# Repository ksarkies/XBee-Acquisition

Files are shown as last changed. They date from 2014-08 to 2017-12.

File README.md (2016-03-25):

XBee Data Acquisition
---------------------

This project develops a remote data collection board, primarily aimed at a
specific water flow meter. The board communicates collected counts of optical
transitions from a rotating slotted wheel, over an XBee network to a master
processing point. The remote unit includes a bootloader for remote upload of
new firmware.

The challenge with this project is to reduce power consumption to a minimum
to extend the life of the batteries, which may be difficult to access for
recharge in practice.

In addition to the board design and firmware, a number of tools are provided
to manage the network and collect data using Linux based hardware. These include
an acquisition coordination process that is intended to run on a small headless
Linux box such as a Raspberry Pi or BeagleBone. This manages the network and
connects to a user interface program running either on the same machine or
at another location. It uses a TCP/IP sockets interface that will allow remote
connections over the Internet.

A number of test and debug firmwares are available as well as schematics for
prototyping boards used as test nodes.

Subdirectories:

* **Documentation**:           A set of documents relevant to design and implementation.

* **gEDA-XBee-Test**:          Schematics for prototype boards for testing purposes.

* **Kicad-Main**:              Schematic and PCB for watermeter unit main board.

* **Kicad-Mounts**:            Schematic and PCB for XBee and LED mount boards.

* **watermeter-test**:         Firmware for the remote unit ATTiny481, in C, for use
 with flow bench testing over a serial interface. XBee is not used.

* **XBee-acqcontrol**:         Control software for the coordinator; in C++.

* **XBee-bootloader-M168**:    Bootloader for a remote unit with ATMega168.

* **XBee-experimental-T4313**: Bootloader for a remote unit with ATTiny4313.

* **XBee-firmware**:           Firmware for the remote unit ATTiny481, in C.

* **XBee-firmware-NARTOS**:    Firmware for remote unit ATTiny481 using the NARTOS
scheduler.

* **XBee-GUI**:                Linux PC based GUI for network control; C++ and QT.

* **XBee-node-example-M168**:  Example to send dummy message via XBee for testing.

* **XBee-utility**:            Some tools for direct interaction with XBee over a
serial interface.

K. Sarkies
29 January 2016

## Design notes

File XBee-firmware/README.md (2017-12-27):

XBee Data Acquisition Remote Firmware
-------------------------------------

This is the firmware for the remote unit. Written in C under avr-gcc.

The unit must use the lowest possible power drain, so the XBee is turned off
when not communicating, and the AVR is placed in power down sleep, to be woken
when a counter event occurs or at regular intervals for communication with the
base station.

Tasks are:

1. Manage sleep timing using the WDT.
2. Debounce and count pulses.
3. Transmit count and battery voltage.
4. Request any pending configuration instructions from the master.

The code uses an error checking protocol to ensure that data is transmitted
reliably. When woken by the WDT, it transmits the watermeter count and waits
for an acknowledgement with a checksum of its transmitted data. If no response
comes, or a response in error, or the base station reports an error, it will
repeat the transmission up to three times before giving up. Only when no errors
have been detected will it reset the watermeter count. The base station is
responsible for its own involvement in this protocol.

Provision is made for the base station to send commands to change
parameters in the remote unit. This must be sent BEFORE the acknowledgement
otherwise the remote unit will return to sleep once it has received a good
response.

The code is written to allow several AVR microcontroller types and currently
supports ATMega168, ATTiny4313 and ATTiny841, the latter being the one selected
for the watermeter.

Open source versions of avr-libc earlier than release 2.0.0 did not support the
ATTiny841 series. To get around this, either compile and install the latest
version of avr-libc, or place the latest Atmel toolchain into a directory
somewhere where it can be referenced in the Makefile. Change the DIRAVR
environment variable in Makefile to suit the location chosen.

The XBee does not use hardware flow control, although RTS may be
possible. This is due to a lack of ports on the AVR package intended for use
(ATTiny841).

**NOTE (1):** CTS should be set in the XBee and USE_HARDWARE_FLOW also enabled when
using the ATMega48 series based test boards.

**NOTE (2):** The following ports on the XBee must be set as follows:
* For the watermeter board, set pullups as 457 and pins as:
pin 4 (DIO12) output high,
pin 7 (DIO11) output low,
pins 6 (DIO10), 11 (DIO4), 16 (DIO6), 17 (DIO3), 18 (DIO2) disabled with pullup,
pin 9 Sleep_RQ input without pullup,
pin 15 Associate output,
pin 19 (AD1) analogue input without pullup,
pin 20 Commissioning output.
* For the Node Test Board, set pullups as 453 and pins as:
pin 4 (DIO12) output high,
pin 7 (DIO11) output low,
pins 6 (DIO10), 11 (DIO4), 17 (DIO3) disabled with pullup,
pin 9 Sleep_RQ input without pullup,
pin 12 CTS output,
pin 15 Associate output,
pin 16 RTS input with pullup, 
pins 18, 19 analogue input without pullup,
pin 20 Commissioning output.

The AVR is set to 1MHz for low power, and a baud rate of 9600, aimed at
giving sufficient time for processing messages.

The MCU variable defaults to the attiny841 but other versions can be passed to
the makefile:

make MCU=xxx

where xxx is either attiny841, attiny4313 or atmega168.

The makefile may need to be changed for other AVR types to adjust for
differences, and a new defines file placed in the lib directory. The makefile
creates an integer variable MCU_TYPE, derived from the MCU variable, (see the
makefile) and passes it to the source files. This variable must then be used in
the defines.h header to incorporate the appropriate MCU specific defines file.

K. Sarkies
28 November 2014

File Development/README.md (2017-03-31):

Development Modules
-------------------

All code and PCB modules used for testing at various points in the development
process is provided here. Some of these will become parts of a testbed if
production proceeds.

1. **gEDA-XBee-Test**. Circuit board schematics for prototype test versions of
   XBee remote nodes.

2. **Kicad-XBee-Test**. Circuit board schematics for the PCB version of the XBee
   remote node.

3. **socket-test**. Something to do with TCP/IP sockets for the external
   interface to the base station.

4. **watermeter-count-test**. Transmits the count at 1 sec intervals via the
   serial port in csv format. XBee not used.

5. **watermeter-echo-test**. Basic test echoes characters back on the serial
   port.

6. **XBee-bootloader-M168**. Attempt at bootloader for ATMega168 series.

7. **XBee-experimental-T4313**. Attempt at bootloader for ATTiny4313 plus early
   version of XBee code as for the XBee-node-test.

8. **XBee-firmware-nartos**. Early attempt to use a tiny scheduler for managing
   the communication protocol. Not working at this stage and probably will be
   obsoleted.

9. **XBee-node-test**. A test firmware for the ATTiny841/ATMega168 to send
   counts and battery voltage via the XBee at timed intervals.

10. **XBee-node-test-pc**. This is POSIX software to allow testing of the full
   firmware core behaviour (without any microcontroller specific hardware
   operations) aimed at verification of communications protocol in the final
   watermeter firmware.

11. **XBee-node-test-sleep**. A test firmware for the ATTiny841/ATMega168 to
   XBee send counts via the at timed intervals using sleep modes in the AVR.

K. Sarkies
19 April 2015

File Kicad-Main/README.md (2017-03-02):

XBee Data Acquisition PCB
-------------------------

Refer to [Kicad-setup](https://github.com/ksarkies/XBee-Acquisition/blob/master/Documentation/Kicad-Setup.md) in the Documentation directory for usage information.

PCB for a remote unit, including XBee with battery monitor and photodiode
counter. A major requirement for this circuit is ultra-low power to allow the
selected batteries to last for over a year.

The PCB is intended to fit inside a cylindrical watermeter with the batteries.
Due to space constraints the XBee is mounted on a separate board that sits at
right angles to the PCB. The XBee connects to an external aerial through an RF
cable. For measurement of battery voltage, a switched divider circuit is
provided for the case that the batteries provide a higher voltage than the
circuit power supply (which is sourced via a 3.3V voltage regulator). The LED is
mounted on a separate board that will straddle an interrupter wheel for counting
revolutions of the meter.

The board has a 12-pin debug connector for testing purposes:

1. Battery power or board power (if a battery is present take extreme care not
to short or connect any other power source).
2. Count signal from board comparator.
3. Reset for microcontroller.
4. MOSI microcontroller programming pin.
5. SCK microcontroller programming pin.
6. MISO microcontroller programming pin.
7. Tx from microcontroller to XBee Rx (monitor this only unless XBee is removed).
8. Rx to microcontroller from XBee Tx (monitor this only unless XBee is removed).
9. Association Signal from XBee. Blinks at 2Hz when connected to the network.
10. On/Sleep (high if XBee is awake, low if asleep).
11. Commissioning input to XBee, requiring a pushbutton to ground.
12. Ground.

The microcontroller has the following I/O pin allocations:

* PA0 (in) XBee Asleep (inv)
* PA1 (out) Tx to XBee
* PA2 (in) Rx to XBee
* PA3 (out) Sleep Request
* PA4 (in) SCK
* PA5 (in) MISO
* PA6 (out) MOSI
* PA7 (out) Battery Monitor Control
* PB0 (in) Bootloader Enable
* PB1 (in) Board Digital Input
* PB2 (out) XBee Reset (inv)

The battery monitor voltage is passed directly to the XBee as the ATTiny841 has
insufficient pins.

The TPS77033 symbol from KB1LQC.lib at Rochester Institute of technology
(http://edge.rit.edu/edge/P13271/public/KiCad/Libraries).

A photodiode symbol was taken from
(http://vkoeppel.free.fr/files/diy/kicad_diy_libraries.zip)

Other symbols and footprints are custom or are provided by KiCad developers.

The provided Photodiode.pretty footprint library should contain all necessary
footprints. Copy any legacy footprints into the modules directory, and any
external footprints into Photodiode.pretty to avoid problems of obsolescence. In
CvPcb go to "Library Tables", then select the tab "Project Specific Libraries".
Append a new entry, add the library path (including the name of the .mod file),
choosing "Legacy" for the plugin type. The nickname will then appear in the main
listing of CvPcb and the library footprints should appear. If a mistake is made,
no footprints will show, but no error message will be given until CvPcb is
restarted.

A custom footprint S1133 is provided for the S1133 photodiode. This has a
truncated circular form 8mm diameter with 6mm across the truncation, and through
hole pins. In CvPcb append a new KiCad entry and add the library path to the
.pretty directory (not the file, which is a single footprint). Also included
are some 2mm pin spacing header footprints.

The production version of the board has a custom footprint for the debug
connector to allow the option of using an SMD form. Also the photodiode is now
a BPW34 which can be either SMD or through hole mounted below the board, or a
reverse form mounted on top of the board over the square hole. The latter choice
avoids possible interference with mechanical parts in the space under the board.

The [node test firmware](https://github.com/ksarkies/XBee-Acquisition/tree/master/Development/XBee-node-test) is provided for test transmissions.

The [firmware](https://github.com/ksarkies/XBee-Acquisition/tree/master/XBee-firmware) is provided for full protocol transmissions.

Firmware must be compiled for MCU=attiny841 or whichever processor is used.

The firmware README provides instructions for setting up the XBee configuration.

* 27 November 2014: Add missing ground points. Correct error in battery voltage
  circuit.
* 24 February 2016: Changed position of connectors to avoid housing structures.
* 11 April 2016: Production version with additional XBee signals brought out to
  the debug connector which is now 12 pin.
* 12 February 2017: Corrections to the battery monitor circuit.

K. Sarkies
11 April 2016

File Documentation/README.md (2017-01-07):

**Assembly and Testing**
----------------------

1. The following procedures and tests should be carried out during or following assembly of the boards.
2. Add a blob of solder to one pin of the device to be soldered. Holding the device with tweezers, carefully melt the solder and push the device against the pad. Adjust the position of the device until all pins line up with the respective pads, leaving space on the pad for the solder to flow. Solder another pad on the opposite end of the device. Then solder in all the remaining pins.
3. On the main board solder all the passive components in the power circuit, the regulator and the debug connector. Connect to the testboard via the 12 pin cable. Connect 6V-12V power and check for 3.3V at the electrolytic capacitor, the IC power pins and at the analogue optical circuit.
4. Solder in the op-amp. This needs to be done before the AVR as the presence of the debug connector and AVR will hinder it's insertion.
5. Solder in the AVR. Connect an AVR programmer to the testboard via the 6-pin cable. Connect 6V to 12V power to the testboard (**not the programmer** otherwise the CPU on the meter board can be damaged). See the image below. This will provide 12V power to the watermeter assembly and 5V power to the programmer. Note that the programmer has 220Ω protection resistors to allow the target to have a lower supply voltage.
6. Connect the RS232 serial port on the programmer to a PC. If a serial PC port is used, invoke the program “avrserialprog -P /dev/ttyS0 -b 38400” to activate the GUI. If a USB to serial adapter is used, the port will need to be changed to /dev/ttyUSB0 (or whatever port on which the adapter appears). Check that the programmer identifies the device as an ATTiny841.
7. In the GUI click on “Lock/Fuse”, and in the window untick “Divide Clock by 8”. Ensure that the “Clock Source Selection” bits read 0010 (where 0 means unticked and 1 means ticked). Click on “Write FBs”. Do not change the clock bits to any other setting as it will risk making the AVR and hence the board unusable. This provides an internal calibrated 8MHz clock used in all tests and operational states. The 1MHz divided clock rate will not support the serial baud rate needed. Close the application and relaunch. Check that the fuse setting has indeed been changed.
8. In the optical circuit solder the passive components, the BJT and the photodiode onto the top of the board looking through. The cathode is the wide pin on the BPW-34S and this is mounted on the side facing the outer rim of the board.
9. Solder the LED mount board with the LED, and the 3-pin socket under the main board. The SFH4056 has a marking on the back with the wide end being the cathode. Mount with the narrow end, the anode, facing the pins. Place three individual pins in the 3-pin socket and solder the ends to the LED board. Check that the optical circuit produces a signal at the testboard count pin with the slotted wheel spinning and the watermeter assembly mounted in a darkened housing.
10. **The following must not be carried out if the XBee is present in the watermeter assembly as it can damage the XBee serial ports.**
    * Locate the watermeter-echo-test firmware and upload to the AVR using “avrserialprog -n -P /dev/ttyS0 -b -w 38400 watermeter-echo-test.hex -v” or through the GUI. Link the W3 jumper on the testboard. Using a serial port monitor (e.g.putty) set to the 9600 baud rate, enter characters and verify that they are echoed back to the terminal.
    * Locate the watermeter-count-test firmware and upload to the AVR using “avrserialprog -n -P /dev/ttyS0 -b -w 38400 watermeter-count-test.hex -v” or through the GUI. Link the W3 jumper on the testboard. Attach the LED board and a slotted wheel and place in a darkened housing. Using a serial port monitor (e.g. putty) set to the 9600 baud rate, spin the slotted wheel and verify that consistent counts are being transmitted by the AVR.

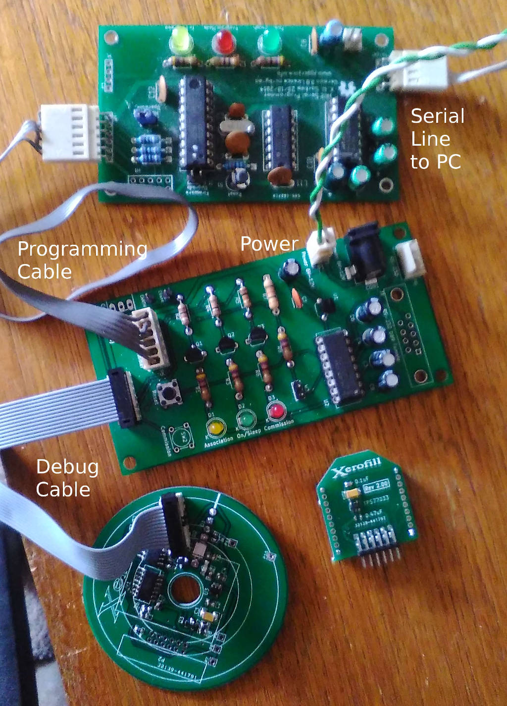
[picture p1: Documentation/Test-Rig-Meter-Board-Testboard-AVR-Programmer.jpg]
"Setup of test rig"


K. Sarkies, 07 January 2017

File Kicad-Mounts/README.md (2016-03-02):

XBee Data Acquisition XBee/LED Mountings
----------------------------------------

Refer to [Kicad-setup](https://github.com/ksarkies/XBee-Acquisition/blob/master/Documentation/Kicad-Setup.md) in the Documentation directory for usage information.

TDB: At this time the PCB has missing footprints.

This board provides a mounting PCB for the LED and a mounting PCB for the XBee
with matching connector for right-angle mount to the main PCB.

An XBee footprint was taken from RF_OEM_PARTS.lib and footprints.mod in Ian
McInerney's library (https://github.com/imciner2/KiCad-Libraries)
The legacy footprint has been modified to the newer kicad_mod format and solder
mask has been added to the pads.

The LED mount provides for two LEDs VSMY2850 and SFH4056 reverse mounted (under
the board and facing through a cutout) and a top mounted LED SFH4258.

Other symbols and footprints are provided by KiCad developers.

27 November 2014: Flip XBee over, adjust XBee footprint, reduce size the of the
                  two boards, interchange Rx and Tx.

A separate regulated supply was added to provide 3.3V power for the XBee as the
XBee can pull a relatively heavy current pulse on transmission.

K. Sarkies
19 February 2016

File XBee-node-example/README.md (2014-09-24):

XBee Data Acquisition Remote Firmware Example
---------------------------------------------

This is an example firmware for the remote unit. Written in C under avr-gcc.
The node hardware is based on the ATMega168. The hardware is defined in
gEDA-XBee/xbee-node-atmega48.sch

A dummy message is sent to the coordinator at timed intervals and PORTB0 is
toggled in the timer ISR.

The code is written to permit use of other microcontroller types and currently
also supports ATTiny4313.

The MCU variable is passed to the source in various places to allow:

make MCU=xxx

where xxx is either attiny4313 or atmega168.

The makefile needs to be changed for other AVR types to adjust for differences.
A separate defines-xxx.h file needs to be incorporated.

Currently optimization level 1 only works with this code. Other optimization
levels create faulty code.

K. Sarkies
24 September 2014

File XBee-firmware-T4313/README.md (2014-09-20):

XBee Data Acquisition Remote Firmware
-------------------------------------

This is the firmware for the remote unit. Written in C under avr-gcc.
The node hardware is based on the ATTiny4313 and is defined in
gEDA-XBee/xbee-node-attiny4313.sch

Tasks are:

1. Manage sleep timing using the WDT.
2. Count pulses: ISR and debounce procedure.
3. Transmit count, time, duration and battery voltage.
4. Request any pending configuration instructions from the master.
5. Sleep.

defines.h and makefile need to be changed to reflect differences in the
different microcontroller types.

K. Sarkies
20 September 2014

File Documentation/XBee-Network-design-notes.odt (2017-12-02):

24 May 2017

# Introduction

This describes a project to build a support base for a data acquisition network in which the communication between nodes of the network uses XBee devices in Zigbee mode.

The document describes the various design parameters and decisions, and documents the protocols and interfaces between components.

The concept involves a Linux based coordinator processor, referred to as the base station, intended to be a small headless platform such as the Raspberry Pi, BeagleBone or similar. By means of a background base station process this provides a control, configuration and collection point for incoming data via an attached an XBee in coordinator mode. It also provides a network interface to a Linux, OS/X or Windows based user interface program on the same or different machine.

The remote nodes provide the data acquisition facilities. The remote nodes can be of two types: XBee end devices and XBee routers. The latter must be always on and powered with an uninterruptible supply, while the former may be battery operated and use sleep states extensively to conserve power. As the XBee is capable of performing a small number of analogue measurements and provides basic digital I/O, it can operate as a standalone device. Alternatively, and preferably for flexibility, it can operate in conjunction with a small microcontroller. The latter configuration has a number of advantages in that each can monitor the other and provide some additional fault recovery functionality, such as remote reset, firmware uploads for the microcontroller, watchdog timer reset and remote configuration of the XBee.

Most remote nodes will use battery operation and thus they will make use of various XBee sleep states. Most modern microcontrollers can also use sleep states. As the microcontroller is likely to wake from sleep on various local events, it can also wake the XBee when transmission is required.

A number of items of software are developed for this work:

1. Base station program for monitoring, data collection and buffering, and interface to an external control program.
2. Data acquisition and control firmware for the remote node microcontroller.
3. Bootloader for the remote node microcontroller to allow firmware uploads.
4. External GUI program for connection to the base station over the Internet or local LAN, for monitoring, control and data access.

The remote node for the watermeter is described in another document.

# Xbee Setup

The XBee can be setup initially with the Digi X-CTU tool. This is available for Windows, OS/X and Linux http://www.digi.com/products/xbee-rf-solutions/xctu-software/xctu.

In Linux, the downloaded file has a .run suffix. Make executable and execute as root, eg

$ chmod +x 40002881_B.run

$ sudo ./40002881_B.run

If it is installed to the default directory /opt/Digi/, it can be run as:

$ /opt/Digi/XCTU-NG/app

Also change the ownership of the /opt/Digi/XCTU-NG/ directory and its contents to the current user.

Connect an XBee to a USB port. It will normally then appear as /dev/ttyUSB0 (although the number will be higher if other devices or disk drives have already been attached). Perform a search for the attached XBee. If not found, widen the search to different serial settings. The XBee cannot communicate its serial settings so a search must be done.

When the XBee is found, click on its entry to read all parameters. These can be changed and written back to the XBee. To change the XBee type, new firmware must be loaded.

Some debug information is available at the bottom of the parameters screen. This can indicate reasons for the XBee not joining the network for example.

## Network Setup

1. If the XBees have been set with the correct network parameters as described below, install the coordinator on a PC with X-CTU installed. Check that it is recognised and the parameters are correct. The coordinator should have
2. Connect the router Xbees to a suitable power source. Each of these should start up (connect to the network) after a few seconds. If LEDs are present, the “associate” LED (pin 15) should blink at a rate twice per second once the XBee has joined the network.
3. In X-CTU clink on the “Discover Radio Nodes” button for the coordinator entry. All nodes should be found.

## XBee Settings

These are the settings available from the X-CTU tool.

The network PAN ID is selected as 55 for this system. This is set in all XBees to be used in the network.

### Sleep Time

The coordinator and routers are set to never sleep. These must always be powered on by an uninterruptible power source. The end devices are required to sleep to conserve battery power, and cannot be set to never sleep. They may be woken from sleep via the SLEEP_RQ pin being pulsed high then low.

The sleep time setting in the coordinator and routers refers to the maximum time that end devices are expected to sleep. If an end device does not respond during this time it is purged from the list of child devices. The setting therefore must be a larger value than the end device sleep setting to ensure that the end device remains in the child table and is not expired. Any end point should wake at least once per day.

The sleep setting in end devices will be pin hibernate or cyclic sleep plus pin wake. For power reduction the sleep time must be as long as possible. For safety the cyclic sleep setting plus pin wake should be used to ensure the XBee wakes up regularly to refresh the network connectivity. The sleep options are set to allow a sleep holdoff time to be defined and to enable extended sleeping.

The maximum wake period can be set to 65 seconds. The maximum cyclic sleep setting can be set to 28 seconds multiplied by an integer that can be as high as 65535 (32 days).

When the end device XBee wakes, an setting can be used to allow it to remain awake for a fixed period to allow remote devices and processes to send any pending messages. The end device XBee must receive and respond to these messages before sleeping. The setting only applies to cyclic sleep mode and not for pin sleep mode, although it appears to be active for pin wake when pin plus cyclic sleep mode is used.

### Router

- NJ – Node join time. If less than FF the device assumes the network doesn't allow joining and attempts to rejoin. This allows it to join a network with the same PAN ID. If this fails, or NJ is FF, it joins by association.
- PAN ID – set to the selected PAN ID of the coordinator. If set to zero, the XBee will pick up the PAN ID from the coordinator (as long as only one coordinator is around).
- NW = 1. Network Watchdog Timeout in minutes to cause the XBee to check for a coordinator and leave if not found (0 is disabled). This is normally set to a higher value.
- JV = 1. Channel verification causes the XBee router to check for a coordinator on power up and search for one if not found.
- JN = 1. Join notification causes the XBee to send a node identifier packet on power up. This is needed to ensure it is entered into the software table.
- BD = 5. Set the baud rate to 38400.
- D7 = 1 Enable CTS flow control.
- D6 = 1 Enable RTS flow control.
- AP = 1 Use API mode without break characters.
- SM = 0. Set the sleep mode to disable.
- SP = 0xAF0. Set the sleep period to the maximum 28 seconds.
- SN = 0xB60. Cyclic sleep periods, up to FFFF. Set to just over 1 day.
- PR = 0x1FBF. Set the pullup resistors to exclude CTS (which is an output) and SLEEP_RQ which needs an external pull down of large value.

### End Point

- PAN ID – set to the selected PAN ID of the coordinator. If set to zero, the XBee will pick up the PAN ID from the coordinator (as long as only one coordinator is around).
- NJ – Node join time. If less than FF the device assumes the network doesn't allow joining and attempts to rejoin. This allows it to join a network with the same PAN ID. If this fails, or NJ is FF, it joins by association.
- NW = 1. Network Watchdog Timeout in minutes to cause the XBee to check for a coordinator and leave if not found (0 is disabled). This is normally set to a higher value.
- JN = 1. Join notification causes the XBee to send a node identifier packet on power up. This is needed to ensure it is entered into the software table.
- MP – Parent address (0 for coordinator, or address of router).
- NT – Node discovery backoff time (3C about 6 seconds).
- NO – Node discovery options (3).
- BD = 5. Set the baud rate to 38400.
- D7 = 1 Enable CTS flow control.
- D6 = 1 Enable RTS flow control.
- AP = 1 Use API mode without break characters.
- SM = 5. Set the sleep mode to cyclic sleep plus pin wake.
- SP = 0xAF0. Set the sleep period to the maximum 28 seconds.
- SN = 0xB40. Cyclic sleep periods, up to FFFF. Set to about 1 day.
- ST = 0x1F4. Set the sleep holdoff time to 0.5 seconds. Only for cyclic sleep.
- SO = 6. Enable extended sleep (4) and sleep for full ST time (2).
- PR = 0x1FBF. Set the pullup resistors to exclude CTS (which is an output) and SLEEP_RQ which needs an external pull down of large value.

### Coordinator

- ID – set to the selected 16 bit PAN ID. If set to zero, the XBee will pick a random number.
- SC – Scan channels bitmask for up to 16 channels. Coordinator will select a channel when forming the network. Defaults to FFFF.
- SD – Scan duration. How long the coordinator spends scanning for PAN ID or energy scan. The setting is an exponent (3) in units of 15.3ms per channel.
- ZS – Zigbee stack profile. Same on all devices on the network. This is related to specialised applications. Normally set to 0.
- NJ – Node join time. Time allowed for remote nodes to join. If set to FF it will have no time limit. After the limit has expired, remote nodes are unable to rejoin until the coordinator is reset or NJ is changed.
- OP – Operating PAN ID (should match the nonzero value in ID).
- OI – Operating 16 bit PAN ID.
- CH – Operating channel.
- NC – Number of children remaining (routers and end-points directly accessing the coordinator).
- SH, SL – Serial Number high and low.
- MY – 16 bit network address (0 for coordinator).
- DH, DL – Destination address (0000 FFFF for coordinator).
- NI – Node identifier ASCII name.
- NH – Maximum number of hops. Default 1E is about 1.6 seconds, 8 hops
- BH – Broadcast radius. For maximum number of hops set to 0.
- AR – Aggregate routing notification. Time between consecutive aggregate broadcasts.
- DD – Device type identifier (30000).
- NT – Node discovery backoff time (FF).
- NO – Node discovery options (3).
- NP – Maximum number of RF payload bytes (FF).
- CR – PAN conflict threshold (3). Not mentioned in documentation.
- BD = 5. Set the baud rate to 38400.
- D7 = 1 Enable CTS flow control.
- D6 = 1 Enable RTS flow control.
- AP = 1 Use API mode without break characters.
- SM = 0. Set the sleep mode to disable.
- SP = 0xAF0. Set the sleep period to the maximum 28 seconds.
- SN = 0xB60. Cyclic sleep periods, up to FFFF. Set to just over 1 day.
- PR = 0x1FBF. Set the pullup resistors to exclude CTS (which is an output) and SLEEP_RQ which needs an external pull down of large value.

## Unbrick XBee

The Xbees are XB24-ZB product family. To force a firmware update, use an interface board with a reset button.

1. Go to "Tools – XBee Recovery",
2. Select interface and modem type from list,
3. Select function set and firmware version,
4. Click on the "Recover" button. After a few seconds of trying to read the modem, you will get an Info box that says Action Needed. Reset the modem using the reset button on the interface board.

# Base Station

The base station processor being used for this project may be almost any Linux based PC or processor board. This interfaces to the local WiFi or Ethernet LAN to allow external control and data transmission. It may use a HDD or SD card for data buffering.

The base station is attached to the coordinator XBee.

## Configuration

The configuration of the base station processor depends rather on its hardware features. A full PC needs little configuration as it will be able to respond to almost any load demand from the network. A small processor board however may need some work to improve performance.

## Software

It is intended that the processor be set to start a background monitoring process to control the network, gather incoming data, pass it to storage buffers and interact with an Internet GUI control and display program. The program is written in C and uses libxbee3 by Attie Grande for XBee support.

The program starts by querying all nodes on the network and building a table of information for each one, including libxbee connections to allow reception of data streams from the device.

The program also sets up an Internet TCP port 58532 for connection externally by a user interface program.

The requirements for the program are:

1. On startup, initialise an Internet socket for attachment by an external user interface program. This socket shall listen on TCP port 58532.
2. For each remote node in the table, make a data connection on which incoming data for each remote node will be received.
3. Create an “Identify” connection to receive identification packets from remote nodes when they power on or join the network. Note: all stand-alone XBee nodes should have the Join Notification setting enabled to allow new nodes to identify themselves to the network. The software in the remote node microcontroller shall force the sending of the Identify packet when powering up.
4. Send out an XBee Node Discovery command via the attached coordinator XBee to query all remote nodes in the network. From the responses build a table of node information.
5. On receiving Identify packets the program shall check against the existing table and add the remote node if it is not already present.
6. Interact with the remote node via data connections, to retrieve and store transmitted data using a reliable application level protocol (see section on communication below).

## Structure

The libraries libxbee3 provide for callback functions to be invoked to deal with various message types from the XBee.

- nodeIDCallback. Callback for the ND and Identify command, to load up the node list. It is invoked when an identify packet is received. This checks for existence of the node information and adds a new node if not present. Data, I/O and AT command connections are added. If a device powers off and back on again it will be dealt with adequately by this callback. Connections are only added if the entry is not valid or is a new entry.
- dataCallback. This interprets incoming packets on the remote node data connection, and for process data passes it on to an external file. Other packets are responses to commands to the node AVR sent over the same connection. The response is stored in a global array. This should be read before any other node AVR command is sent to any node.

## Command Line Interface

When invoking the program on the base station machine, the following options are available:

-D directory to store results file (default /data/XBee).

-P port (default is /dev/ttyUSB0).

-b baudrate (default 38400 baud).

-d debug mode, printing out actions as they occur to standard output. Same as -e 1

-e enhanced debug mode: level 0=none, 1=basic, 2=enhanced.

-L starts logging and sets the logging level as used in libxbee (see relevant documents).

The program when run with the debug option will announce the results filename. The default filename will be time-stamped, but this can be overriden by the above command line option. It will then loop waiting for communication from the network. Debug information is written to /var/log/syslog.

## Internet Interface

Commands received over the Internet connection from an external user interface program have the following format:

1-byte length of message, 1-character command, 1-byte row number, arbitrary parameters (0-255 bytes)

For transmission to remote nodes, the row number points to a table entry with the node information and connections.

The commands (n represents the remote node's row number and x any parameters) are:

- Lx - send a local AT command x plus its parameters to the attached coordinator XBee.
- l - ask for any response returned by the remote node to an L command on the data connection. A value of zero returned as the first character indicates that a response had not been received. The first character of a valid response will be an ASCII 'L' to indicate that a response was received.
- Rnx - send a remote AT command plus its parameters x to the remote node n.
- r - ask for any response returned by the remote node to an R command on the data connection. A value of zero returned as the first character indicates that a response had not been received. The first character of a valid response will be an ASCII 'R' to indicate that a response was received.
- Snx - send a string x to the remote node n over its data connection.
- s - ask for any response returned by the remote node to an S command on the data connection. A value of zero returned as the first character indicates that a response had not been received within a given time. The first character of a valid response will be an ASCII 'S' to indicate that a response was received.
- N - return the number of rows in the table
- In - return the textual and numerical information in the node entry n.
- X – close down the XBee network and, after a 20 second delay, restart it. This has presented a number of issues with remote nodes not being recognised, and is not recommended to be used.
- Qn – close down the selected remote node n data, I/O and command connections, and rebuild them.
- Dn – Delete a selected remote node n from the node table.
- Ex – Create a new entry in the node table with the given 64 bit address x.
- Dn – Delete a selected remote node n from the node table.

The convention used for the commands is upper case letters to represent a direct command and a lower case letter used to request any response.

# Remote Nodes

These devices shall use sleep modes to reduce power drain to a minimum. The XBee can be placed in “pin sleep” and await the microcontroller action on a specific pin to wake it up. Alternately it can be made to wake periodically so that in the event of a non-responding microcontroller, it can force the latter to be reset. The microcontroller can also force a hardware reset on the XBee if the latter fails to respond. The microcontroller shall be placed in a sleep mode also.

## Sleep Modes

The XBee shall be set to Sleep Mode 1 (pin sleep). This allows the XBee to sleep until awoken by the action of the SLEEP_RQ pin, controlled by the microcontroller.

Note the controller and all routers must have their sleep options set to the same value or greater to ensure they retain end device messages until the latter awakes. These sleep options refer to the time allowed for end devices to remain asleep (the coordinator and routers never sleep).

The microcontroller shall be placed in sleep mode until data becomes available or until the XBee wakes it. The XBee ON/SLEEP output can be used to a wakeup the microcontroller. An AVR microcontroller shall use the power save sleep mode if the timer/counter is to be used, otherwise power down mode shall be used. Both can be woken with a pin change interrupt.

### Configuration

When configuration of the XBee is to be done, a message shall be sent to the XBee to perform the appropriate action. This must occur when the XBee is woken by the remote node microcontroller.

To account for the case where the AVR hasn't been given the ability to change the XBee sleep state, an XBee command will need to be sent by the controller to change the sleep mode to pin sleep. The XBee will then need to have its SLEEP_RQ pin grounded to ensure that it remains awake indefinitely in this mode. The XBee end devices cannot be set to remain permanently on, and must use one of the sleep modes.

### Bootloader

The need to reset the AVR when activating the bootloader results in the SLEEP_RQ pin of the XBee being forced high during the reset, as all I/O ports on the AVR are changed to inputs. This puts the XBee to sleep and cuts off communication. To overcome this, a 1M or larger resistor is used as a pull-down and the pull-up on the XBee SLEEP_RQ pin is disabled.

# Communication Protocols

On top of the Xbee networking protocol is needed a specific application protocol to communicate between the remote node microcontroller and the base station process. This shall be done by means of a command/response mechanism consisting of a command or response code word possibly followed by data. A code word that doesn't belong to the following list shall result in an error response.

The protocol shall consist of an ASCII command character followed by a string of ASCII hexadecimal characters representing numerical data, or other ASCII characters representing non-numerical data.

## Bootloader

The following commands apply to interaction with the bootloader only.

- : (semicolon). The following data shall be a single record of iHex formatted hexadecimal characters, pairs of which represent a data byte, and having maximum length 16 data bytes. The record types 00 and 01 (end of file) are recognised. Error responses include invalid hex character, checksum, record length and record type.
- Q. Quit the bootloader and enter application program at address zero.
- X. Erase all application memory.

Responses

- Y no error.
- E unspecified error response.
- B out of bounds (bootloader has been asked to write over itself).
- L invalid iHex record length
- H invalid hexadecimal character
- X invalid checksum
- I invalid command (including invalid data where appropriate)
- J a jump to the application has been made from the bootloader.

## Base Station to Remote Node Interactions

As specified above, in the remote node, both the microcontroller and the XBee will sleep. The microcontroller will wake at intervals and will then wake the XBee to check for waiting messages and to send data. Regardless of any data to be sent the base station must receive a message from the remote node and respond. Then the remote node may return to sleep.

For safety the remote node must wait for a limited period of time for a response, and resend the message if no response has been received. The following protocol shall be followed to improve the reliability of communication in the presence of possible errors.

If no response has been received, then the remote node may check the XBee for valid status, to determine if it is still joined to the network. If not, then the XBee shall be restarted. Otherwise the remote node shall return to sleep on the assumption that the network is not responding. Accumulated data shall be retained for subsequent attempts.

## Data Transfer Protocol

A reliable protocol is required to ensure that the collected data is transferred accurately to the system.

If data is transferred correctly, then the old data must be cleared to make room for a new set.

### Protocol

Successful error recovery requires careful design. However it is not possible to anticipate all possible errors. These can arise from corruptions in the communications at the Xbee-AVR interface, or in the XBee network itself.

The protocol in summary is as follows. More detail is given in the flowcharts.

- When the XBee is ready to send, wake up and send a contact message with the collected data and a checksum.
- Receive an acknowledgement, or negative acknowledgement if data was received in error by the base station.
- If timeout, repeat the contact message until the acknowledgement is received or until three attempts have failed.
- If any other error occurs, resend the data message up to three times.
- On failure send a signal to indicate that the results should be discarded.
- On success, reset the data and send a signal to store the result.

The length of the data field can be inferred from the message length. All fields shall consist of printable ASCII characters for readability and error checking. Because of limited memory in the AVR, the messages shall have limited length.

If the remote gives up, then it shall send a final message stating that it is giving up and will not reset the count. The base station shall discard the result if it has not received a definite acknowledgement. This protocol will never guarantee that data will not be lost, but will cover most situations.

### Message types

The messages from the XBee contain the data to be sent. xx represents checksum, aa represents data:

1. 'C' xx xx aa aa … (11 bytes) Original message with application data.
2. 'E' xx xx aa aa … (11 bytes) Repeat message in response to reception errors.
3. 'N' xx xx aa aa … (11 bytes) Repeat message in response to a NAK.
4. 'T' xx xx aa aa … (11 bytes) Repeat message in response to a timeout.
5. 'S' xx xx aa aa … (11 bytes) Repeat message in response to a status frame.
6. 'X' (1 byte) Remote will abandon the communication attempt.
7. 'A' (1 byte) Remote agrees that the communication is successful.
8. 'D' aa aa … (unlimited bytes) Debug message.

The messages from the system to the XBee are:

1. Acknowledgement: 'A' (1 byte).
2. Negative acknowledgement: 'N' (1 byte).
3. Parameter change command: 'P' aa aa ... (n+1 bytes).
4. Keep awake until further notice: 'W'.
5. Sleep: 'S'.

Any additional commands to the XBee must not use 'X' or 'N' as these will be confused with the ACK and NAK messages.

## Parameter Change Command

If a parameter change operation is required, the parameter change command must be transmitted by the base station immediately after the reception of the data command. This will ensure that the operation takes place before the remote node returns to sleep.

The remote node must respond with an acknowledgement of the parameter change command.

## External Interface

The best place for the external interface is in the base station. Data can be collected during the message exchange and stored ready to pass to an external PC. All that is needed for configuration is the way that data is stored for each sensor.

Data storage shall be made firstly in a global data structure that contains only one result for each of the remotes in the network. Following a signal from a remote that the data transmission is successful, the result will be written to a permanent data file. The temporarily stored datum will be overwritten by subsequent transmissions, therefore if the acknowledgement was not received from the remote, the datum would be lost. To avoid this loss, the old datum shall be written to the file with a marker indicating that its status is dubious.

# Software Development

## Base Station

The base station program is intended to be run on a Linux machine which can range from a single card computer such as the Raspberry Pi to a full PC. Most likely a low to medium range PC can be used as the performance demands would not be very great.

The base station program is not intended to interface to a user. Rather it communicates via an Internet socket with an external user program such as the XBee-GUI program described below.

The program is developed in C and uses only standard POSIX libraries plus the libxbee libraries created by Attie Grande. The latter must be installed in a suitable location and compiled to produce a libxbee.a archive file. If the system install procedure has not been used as described in the libxbee documentation, then libxbee.a must be copied along with the xbee.h file to the base station program source directory. The base station program can then be compiled using “make” to produce a xbee-acqcontrol executable.

When the xbee-acqcontrol program is run from the command line, it produces a one-line output and then waits for responses from the Xbee network and the user interface program. Error messages are printed to the /var/log/syslog file, labelled clearly as originating from the base station program. Typical errors that cause the program to end prematurely might be unable to open a file for printing of remote node results messages. If the debug setting is used when compiling, the program will also print to stdout. If the network is operating correctly messages should be seen from the remote nodes.

Command line options for xbee-acqcontrol are

-d directory to store results file

-P port (default is /dev/ttyUSB0)

-b baudrate (default 38400 baud)

## XBee-GUI

The GUI program is developed in C++ using the QT4 graphical libraries.

### Linux Installation

For Linux use, the following QT4 development libraries should be installed: qt4-designer, qt4-dev-tools, qt4-doc, qt4-qmake.

The program otherwise only uses the standard POSIX libraries.

Build the program with

- qmake
- make clean
- make

### Windows Installation

For development or compilation, download the QT opensource version 4.8.4 for Mingw 4.4 (http://qt-project.org/downloads). Install to its default folder .

Download the Mingw install GUI (http://www.mingw.org/wiki/Getting_Started). Also install to its default folder, as that will be used by default by QT. Copy the source files for XBee-GUI to a folder C:\XBee-GUI. From the start menu, open the QT 4.8.4 command prompt in the QT by Digia v4.8.4 entry. In the window, change directory to C:\XBee-GUI and issue the commands:

- qmake
- make clean
- make

The executable will appear in the “release” folder. To make it distributable, add copies of the following files found in the MinGW\bin and QT\4.8.4\bin folders:

- libgcc_s_dw2-1.dll
- libstdc++-6.dll
- mingwm10.dll
- QtCore4.dll
- QtGui4.dll
- QtNetwork4.dll

The resulting set of files can then be bundled into a zip file for distribution and should run on any Windows 7 installation without additional actions needed.

## Remote Node Firmware Arduino Development

For development of code on the remote node microcontroller it may be sufficient to make use of the Arduino IDE without the upload feature. This needs to be modified to ensure that the Intel iHex formatted binary file appears in an accessible place and is not deleted. To the Arduino IDE preferences configuration file (this file can be found as described in http://arduino.cc/en/Hacking/Preferences) add the following lines:

export.delete_target_folder=false

build.path=build

The former prevents deletion of the generated build files, and the latter places all build files into a local directory called “build”.

Once the hex file is available it can be uploaded using the XBee-GUI program.

## Bootloader for ATMega88/ATMega168/ATMega328

The bootloader is useful for updating the firmware in FLASH memory over the radio link. It shall sit in the allocated bootloader area of memory. On reset the microcontroller will start in this region automatically. The bootloader shall test the XBee bootloader output. If active, it shall wait for commands on the data channel to clear the Flash memory program area and to program pages of instructions. Otherwise it shall jump to the start of application code.

The bootloader must perform necessary hardware initialisation. For AVR devices this means disabling the watchdog timer (which remains enabled after a hardware reset).

The firmware data format shall be Intel iHex, which is compatible with many linker outputs. Reception of an iHex line will result in a block of data being programmed to Flash. Since an iHex line starts with a colon, that character will be taken as a command to program the line. A small number of other commands may be used to allow some additional functionality if space permits. The maximum length of a line shall be 16 byte of data.

As mentioned earlier, the bootloader will test the chosen bootloader output pin of the XBee at intervals and will jump to the application area if it is active.

Once a command to load memory has been received, the relevant memory block will be erased. A lock variable shall be set to indicate that this has happened as it must not be done again for the same block.

Because of the limited memory in the bootloader region, code shall be optimised for size.

The serial interface with the XBee should support flow control to take advantage of buffering in the XBee itself. This allow the bootloader to perform the lengthy erase and write operations with reduced probability of loss of frames. The protocol used in the base program should repeat frames if a negative acknowledgement is received.

The Bootloader requires close to 2K of FLASH, so the selected microcontroller will need to support this.

## Bootloader for ATTiny and ATMega48

These AVRs do not have a separate bootloader region and therefore the process of programming the FLASH over the radio link becomes more complicated.

The XBee can produce a digital output that can be used to reset the AVR and also specify that a bootloader block be entered. At the start of the program, test for the bootloader demand signal and jump to the bootloader if it is set.

## Remote Node Firmware

The microcontroller application shall make use of a data communication channel to transmit acquired data to the base station. The software must perform the following functions:

1. The microcontroller application shall implement regular timed sleeps, to be woken either by an external event or after a given time. When it wakes it may wake the XBee also, and transmit a status message to the base station as part of the data connection. The XBee need not be woken if only count events are occurring.
2. The microcontroller application shall implement a command interface to allow the base station to make configuration changes.
3. For timed A/D measurements, use a timer to wake the AVR and perform A/D conversions and other polled input measurements. Configuration settings will be used to select which of these is activated, if any. It may be preferable to use the XBee to perform the analogue conversions as it has its own internal reference voltage. If no ports are identified to provide measurements, the interrupt is disabled.
4. The AVR is set to wake the XBee regularly, as required to ensure continuity of connection to network XBee routers. It will then transmit any measurements made in the interim, if any.
5. Set the watchdog timer to a given (configurable) value. When it fires, check the XBee and wake it up. Check the communication with the base station. If failures occur, reset the XBee. This may result in a NI (node identify) message being sent by the latter.
6. Bootloader for firmware upgrades to be sent over the air. The XBee shall provide two outputs, one to reset the microcontroller and the other to indicate to the bootloader to wait for programming instructions (rather than jump directly to the application). The bootloader shall regularly test the XBee bootloader output and effect a jump to the application when it is deactivated.

Configuration settings:

- Configure ports to convert analogue signals.
- Configure ports to read digital signals.
- Configure frequency of polled measurements.
- Enable the counter measurements by pin change interrupt.

### Definitions

- txStatusReceived: boolean indicating that a status frame with delivery status information has been received from the base station.
- txDelivered: boolean indicating that the base station acknowledged successful receipt of a transmission (in terms of frame integrity and checksum).
- cycleComplete: boolean indicating that the protocol cycle has ended successfully or has been abandoned.
- transmit: boolean permitting a data transmission to be made to the base station.
- retry: Number of retries already made to try to get a successful base station response A maximum of three tries is preset into the firmware.
- messageState: the current state of reception of a frame. This increments as each stage of the message is parsed:
  - 0: no meaningful reception has occurred.
  - 1: a 7E frame sync character received
  - 2,3: message length high and low bytes
  - 4: frame type: 0x90 data frame or 0x8B status frame.
  - >4: remainder of message; length less 3 bytes.
- messageStatus: a byte representing the status of the message
  - NO_DATA: nothing received,
  - CHECKSUM: error detected,
  - COMPLETE: a message has been completely received and has the correct format.
- timeResponse: a timeout counter used to track non-reception of a base station response.
- packetError: boolean indicating that the packet received is errored or unexpected.
- packetReady: boolean indicating that the packet received is ready to be processed.

### Data Transmission Protocol Implementation

The data transmission protocol is designed to minimize the probability that any data will be lost. When the remote sends data it will clear the count once it has been convinced that the base station has received it correctly. The base station will store the count when it is certain that the remote knows it has been received.

In any part of this protocol the base station will reject the communication if it has not successfully completed.

In the event of messages not being received by the base station, a timeout will be implemented to prepare the base station for the next transmission from the remote. This timeout period must be longer than the longest time that the remote needs to complete the protocol, even in the presence of errors or missing messages. This is essential as the next transmission session can be confused with the current session in certain instances.

Initial remote data transmission

The network protocol starts with transmission of a data packet from the remote with command C plus counts from the watermeter sensor. There are three outcomes:

1. If after three attempts the message is not delivered (as given by delivery failure status messages via the coordinator XBee) then the session is abandoned. The counts are retained and accumulated over the following period.
2. A timeout while waiting for a response from the base station. The message is repeated up to three times by the remote using a T command. If no response is received then an X status command is returned indicating that the attempt is being abandoned. If the base station is not receiving messages from the remote it will abandon the session anyway and not record any data. If it is receiving messages but the remote is not receiving its responses then the X status command will definitely terminate the session. If the base station doesn't receive the X status command then it will abandon the session and not record the result .
3. The message is delivered. The base station is expected to reply with a data message containing N (NAK) calling for a repeat, or A (ACK) indicating success.

Base station response to faulty received data command

The base station sends an N (NAK) command if it detects a data message with a checksum or message length error. The remote then repeats the original message but using an N command to indicate to the base station that is has been repeated as requested.

1. If the N command is not correctly received by the remote it will ignore it. The timeout procedure will then take effect.
2. After three failed requests for repetition, the remote will abandon the session and send an X status command.
3. The base expects either a repeated message or an X status command. If neither arrive the base must abandon session and not record the result.

Base station response to unknown message

If the base station receives a message from the remote that it doesn't recognise, it simply ignores it. This should then trigger a timeout and retransmission in the remote.

Base station response to successfully received data command

In this case the base station sends an ACK command.

1. The remote is expected to respond with an A command indicating agreement has been reached between both sides. As this is the only response expected at this stage, the base will accept any corrupted data message as an A command.
2. If the A command isn't received then the timeout process will be invoked.
3. The protocol will fail if the final A command sent by the remote reaches the base station but is misinterpreted as not being a data command. In that case the remote will delete the collected counts but the base station will not record them.

To reduce the probability of failure the A command from the remote can be transmitted a number of times. There will be no feedback from the base station.

Remote response to faulty received status command

If the status command from the base is faulty, the remote repeats the original data message as an E command to indicate that it didn't understand the base station's response as either an A or N command. The base station will then repeat the previous status command or, if the newly received message is received correctly, an A command. If this fails after three attempts, an X command is sent to abandon the session.

The base station is not required in this design to perform any form of error recovery by retransmission. This would complicate the protocol without adding much value. It is important to note that the decision at the final acknowledgement stage to accept any data response from the remote as a valid acknowledgement, will be the key to reducing the probability of failure. Otherwise if only an A command is acceptable, then the probability of failure will be no different to a simple transmission of the data count. This requires the base station to be aware of the protocol state.

In extreme error situations it is possible for the protocol to not complete a cycle. The protocol state is automatically reset when a data command of any type is received to avoid confusion. The previous cycle is then aborted by the base station.

In addition to the protocol process there is a need to send commands to the remote from an application layer. These must be sent only when the data transmission protocol has completed its cycle, otherwise the command and responses may interfere. The remote firmware will nevertheless attempt to recognise such commands if they occur.

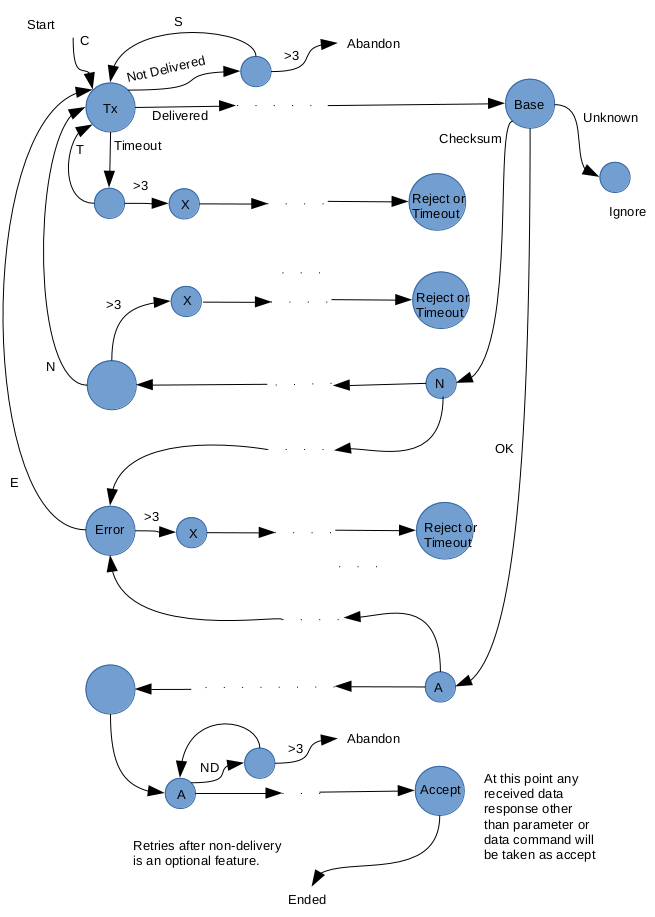
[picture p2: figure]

Illustration 1: Network flow diagram for data transmission protocol.

### Pseudocode

Pseudocode for the firmware :

1. Loop 1. Outer.
  - sleep until interrupt. Wake on count or WDT interrupt.
2. Loop 2.
  - set lastCounter = counter and wait 1ms. If count hasn't changed, drop out.
  - if WDT counter has reached the preset time, initiate transmission sequence.
3. Loop 3.
  - send C transmission of data (counts).
  - continue looping while waiting for the cycle of communication to complete.
4. Loop 4
  - Wait for a message to be received.
  - Count up timeResponse if nothing comes.
  - messageStatus indicates where we are in reception and if errors occurred.

Once this set of code has completed, the processing phase will begin using the booleans txStatusReceived, txDelivered, cycleComplete, packetError, packetReady to determine actions to be taken.

messageStatus

COMPLETE

- XBee receive frame has data. Copy and set packetReady = true.
- XBee status frame. This will indicate if the transmitted frame was received.

NONZERO (error)

- XBee receive frame has data. Discard.
- XBee status frame. Assume delivery occurred.

TIMEOUT awaiting status.

- Assume received but not delivered correctly.

TIMEOUT awaiting base station response.

- Signal a timeout has occurred.

Transmission delivered

- response received from base station. Look into contents of response.
  - NAK. Continue up to three times, then return an N message.
  - ACK. Adjust counter by subtracting the number already sent, and finish.
- response errored. Continue up to three times, then return an E message.

Status indicates not delivered

- Continue up to three times, then abandon whole process.

Status indicates timeout occurred

- Continue up to three times, then return a T message.

A message arrives outside the transmission protocol, that is, independently of the txStatusReceived and txDelivered messages that refer to a previous transmission. Interpret as a higher level application message.

Finally if the retry limit has been exceeded, return an X command indicating abortion of the transmission attempt. A new transmission will be attempted next period with previous period counts included.

Otherwise send acceptance.

### Flowcharts for remote protocol process

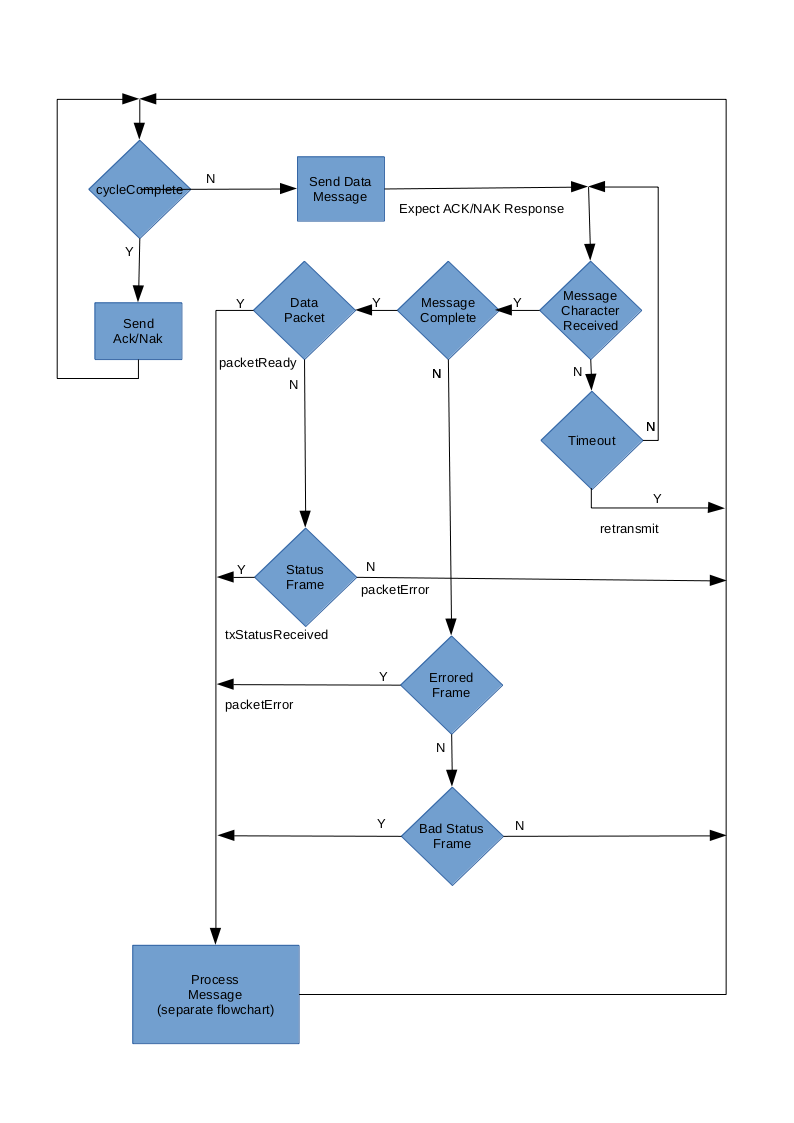
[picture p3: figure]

Illustration 2: Flowchart for detection of messages.

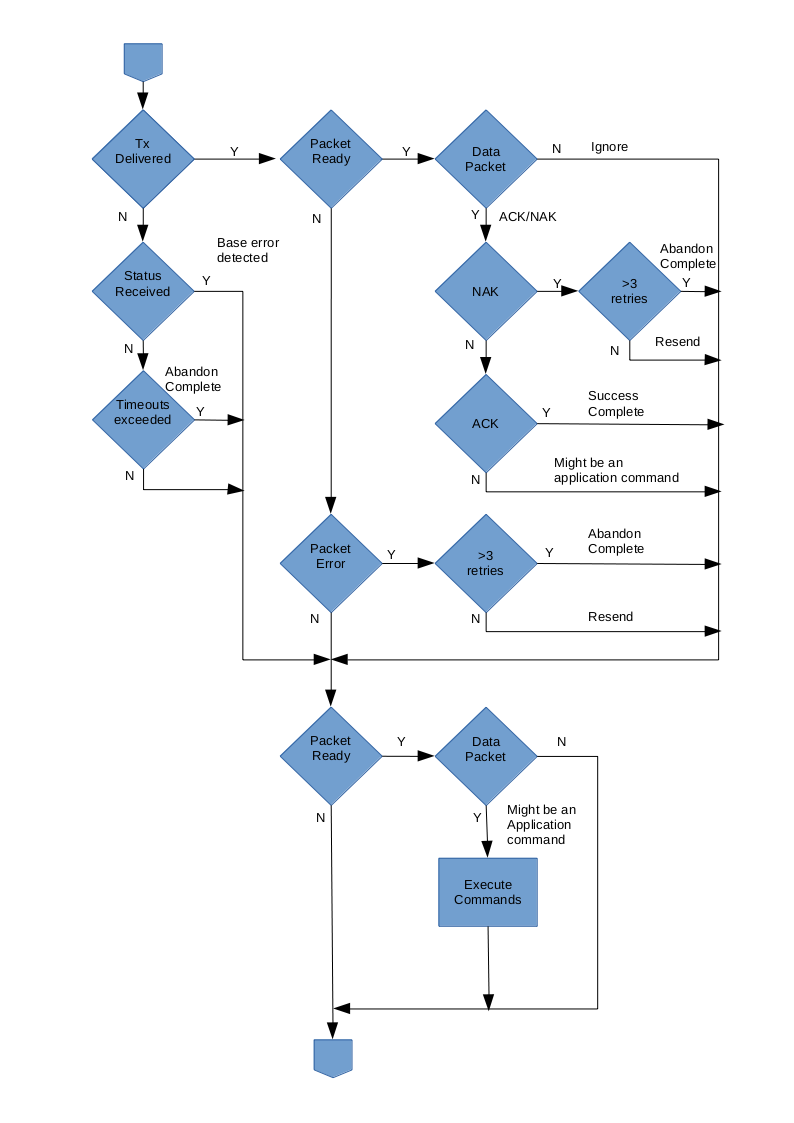
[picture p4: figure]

Illustration 3: Flowchart for processing of messages.

### Firmware for Watermeter

This has a very low power requirement. Since the only measurements are counts, the firmware uses a slightly different approach for managing sleep and interrupts. See the watermeter document.

## Testing of Firmware

The tests must verify that the protocol is able to handle all error conditions and ensure delivery of the counts accurately. Any network error conditions may result in the remote node and the base station having different ideas about what data was communicated.

There is only a limited debugging capability in the AVR microcontrollers so code may be verified by running it on a Linux machine and setting the AVR specific instructions to stubs. This then communicates with an XBee mounted on a board with a serial interface. The code being run may provide extensive debug printout. The procedures for doing this are described in the next chapter.

Testing on the AVR itself is somewhat more challenging. All behaviour must be determined from the messages received by the base station.

### Error free test

Set debug printout in the base station software and the PC simulator software if used.

- Remote node wakes and sends a count data message.
- Receives an XBee status frame with successful delivery.
- Receives a data message with 'A' acknowledge.
- Returns an 'A' message to complete transfer.
- XBee status frames after that are ignored.

### Message received in error by base station

This can be simulated in the base station by changing the 'A' message sent back to 'N', or by signalling a checksum error.

- Remote node wakes and sends a count data message.
- Receives an XBee status frame with successful delivery.
- Receives a data message with 'N' acknowledge.
- Resends the original transmission.
- Repeats three times.
- Returns an 'X' message to complete transfer and signal abandonment.
- XBee status frames after that are ignored.

### Base station acknowledge lost

This can be simulated by changing the firmware code to ignore the acknowledge. It can happen in the watermeter due to delay in reading the XBee serial port when an interrupt occurs.

- Remote node wakes and sends a count data message.
- Receives an XBee status frame with successful delivery.
- Timeout waiting for the acknowledge.
- Resends the original transmission.
- Repeats three times.
- Returns an 'X' message to complete transfer and signal abandonment.

XBee status frames after that are ignored.

### Base station acknowledge excessively delayed

This can be simulated in the base station by adding a 200ms or 500ms sleep before sending the acknowledge. If the remote is able to receive the 'A' message after any status frame from repeated transmissions, and before the third timeout retry, then the original transmission will be accepted by the base station. In the test performed, the 200ms sleep resulted in the 'A' message arriving at the remote before the status frame and the following sequence occurred.

- Remote node wakes and sends a count data message.
- Receives an XBee status frame with successful delivery.
- Timeout waiting for the acknowledge.
- Resends the original transmission.
- Acknowledge arrives before the transmission status frame. This is treated as an out-of-protocol application message.
- Repeats three times.
- Returns an 'X' message to complete transfer and signal abandonment.
- XBee status frames after that are ignored.

### Extreme range tests

At extreme range the XBee communications will typically drop out over a short distance and all communication will be suspended. The protocol response to this and to errors that occur just on the limit of range must verify that data is not lost. Note that the base station may have a much higher transmission power than the nodes, and therefore the nodes may receive clear responses from the base station, while the base station may receive errored or missing remote messages.

# Module Testing

A number of test hardware and software modules are provided.

## Remote Node with ATMega48

The board is a standalone board comprising:

- an ATMega48 microcontroller,
- an XBee,
- Red LED for power,
- Yellow LED for XBee associate signal,
- Green LED for microcontroller test signal,
- screw connector for digital counter signal input,
- screw connector and trimpot for analogue signal input.

It accepts 5V power and drops this to 3.3V for the XBee.

The board schematic is given in Development/gEDA-Xbee-Test as xbee-node-atmega48.sch.

The following connections are made:

- XBee CTS pin 12 connected to ATMega48 pin 4 PD2,
- XBee RTS pin 16 connected to ATMega48 pin 5 PD3,
- XBee Reset pin 5 connected to ATMega48 pin 19,
- XBee Sleep_RQ pin 9 connected to ATMega48 pin 17 PB3,
- XBee On/Sleep pin 13 connected to ATMega48 pin 18 PB4,
- XBee Microcontroller reset pin 4 DIO12,
- XBee Bootloader D11 pin 7 connected to ATMega48 pin 16 PB2,
- XBee AD1 pin 19 connected to ATMega48 pin 24 ADC1 and Battery Monitor signal,
- XBee AD2 pin 18 connected to ATMega48 pin 23 ADC0 and Analogue in,
- Counter input connected to ATMega48 pin 11 PD5.

## Remote Node with ATTiny4313

This has only been built on a prototyping layout and has not been used to any extent. Other than the processor change and the lack of an A/D port (since the ATTiny4313 doesn't have an A/D converter), it is the same as the ATMega48 board.

The board schematic is given in Development/gEDA-Xbee-Test as xbee-node-attiny4313.sch.

## Remote PC Attached Node

This is a board designed to use a serial RS232 connection directly to the XBee so that a PC can be used to emulate the microcontroller in a node. The board comprises:

- an XBee,
- Red LED for power,
- Yellow LED for XBee associate signal,
- Green LED for on/sleep signal,
- Orange LED for Sleep_RQ signal,
- RS232 converter,
- Reset momentary on button,
- Force sleep_RQ toggle switch,
- Commissioning momentary on button.

It accepts 12V power and drops this to 5V for the RS232 converter and 3.3V for the XBee.

The board schematic is given in Development/gEDA-Xbee-Test as xbee-node-serial.sch.

## Watermeter Board

This is the production module. The following connections are made:

- XBee_reset pin 5 connected to ATTiny841 pin 5 PB2,
- XBee Sleep_RQ pin 9 connected to ATTiny841 pin 10 PA3,
- XBee On/Sleep pin 13 connected to ATTiny841 pin 13 PA0,
- XBee Microcontroller reset DIO12 pin 4,
- XBee Bootloader DIO11 pin 7 connected to ATTiny841 pin 2 PB0,
- XBee AD1 pin 19 connected to Battery Monitor signal,
- Control pin for enabling Battery Monitor ATTiny841 pin 6 PA7,
- Counter input connected to ATTiny841 pin 3 PB1,
- XBee associated and commissioning signals are not connected to the ATTiny841.

## Node Test Firmware

Firmware for testing a node can be found in Development/Xbee-node-test (xbee-node-test (https://github.com/ksarkies/XBee-Acquisition/tree/master/XBee-node-test)). This transmits a single message at regular intervals consisting of a D followed by an integer count value taken from the digital counter input on the board. If compiled for ATMega48 it will use a baud rate of 38400, while for the ATTiny841 on the watermeter board it will have a baud rate of 9600.

The libs directory contains board definitions which define the capabilities of each board and processor and the various pin allocations.

The serial port definitions in defines-M168.h, that are relevant to this ATMega48, require that CTS be enabled on the XBee for DIO7. This is to allow for the eventual development of a bootloader. The board rate is set at 38400.

The serial port definitions in defines-T841.h, that are relevant to the watermeter board, require that CTS be disabled on the XBee for DIO7. There are no hardware flow control signals passed back to the microcontroller from the XBee. Also the baud rate is set to 9600 to ensure accurate communication with the mirocontroller.

## PC Based Emulated Node Test Firmware

This is a POSIX system based test code for an XBee remote unit. Written in C but embedded in a QT/C++ wrapper which emulates the environment for the test code. It can be run with any adapter interface board that contains a USB-serial converter, or with a board having a serial interface plus an external USB-serial converter. The emulator is not an AVR emulator. Rather it provides a means to run the Xbee firmware core on a PC for debugging. It is not possible to drive or sense any of the hardware pins on the XBee, so sleep modes are not possible.

The code can be found in Development/Xbee-node-test-pc (xbee-node-test-pc (https://github.com/ksarkies/XBee-Acquisition/tree/master/XBee-node-test-pc)).

There is also a non-GUI C version of the emulator that will run on micro computer boards such as the Raspberry-Pi and the BeagleBoards where QT is not simple to install.

The purpose is to provide a PC Linux based testbed for emulating remote system firmware that is capable of communicating directly with an XBee over a serial port, and working as a remote unit.

NOTE: gcc is required to allow function override for timerISR.

The program can be run without a GUI from the command line with the -n option. A debug mode is available for extended printout.

$ xbee-node-test -d -P /dev/ttyUSB0 -b 38400 -n

In command line mode, the program can only be stopped by ctl-C or process kill.

The following main program modules allow different tests to be run. Change the XBee-node-test.pro file to compile the different tests.

### mainprog-test.cpp

This is adapted from the xbee-node-test (https://github.com/ksarkies/XBee-Acquisition/tree/master/XBee-node-test) code and performs the same functions as the node test firmware.

### mainprog-firmware.cpp

This is adapted from the xbee-firmware (https://github.com/ksarkies/XBee-Acquisition/tree/master/XBee-firmware) code and emulates the full production firmware. This must be modified to reflect changes in that firmware.

### Adaptation to Other Test Code

The following files may be used as the environment emulator for other code tests with appropriate adaption of the .pro and mainprog.cpp files:

- xbee-node-test-main.cpp
- xbee-node-test.cpp
- xbee-node-test.h
- xbee-node-test.pro
- xbee-node-test.ui
- serial.cpp

serial.cpp is a substitute set of communication functions calling on POSIX/QT serial I/O. This should contain functions that match the calls in the test code.

mainprog.cpp must be provided with the code to be tested in the following way:

Split the code to be tested into an initialization part and an operational part that normally falls within an infinite loop. Place the initialization part into the function called mainprogInit(), and the operational part into mainprog(). Both these are called from the xbee-node-test.cpp wrapper, with the operational part having its loop emulated in the wrapper code.

There should be no compilable processor specific statements. These can be replaced by a call to a local function that should contain code to emulate the statement. If this is not possible then the code is not suitable for testing in this way.

Add all global variables as static. Add also any include files needed. These should not contain references to any processor specific libraries or functions.

ISRs need to be changed to a function call and means to activate them devised. A timer is emulated in the emulator code. Timer initialization is done by calling an initialization function in the emulator code. This function sets the number of one millisecond tick counts at which the timer fires and calls the ISR. If a timer ISR is not defined, a null ISR is substituted. The timer ISR can be defined in the test code by replacing the actual ISR call with the function: timerISR().

xbee.cpp is a file associated with the code under test, which has been copied from the library directory with its extension changed from c to cpp to satisfy the g++ compiler (otherwise it is not correctly linked).

### Watermeter Count Test

This is a test firmware for the AVR in the watermeter. Written in C under avr-gcc.

The code can be found in Development/watermeter-count-test (watermeter-count-test (https://github.com/ksarkies/XBee-Acquisition/tree/master/watermeter-count-test)).

This test transmits the count of the photointerrupter at regular intervals (1 sec) via the serial port at 9600 baud in csv format for capture and analysis off-line. This link is normally connected to an XBee in the watermeter assembly. The test can only be used where the XBee is not present and the serial link is brought out to a PC serial port.

### Watermeter Echo Test

This is a simple test firmware for the AVR in the watermeter. Written in C under avr-gcc.

The code can be found in Development/watermeter-echo-test (watermeter-echo-test (https://github.com/ksarkies/XBee-Acquisition/tree/master/watermeter-echo-test)).

This test simply echoes characters back on the serial port at 9600 baud. Use to verify that the serial link to the AVR is working. This link is normally connected to an XBee in the watermeter assembly. The test can only be used where the XBee is not present and the serial link is brought out to a PC serial port.

# Testing

## Firmware Debug Tests

The protocol requires extensive testing to ensure that the system recovers correctly from errors. Make use of the Development/Xbee-node-test-pc/emulator-* emulators. The following shows the emulator output from:

$ xbee-node-test -d

END device present. Normally there should be an 8B (Tx status frame) and 90 (data frame containing the ACK). Often there is an 88 frame apparently left over from a previous association query but this is rightly ignored.

New Cycle

Transmit Command C , Last Count 0

Message Type 88, Length 15

Packet error detected: Type 88, Length 15

Unknown Frame: data contents 3 49 53 0 1 18 0 3 10 0 2 14 2 12

New Cycle

Message Type 8b, Length 7

Zigbee Transmit Status Frame: data contents 2 0 0 0 0 0

Delivery Status? 0 delivered

Delivered, start processing

Normal Zigbee Transmit Status Frame from local XBee

New Cycle

Message Type 90, Length 13

Got a data frame: reply A, data contents 0 b0 30 a5 8c fc 7f 0 0 b3 57 cc

Delivered, start processing

Process Packet ready to check for ACK/NAK

ACK

Finished Cycle

Accepted

From the Coordinator output:

$ xbee-acqcontrol -d

Node END-13 Data Packet: Time 2017-02-07T10:20:39 length 11, data CFE03FF0000

Command Received C Count 0 Voltage 4.909802 V

Sent ACK

## Operational Tests

The coordinator software may be run in debug mode using the -d or -e x options, where x is a debug level 0-2. This will provide verbacious teminal output concerning the received and transmitted signals. For example:

Node END-14 Data Packet: 2017-03-14T00:43:00 A16: C7AE A64: 0013A2004089DEBC length 11, data CFC03FF0002

Command Received C Count 2 Voltage 4.909802 V Retry 0

Sent ACK

Transmit Status: 2017-03-14T00:43:00 Length: 6 FrameID 20, 16 Bit Address C7AE, END-14 Retry count 0, Delivery status 0, Discovery status 40

Node END-14 Data Packet: 2017-03-14T00:43:00 A16: C7AE A64: 0013A2004089DEBC length 11, data TBC43FF0002

Command Received T Count 2 Voltage 4.909802 V Retry 1

Sent ACK

Transmit Status: 2017-03-14T00:43:01 Length: 6 FrameID 21, 16 Bit Address C7AE, END-14 Retry count 0, Delivery status 0, Discovery status 40

Node END-14 Data Packet: 2017-03-14T00:43:01 A16: C7AE A64: 0013A2004089DEBC length 1, data A

This shows a reception of a data packet from END-14, that is interpreted as a normal C command carrying battery voltage and meter count. An ACK signal is sent back. The Transmit Status message indicates a delivery status of 0, which represents success. However the remote has not apparently received the message and returns a second data packet with a T command indicating that a timeout occurred waiting for the ACK. The data content is identical to the earlier message. Another ACK is sent and this time there is no further response from the remote. At this point the protocol assumes that the transmission is successful otherwise it would have received a second timeout message.

The timeouts should not normally occur. At this time, the cause of this behaviour is unknown.

The coordinator should be able to handle as many as 25 remotes with a 125 second interval between transmissions. The transmissions should be handled correctly even if they arrive simultaneously.

XBee-Network-design-notes.odt 02/12/17

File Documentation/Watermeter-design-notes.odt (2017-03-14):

# Introduction

These are notes on the design of a watermeter data acquisition board using an AVR microcontroller and XBee communications for the Xerofill project.

The choice of this configuration was made to allow wide flexibility of data collection, management and communication. The choice of AVR was based on familiarity with the architecture, ready availability of software support tools and small device size.

The primary consideration of the project is low power consumption to maximize battery life. Extensive use of sleep modes in the microcontroller and the XBee, and careful use of power during wake periods can help to achieve this goal.

# Requirements

The process to be monitored is a pulsed signal whose characteristics determine rate of flow and quantity of water passing through the meter. The primary measure is the number of pulses counted in a given time period. The expected pattern of signal arrival is in bursts of variable length. Signal pulse rate is 400Hz maximum (2.5ms minimum pulse period).

- The AVR shall count the pulses and transmit the total to the base station.
- Signal pulses shall interrupt the microcontroller, or wake it from sleep. The wake process must be completed within 1ms.
- The microcontroller shall instruct the XBee to transmit a measure of battery voltage following the pulse count transmission.
- The XBee shall remain awake until reception of a response from the base station containing any queued messages. It shall return to sleep mode after the last of these messages have been received and answered, and no further transmission is needed.
- The microcontroller shall remain awake for 20 seconds following the last pulse. It may then sleep.

# Design Choices: Power Supply

The power source will influence the electronic circuit and PCB layout to a large extent.

The circuit requires a nominal operating voltage of 3.3V

- Xbee S2 ZB 2.1V to 3.6V
- AVR speed grade 4MHz 1.8V to 5.5V
- MAX953ESA operational amplifier/comparator 2.4V to 7V

Thus the acceptable operating range is 2.4V to 3.6V.

## AA Battery Pack 4 x 1.5V

- This will require a regulator to 3.3v.
- Supply voltage will be steady.
- Measurement of battery state will require extra components.
- Ready interchangeability of batteries among different chemistries.

AA size Alkaline batteries can provide 2800mAH, AAA size Alkaline batteries can provide 1200mAH at low current drain.

## Li Battery 3.6V

These are Lithium Thionyl Chloride.

- Supply voltage will be steady until the very end, requiring precise monitoring.
- Xbee can monitor voltage internally.
- Hazardous and may require trained person to change.
- Half AA small in size allowing simplicity of placement of components on PCB.

The possible sizes are half AA (1200mAH), full AA (2400mAH). Two AA cells can be joined via Schottky diodes. A low droput regulator may be used. The TPS77033 is specified to drop 35mV at 50mA. This will allow the battery to droop to almost 3.3V before regulation ceases.

ER14250 datasheet shows internal resistance of 50Ω at 25C and 1mA drain. Lifetime is 1000 hours at 1mA.

# Design Choices: Electronics

With the aim of minimising battery power drain, the following outlines possible choices for the mode of operation of the microcontroller. The microcontroller and XBee will be placed in sleep mode during periods when no signals are arriving, to be woken up at the start of a signal burst sequence.

A major consideration is how the signal pulses may be counted (by hardware or software) and what type of sleep modes are appropriate for these devices.

A second consideration is to minimise the number of components and to ensure that they are of minimal size due to the space constraints on the PCB.

## Microcontroller

The microcontroller shall be either the ATTiny2313A or the ATTiny441 series. These are selected for their low power, small device size and availability of UART peripherals. Other ATTiny devices have a generalized form of serial communications (USI) that require additional software support to use as a USART. The ATTiny2313A lacks an A/D converter and is slightly larger in its DIL package form. For sleep modes these devices offer only idle, standby and power down, the last of which is the lowest power mode. Power down mode turns of most clocks and so allows only a limited number of external events to wake the microcontroller. The AVRs can power down unused peripherals in active mode.

## Counting Pulses

### Interrupt on Count

Interrupting the microcontroller and waking from a sleep state appears to be the best solution in terms of PCB space and power consumption. Only the microcontroller, XBee and signal conditioning electronics are needed. The microcontroller will be woken from power down mode by an arriving signal pulse. It will then count pulses by means of an interrupt service routine (ISR) and at an appropriate time it will wake the XBee and transmit the result along with a battery voltage measure. The watchdog timer may be used to perform the periodic awakening. This requires the watchdog timer clock to remain active, but this is very low frequency and hence low power drain.

### Hardware Counter

This is an alternative to the above solution. A single external counter chip with serial output would provide a lowest power solution, leaving the microcontroller and XBee to remain asleep until a burst of counts has been completed. Only one counter device has been found that has the desired features, but it has been discontinued. A major operational difficulty with this solution is how to wake the microcontroller at the optimal time.

### Timer/Counter

This is another alternative to the above solution. One of the microcontroller timer/counters may be used to count pulses directly. This requires one of the timers to remain powered on and the microcontroller to be placed in standby mode (this is the same as power down but with system clock enabled).

Standby mode consumes over 100 μA in the ATTiny441 compared to less than 1μA in power down mode. The microcontroller could be placed in standby mode after wakeup from power down. Wakeup can only occur with an external interrupt. As such the signal pulses must be applied to an interrupt pin as well as the counter input pin.

Standby mode requires a crystal clock source (not the internal RC oscillator), which means additional components on the PC board.

The datasheets do not indicate if the counters will be operational in standby mode.

It appears that using a counter is an unnecessary complication which will only result in increased power consumption during sleep phase.

## Other Considerations

### Clock Timing

Clock frequency affects power drain in active mode. The internal clock options are:

- ATTiny2313A has an internal calibrated clock with a preset divide by 8 option allowing 1MHz or 8MHz. There also appears to be a 4MHz option but this is not explained in the datasheet and it is uncertain if the clock divider applies. It also has a 128kHz low power oscillator. An additional clock prescaler is available providing division ratios up to 256 on any clock source.
- ATTiny441 has an internal calibrated clock with a divide by 8 option allowing 1MHz or 8MHz. It also has a low power oscillator with a number of frequency ranges between 32kHz and 512kHz. An additional clock prescaler is available providing division ratios up to 256 on any clock source.

In both microcontrollers the clock startup time after wake from sleep for the internal clocks is 6 clock cycles.

### USART

The USART is used to communicate serially with the XBee. A baud rate of 38400 baud causes severe constraints on the AVR clock frequency. The normal asynchronous mode will require 16 samples and the double speed mode 8 samples. This will constrain the clock frequency to be well over 1MHz. If the baud rate is reduced to 9600 a clock frequency of 1MHz can be used for the double rate asynchronous mode, or 2MHz for the normal asynchronous mode. This will give an acceptable clock error of 0.15%.

### ISR Response Time

The specified response time for an asynchronous interrupt is:

- four clock cycles to clear the Global Interrupt flag (GIF), and push the program counter (PC) to the stack.
- Two (rjmp) or three (jmp) clock cycles are needed to execute a jump to the ISR.
- Another four clock cycles is needed to return from the ISR to pop the PC, increment the stack pointer (SP) and set the GIF.
- On wake from sleep mode an additional four clock cycles is needed in addition to the clock startup time. However this occurs only once in a burst of signal pulses and may be neglected for the moment.

### ISR Code

The remaining ISR time is taken up with user code. An event counter needs to be incremented and a decision made regarding transmission of results. The actual code for initiating transmission will be external to the ISR.

All operations use 8 bit register or memory locations.

The ISR must save and restore any used registers and the status register. If one register is used this needs 6 clock cycles.

The processing instructions needed are a load from memory followed by increment and store back to memory.

ldd Rx,count_low

inc Rx

sdd count_low,Rx

This requires five clock cycles.

In addition to this a program branch instruction must be made on counter overflow. This would need to test for zero following the increment instruction.

cpi Rx,0

breq k

ldd Ry,count_high

inc Ry

sdd count_high,Ry

where k is the number of instructions to skip. This requires two clock cycles if a branch occurred, and six if the code were executed.

The average execution time for this code is therefore interrupt latency (10), sleep startup if in sleep mode (10, neglected), register save and restore (6), core code execution (7), branch execution every 256 ISR calls (6-2):

23+(6-2)/256 clock cycles

The additional execution time following a counter overflow may be extended if the counter is made longer. An absolute minimum clock frequency will be 18/2.5ms = 9.6 kHz. It can be concluded that the ISR time is negligible. This indicates that additional latency due to overflow for any one interrupt, plus the additional overhead in the C language compilation, should not result in any loss of data.

## Timing the Transmission of Results

A choice must be made when to transmit results to the base station. If the extreme choice is made that the transmission is made only when the count reaches a certain level, then the lowest power consumption will be achieved. However as the XBee is unreachable while asleep, this may cause results to be unavailable for extended periods.

If the XBee is to be woken up at regular intervals to transmit results, then either the XBee must be placed in cyclic sleep mode and wake the microcontroller, or the microcontroller must run a clock timer while asleep and wake the XBee at regular intervals. The watchdog timer can be used during power-down mode.

### XBee Sleep

The XBee specifications state a current drain of less than 1 μA in sleep mode, however it is not clear if this is modified by the activity of the timer. Some forum posts have indicated a problem with the drain being as much as 100 μA. There is a hint on the Digi Wiki that using cyclic sleep will increase power drain during sleep mode, which is expected as clocks and a timer must be active. Others hint of a mystery specification of 50 μA in cyclic sleep mode.

A note on one of the forums indicated that the sleep_rq pin be held low for “deep” sleep (deep sleep is not mentioned in the documentation to hand for the Xbee type being used). This seems counter intuitive since doing this will wake the XBee, unless the pin sleep mode is disabled.

Note: the coordinator must set the “Child Poll Timeout” to a longer time than the end devices' maximum sleep time to ensure that the latter are not removed from association while asleep.

The end device XBee has only pin wake (mode 1), cyclic sleep (mode 4) and cyclic sleep/pin wake (mode 5). In cyclic sleep modes the XBee wakes regularly. This must be set quite low (default is 200ms) in order for the configuration utility to be able to reconfigure the device.

A pin wake mode is needed for the AVR to be able to communicate its results. When the last transmission has been sent, the XBee must be allowed to remain awake for at least 100ms to allow the transmission to complete.

### AVR Wakeup

If the AVR is used to wakeup at regular intervals, the watchdog timer must be used. This increases the power down current consumption to 4 μA typical from the 0.17 μA without the timer enabled. It can be configured to interrupt rather than reset in order to wake up the AVR without loss of data.

The “Child Poll Timeout” mentioned above also applies in this case, so there is a limit on the amount of time the XBee can sleep.

Given the uncertainty about power draw by the XBee in cyclic sleep mode, it would be sensible to use pin sleep only and accept the higher drain on the AVR.

To conserve power in active mode the following unused peripherals must be turned off. For the ATTiny441 (the ATTiny2313A is similar but has fewer peripherals):

- A/D converter (not ATTiny2313A).
- Analogue comparator.
- Brown out detector (either fuse bits or by BOD-sleep).
- Internal voltage reference (automatically disabled when the above are disabled).
- Timer/counters.
- SPI.
- TWI.
- USART1 (not ATTiny2313A).
- All digital input buffers for unused I/O ports.

The USART0 will remain powered on, as well as the input buffers for INT0 and the XBee on/sleep signal.

According to the ATTiny441 and ATTiny2313A specifications the AVR will consume 400 μA for a 1MHz clock and 3.3V Vcc. The USART0 will consume 22 μA at 3.3V Vcc.

The wake time will depend on the nature of the process being measured. The AVR will remain awake as long as signals are being generated.

## XBee Wake Time

When the XBee is woken, the microcontroller will need to announce itself to the base application. This will allow the application to pass on any specific instructions to the node. The XBee network does support the buffering of application messages but only for a maximum of 28 seconds.

The microcontroller will send a packet of data for transmission to the application and wait for an acknowledgement to be received. Once the transaction is complete the XBee will be placed back in power-down mode. In most cases this simple transaction will be the only action that occurs.

There will be times where more interaction occurs if the base station requests additional status information from the node or transmits a large amount of information, such as a firmware upgrade. These can be ignored for the point of view of power drain as they will be uncommon.

As an example a data message of 10 bytes that includes four bytes of data plus six bytes of protocol framing will take about 8 ms to transmit serially to the XBee at 9600 bps. The XBee takes about 10 ms to send this and receive a response from the network. The time of response to the application message however will depend on the application and the supporting hardware, software and protocols, and will need to be measured.

In the meantime the XBee must be in a position to receive that response. In reality the response will have been buffered and it is only necessary to re-enable the receiver at some near future time. Thus the XBee will only need to be active when it is sending and receiving, and not while the application is processing the message. The Xbee could be put back to sleep and woken again after a second or so to receive any waiting messages.

Assume that a typical communication will require the XBee to be awake for only 36 ms total (as a first estimate). Current drain in active mode is 40mA for the basic XBee ZB (S2) in both transmit and receive, and 15mA while idle. If the XBee is woken once per hour for a simple transaction then the average current drain will be

40 mA * 36 ms/1 hr = 0.4 μA.

This result suggests that the assumed operational parameters above might be relaxed, for example with the Xbee being woken up every 10 minutes for an average current drain of 2.4 μA.

A stress test run will wake the XBee every 16 seconds for an average drain of 0.18 mA.

## Total Power Demand

The total power demand may now be estimated from the above design choices.

- AVR in power down mode watchdog timer enabled, continuous 4 μA.
- AVR in active mode with 1MHz clock, 400 μA for the CPU and USART0 22 μA for an unspecified duty cycle.
- XBee in pin sleep mode, continuous 1 μA.
- XBee in active mode, average 2.4 μA.
- IR LED 10 μA.
- Comparator 5 μA.
- Bias chain 20 μA.
- Pull down resistor 1M for Sleep_Rq, held high during XBee sleep, 3 μA.

The final current drain will depend on the amount of time the AVR is kept in active mode. If this is say 1% of the time (about 30 seconds every hour) then the total drain is 46 μA.

Measured current drain for whole circuit with AVR and XBee sleeping is 35uA.

A battery pack 2800 mAH will last for 62,000 hours (7 years).

## Effect of Current on Lithium Thionyl Chloride Battery Voltage

The datasheet for ER14250 shows an internal resistance of 50Ω at 25oC and 1mA drain. Lifetime is 1100 hours at 0.5mA. Battery holds its voltage to almost the end.

Thus at 40mA drain it will nominally drop 2V. Datasheet suggests 50mA over 0.1 seconds every 2 minutes will yield voltages above 3V, possibly held up as a result of dynamic effects in the battery.

The battery has a high specific energy and low weight, but has a high internal resistance, and therefore a low-rate-only discharge with limited short-circuit current.

## Hardware

The microcontroller is assumed to be any one of the Atmel AVR devices that has enough FLASH memory to hold a bootloader (which needs 2K memory). The following considers the ATMega48/88/168/328 series (excluding the ATMega48 due to its low FLASH size). These have 23 signal pins plus ground, Vcc and Aref. The following allocation of XBee and microcontroller ports should leave sufficient digital I/O and analogue Inputs for expected application needs. The AVR ports are shared with alternate functions. The ports freed for data acquisition have been selected to maximise the foreseeable needs. All these ports except for the Aref input can be used for digital I/O.

The below table shows the selected interconnections between the XBee and the AVR as well as various I/O ports available in the AVR for data acquisition.

When setting up the microcontroller, select the internal 8MHz clock; set the bootloader size to 1024 words; and set the watchdog timer to be always on. The latter will ensure that the watchdog timer is operational in a sleep state.

The selected AVR will need to use the Power Save sleep mode to ensure current drain is minimal (around 4 microamps with the WDT enabled). This means that the counters 0 and 1 will not be running. Therefore external counting will be done using interrupts that will wake the AVR and register on each count. Attempting to use a timer in this case is unreasonable.

In the circuit diagram below the 3.3V power is derived from a regulator with microamp quiescent current and a current boost transistor. Two inputs, an analogue and digital input are provided, the former could be read by the XBee directly or an A/D input in the microcontroller. The digital input is intended for counting events and is passed to a microcontroller general purpose digital port which can interrupt when the signal changes. A voltage divider for the battery monitor voltage is controlled by a MOSFET which turns off all current drain when the XBee is asleep. This can be passed either to the XBee or the microcontroller. A voltage reference for the microcontroller is derived from this, although this may be omitted if the microcontroller does not perform analogue measurements. Note that this diagram omits power supply filters needed for stability and A/D accuracy.

XBee Pin | XBee Port | Function | ATMega168 Pin
2 | DOUT | UART Data Out | 2 (Out PD0)
3 | DIN | UART Data In | 3 (In PD1)
9 | CTS | Clear to send (from XBee) | 4 (In PD2)
16 | RTS | Request to send (to XBee) | 5 (Out PD3)
9 | Sleep_RQ | Wake XBee | 19 (Out PB5)
13 | ON/Sleep | XBee Sleep Indication | 18 (In PB4)
5 | RESET | Reset XBee | 17 (Out PB3)
7 | DIO11 | MC Wake/Bootloader | 16 (In PB2)
4 | DIO12 | Reset MC | 1
6 | DIO10
15 | DIO5
11 | DIO4
20 | AD0
19 | AD1
18 | AD2
17 | AD3
| | PD4/Timer Count 0 | 6 (In T0)
| | PD5/Timer Count 1 | 11 (In T1/OC0B)
| | PD6/Analogue Comparator | 12 (In AIN0/OC0A)
| | PD7/Analogue Comparator | 13 (In AIN1)
| | PB0/Input Capture 1 | 14 (In ICP1)
| | PB6 | 9
| | PB7 | 10
| | PB1 | 15 (OC1A)
| | Analogue Reference | 21 (In ARef)
| | PC0/ADC0 Analogue In | 23
| | PC1/ADC1 Battery Monitor | 24
| | PC2/ADC2 | 25
| | PC3/ADC3 | 26
| | PC4/ADC4 | 27
| | Power Off Control | 28

## Firmware

### Wake from Sleep

With the AVR placed in power down sleep, the watchdog timer and counter interrupt are the only two events that can wake it. This gives rise to a number of difficulties.

Firstly, the counter interrupt INT0 triggers asynchronously only on low level mode when in power down mode. This raises a significant difficulty if the slotted wheel stops at a point that holds the count signal low.

The counter interrupt INT0 can be replaced by a pin change interrupt PCINT9 which is also asynchronous. This only requires then to determine the polarity of the counter signal.

The ISRs need to process an amount of information: the counter interrupt needs to determine when to increment the count, and the watchdog timer interrupt needs to initiate a transmission.

At the time the watchdog timer interrupts and wakes the AVR, a period of time is needed for the AVR to remain awake to receive incoming transmissions from the base station and take action on them.
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

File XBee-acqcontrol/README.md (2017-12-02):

XBee Data Acquisition Control
-----------------------------

A background control process written in C. Its purpose is to manage the XBee
acquisition network and interface to an externally or locally running user
interface. This allows a small low-power on-site Linux machine to monitor the
system and communicate over LAN or WAN to a GUI running on a separate PC.

[Download libxbee](https://github.com/attie/libxbee3) from GitHub. This can be done with 'git clone' or downloading
the provided zip file.

The latest stable version at this time is 3.0.11. Compile libxbee according to
the included instructions and install. Then compile xbee-acqcontrol.
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

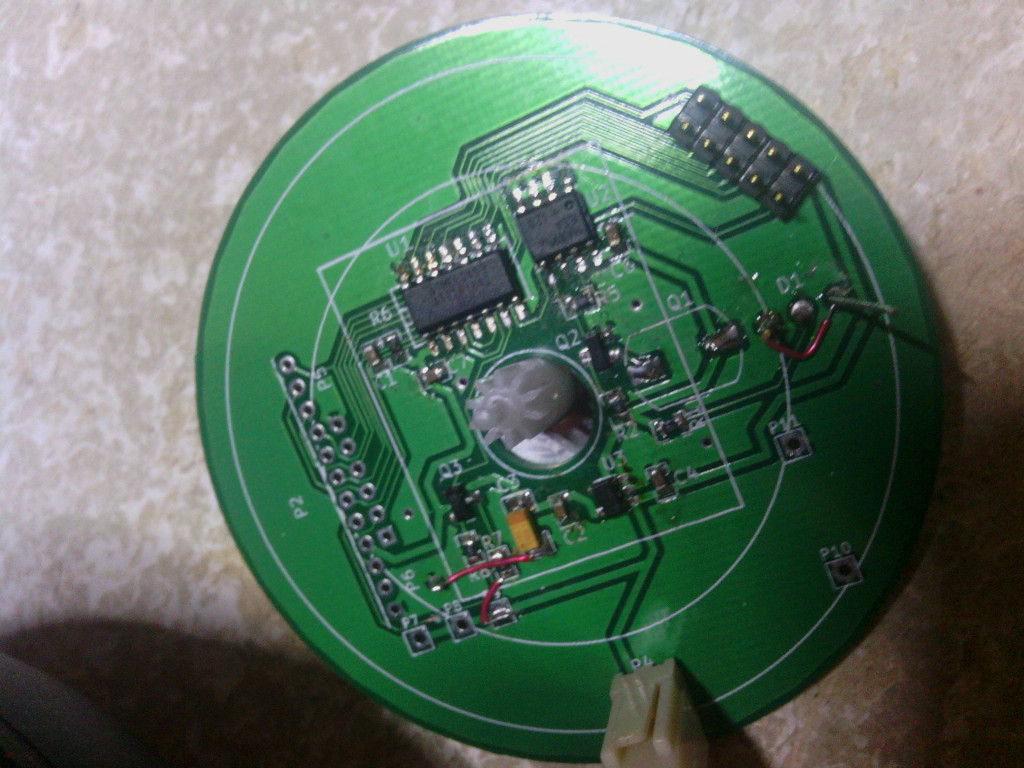
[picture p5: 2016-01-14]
Documentation/Topside-of-Meter-Board-v1.jpg

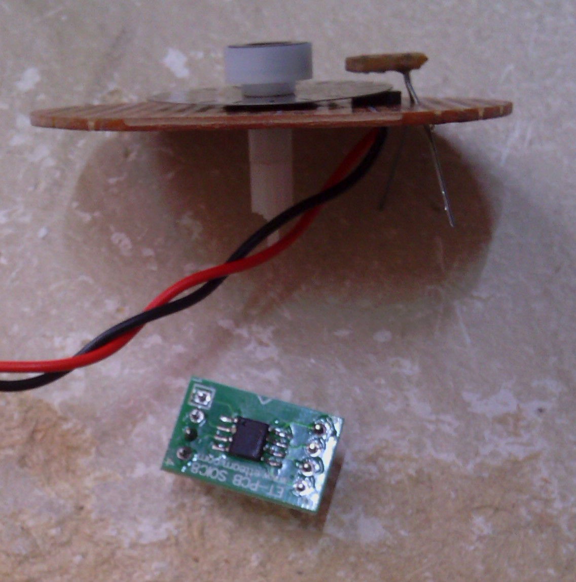
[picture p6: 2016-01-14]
Documentation/Side-View-of-Prototype-Meter-Board.jpg

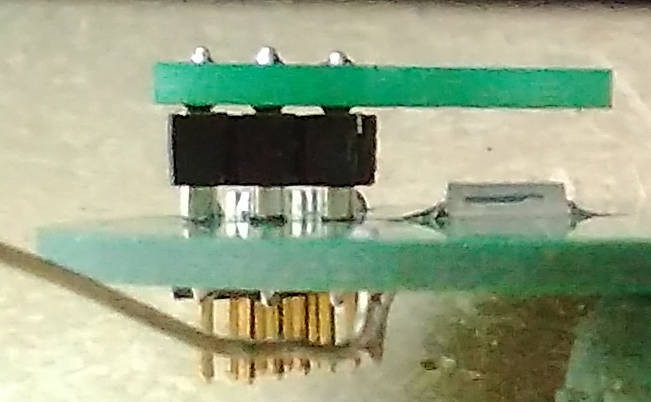
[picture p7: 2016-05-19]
Documentation/LED-mounting-side.jpg

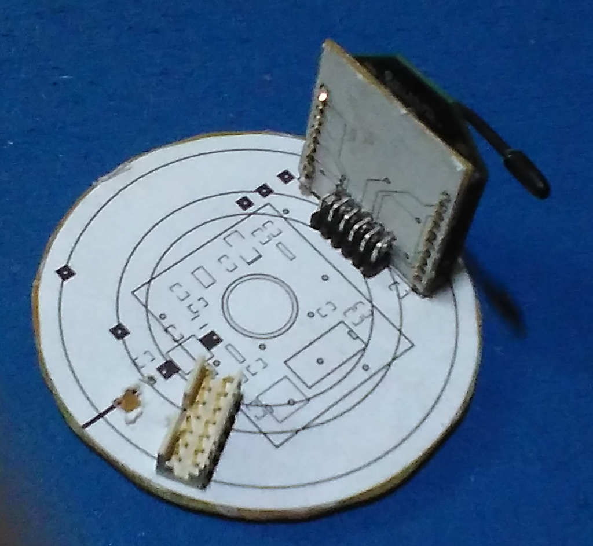
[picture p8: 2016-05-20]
Documentation/Mockup-1.jpg

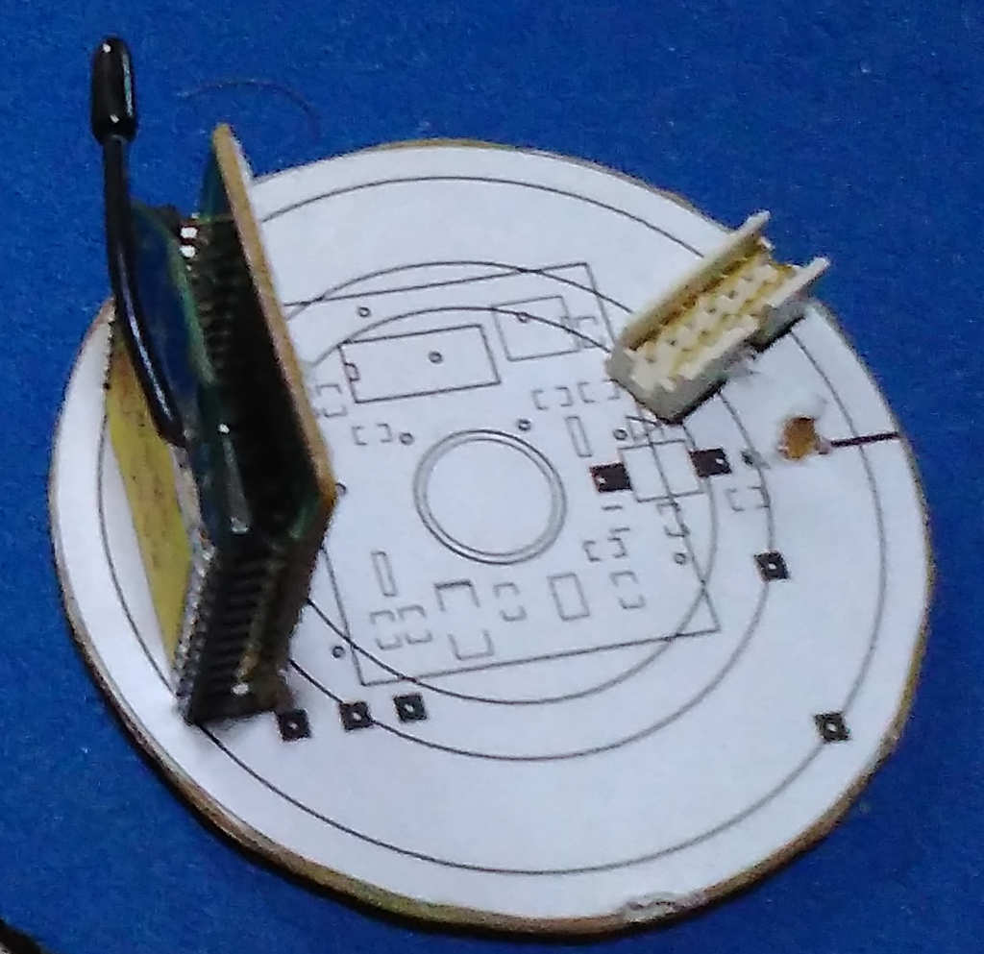
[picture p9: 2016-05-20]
Documentation/Mockup-2.jpg

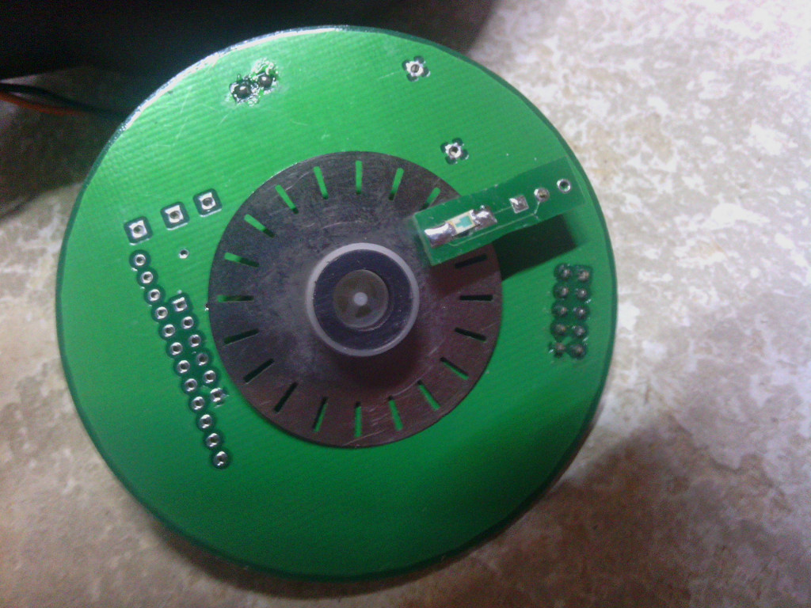
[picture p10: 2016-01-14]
Documentation/Underside-of-Meter-Board-v1.jpg

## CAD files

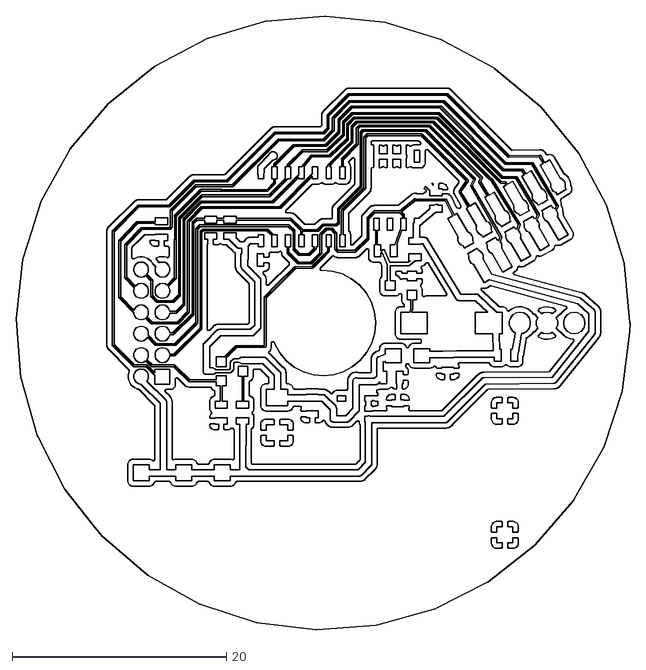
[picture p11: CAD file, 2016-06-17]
Kicad-Main/dxf/xbee-node-attiny841-F.Cu.dxf
57.4 x 57.4

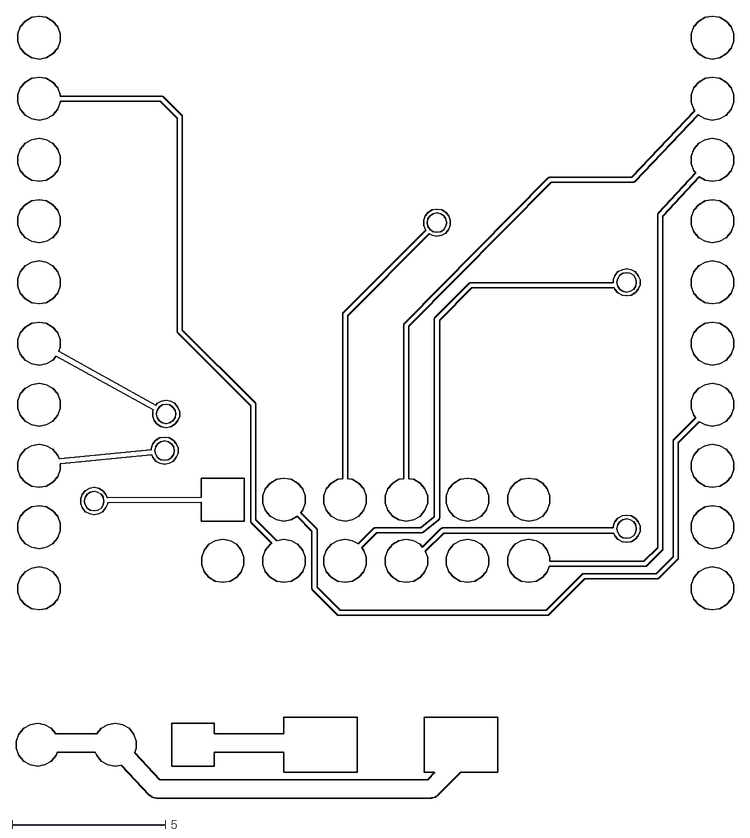
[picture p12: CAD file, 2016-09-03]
Kicad-Mounts/dxf/Kicad-mounts-B.Cu.dxf
23.4 x 25.6

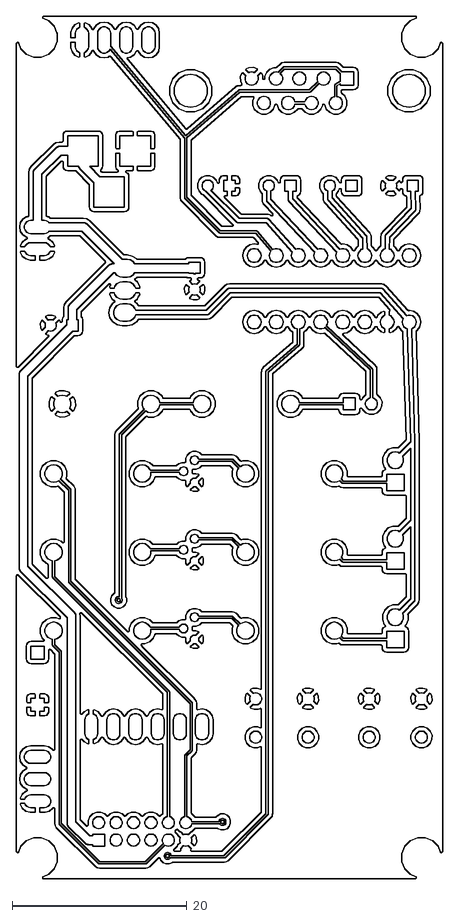
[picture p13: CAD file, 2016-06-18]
Kicad-TestBoard/dxf/Kicad-TestBoard-F.Cu.dxf
48.8 x 98.8

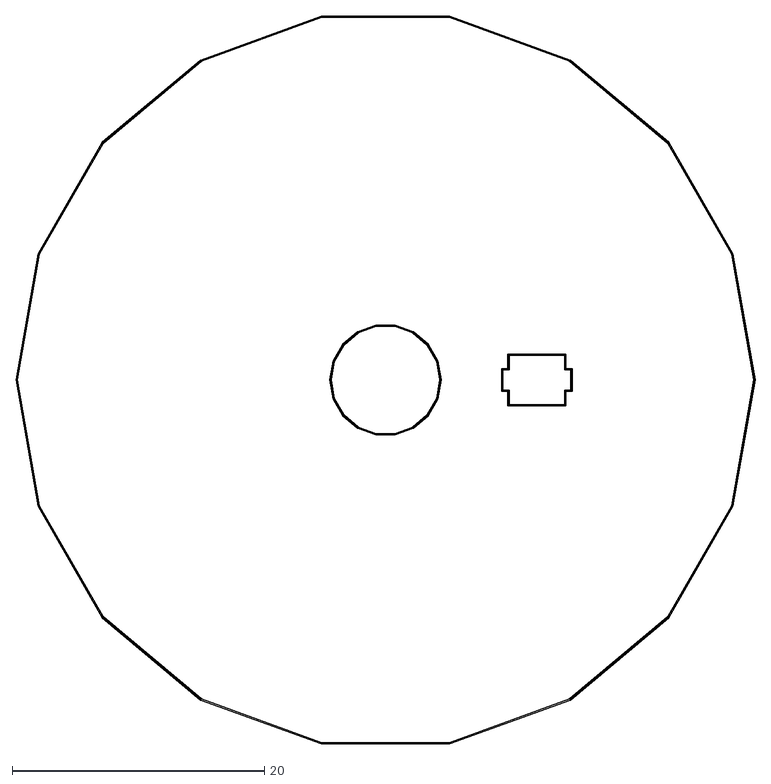
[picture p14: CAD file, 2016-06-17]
Kicad-Main/dxf/xbee-node-attiny841-Edge.Cuts.dxf
58.6 x 57.7

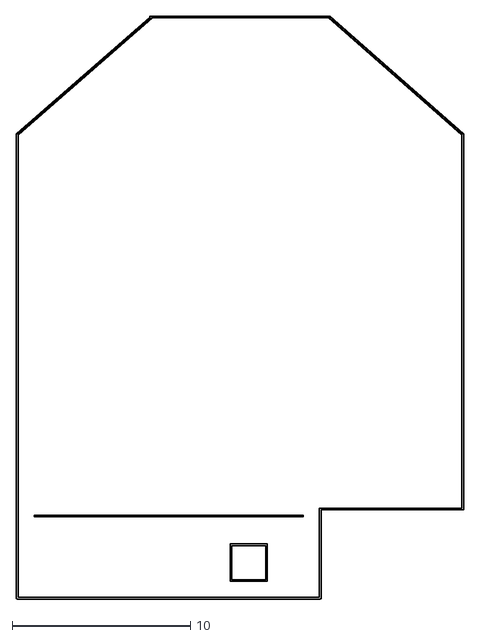
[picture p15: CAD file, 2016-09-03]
Kicad-Mounts/dxf/Kicad-mounts-Edge.Cuts.dxf
25.1 x 32.7

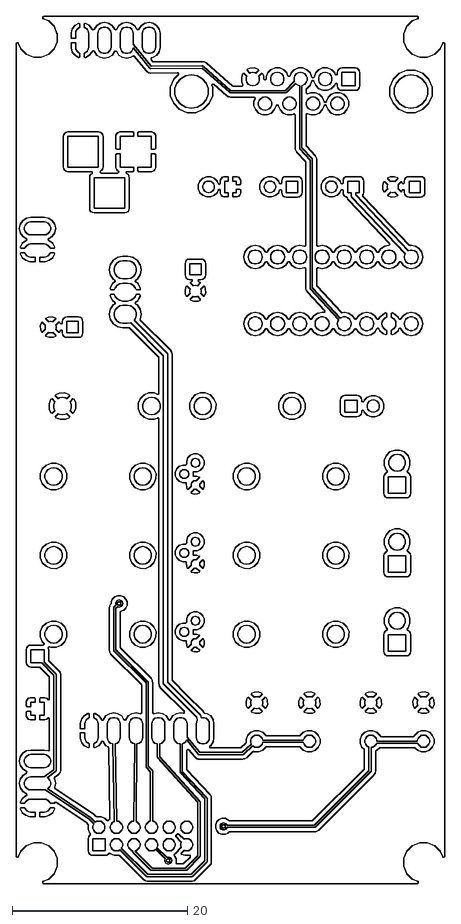
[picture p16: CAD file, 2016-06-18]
Kicad-TestBoard/dxf/Kicad-TestBoard-B.Cu.dxf
48.8 x 98.8

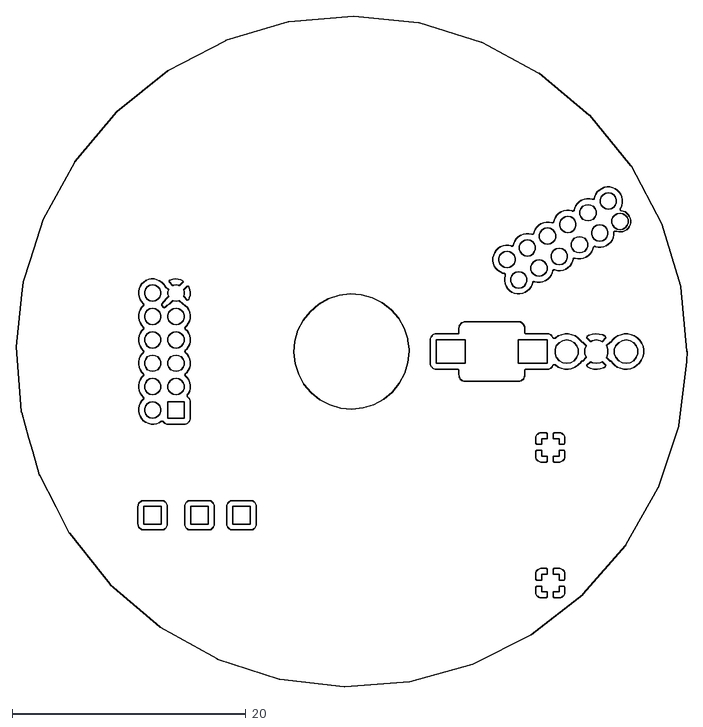
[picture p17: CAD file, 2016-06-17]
Kicad-Main/dxf/xbee-node-attiny841-B.Cu.dxf
57.4 x 57.4

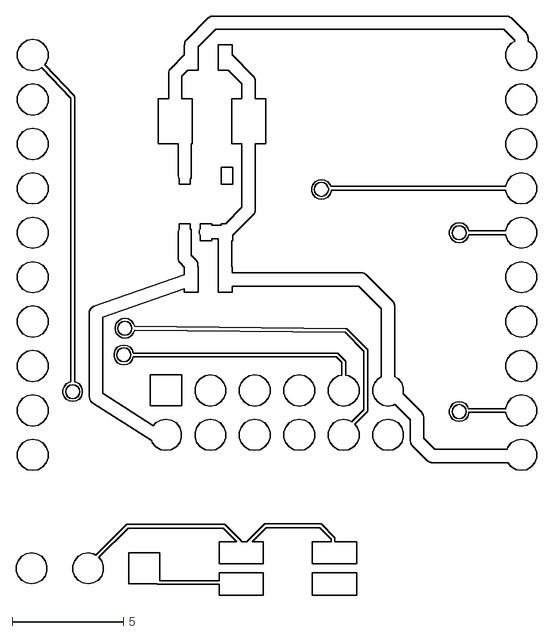
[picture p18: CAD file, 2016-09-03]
Kicad-Mounts/dxf/Kicad-mounts-F.Cu.dxf
23.4 x 26.1

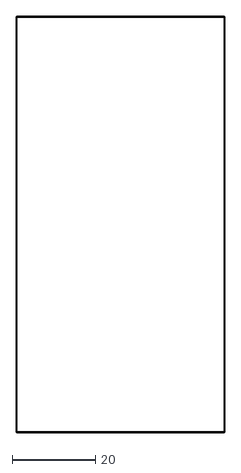
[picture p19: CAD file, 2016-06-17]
Kicad-TestBoard/dxf/Kicad-TestBoard-Edge.Cuts.dxf
50.1 x 100.1

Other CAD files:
Kicad-Main/dxf/xbee-node-attiny841-B.Mask.dxf
Kicad-Main/dxf/xbee-node-attiny841-B.SilkS.dxf
Kicad-Main/dxf/xbee-node-attiny841-F.Mask.dxf
Kicad-Main/dxf/xbee-node-attiny841-F.SilkS.dxf
Kicad-Mounts/dxf/Kicad-mounts-B.Mask.dxf
Kicad-Mounts/dxf/Kicad-mounts-B.SilkS.dxf
Kicad-Mounts/dxf/Kicad-mounts-B_SilkS.dxf
Kicad-Mounts/dxf/Kicad-mounts-F.Mask.dxf
Kicad-Mounts/dxf/Kicad-mounts-F.SilkS.dxf
Kicad-TestBoard/dxf/Kicad-TestBoard-B.SilkS.dxf
Kicad-TestBoard/dxf/Kicad-TestBoard-F.SilkS.dxf

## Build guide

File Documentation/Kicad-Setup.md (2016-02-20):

KiCad Installation and Setup
----------------------------

GRUMBLE 17/2/2016. Rather regret having chosen KiCad EDA for this job. Although
it has an excellent user interface and is very comprehensive, the configuration
of KiCad can change over time and older files don't load correctly. There appear
to be configuration files hidden away that are not removed or replaced between
reinstalls, making the correction of problems difficult. The developers seem
too ready to make changes without warning that adversely affect users. Many
forum posts echo similar sentiments.

POLICY
------

The best way to use KiCad it seems is not to rely on the provided footprint
or symbol libraries, but to keep all footprints and symbols in local libraries,
stored with the job, that will remain static over time and between different
installations.

Refer to http://kicad-pcb.org/help/documentation/ for all instructions on setup.

INSTALL KICAD
-------------

Check with 'whereis kicad' to see if any bits are still around from previous
installs. Delete all these.

Install latest version of KiCad. Recommended that the latest stable version be
installed but the unstable versions may be OK. From the current documentation
(check that these are still valid) this installs the stable release 4:

$ sudo add-apt-repository --yes ppa:js-reynaud/kicad-4

$ sudo apt-get update

$ sudo apt-get install kicad

This installed 4.0.2-4+6225~38~ubuntu14.04.1. Ubuntu has at this time a stable
version from 2013 that predates a major change to the way libraries are managed.

This is normally all that is needed for new installations. Download the KiCad
project files and open the .pro file in KiCad.

Starting KiCad directly sets up some default environment variables, but these
can be invalid depending on the history of how KiCad was installed in the past.
In Preferences/Configure Paths the default variables can be set.

The following script kicad-start will setup the environment variables needed to
access the existing libraries for CvPcb. Use this if the libraries aren't
correctly set by default (this may happen if past history has had configuration
problems). In CvPcb Preferences/Configure Paths the default variables can also
be set. Sometimes these don't seem to be used, so the script may be essential
in some cases.

	KIGITHUB=https://github.com/KiCad
	export KIGITHUB
	KISYSMOD=/usr/share/kicad/modules/
	export KISYSMOD
	kicad

SETUP CvPcb
-----------

This utility provides linking of schematic symbols with footprints. It must be
setup correctly to be able to access footprint libraries.

The documentation states that a fp-lib-table file should be present in the home
directory, containing references to all footprint libraries. However this
doesn't seem to be necessary during normal use. It may be accessed when CvPcb is
first started and is used to define the libraries. If not present some default
file will be created. The location of the working library definitions is
unknown.

Invoke from EESCHEMA in Tools/Assign Component Footprint.

If old GitHub libraries had been defined and do not match the existing GitHub
library names, then an error window appears. Take note of all the mentioned
libraries that were "not found". Close the window and in CvPcb open
Preferences/Footprint Libraries. The window should show all the libraries that
are defined. Delete those that were not found (if they were on GitHub) or
correct the library entry otherwise. Other GitHub libraries can be added
directly or via the wizard.

Any other entries may be deleted as desired if they are not needed.

On a new installation the wizard can be used to access the GitHub or locally
stored libraries. The GitHub libraries may be downloaded to a local directory
for use with the current project or for all projects. This avoids the need to
access Internet. Select Preferences/Footprint Libraries and select "Append with
Wizard". Remove any previous GitHub entries.

Footprints can be copied directly from the GitHub libraries to the local
library. If a PCB is provided, then the footprints in that file can be saved to
a local library. Right-click on each footprint, select the footprint menu and
select "Edit with Footprint Editor". It can then be edited and/or saved to the
desired local library.

PORTABILITY
-----------

The schematic file .sch, the board file .kicad_pcb, the project file .pro,
the netlist file .net, the schematic parts files .lib and the footprints
files .kicad_mod are all that is needed.

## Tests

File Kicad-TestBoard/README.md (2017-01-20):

XBee Data Acquisition TestBoard
-------------------------------

This board is for use with the watermeter assembly. It provides power, an
interface to an AVR programmer, and a serial interface to an external PC.
LEDs are provided for association indication, on/sleep and commissioning
signals from the XBee. A reset switch for the AVR is provided.

There are pins for a CRO to view the count signal from the assembly.

Jumpers are provided as follows:

* Disconnect external serial line. This **must** be left open when the XBee is
present in the watermeter assembly otherwise both serial sources are
mutually interfering and the XBee could be damaged.

* Disconnect power to watermeter assembly. This **must** be left open when the
watermeter assembly has an on-board battery. With Lithium batteries there is a
strong chance of explosion or fire if an external voltage source is connected.

K. Sarkies
19 January 2017

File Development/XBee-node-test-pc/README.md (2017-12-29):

XBee Data Acquisition Remote Test Code
--------------------------------------

This is a POSIX system based test code for an XBee remote unit. Written in C but
embedded in a wrapper that emulates the environment for the test code.
It can be run with any XBee adapter interface board that contains a USB-serial
converter, or with an XBee carrier board having a serial interface along with an
external USB-serial converter.

Both a QT5 based emulator and an emulator based on libc are provided, the latter
being command-line only, of course. It is intended for small headless machines
running Linux such as the Raspberry Pi or BeagleBone.

The purpose is to provide a PC Linux based testbed for emulating remote system
firmware that is capable of communicating directly with an XBee over a serial
port, and working as a remote unit. The emulator is not an AVR emulator. Rather
it provides a means to run the Xbee firmware core on a PC for debugging.

NOTE: gcc is required to allow function override for timerISR.

The program runs from the command line and is located in the emulator-c/ or
emulator-qt5/ directory. A debug mode is available for extended printout.

$ ./xbee-node-test -d -P /dev/ttyUSB0 -b 38400

Where the number at the end is the baud rate of the XBee serial interface.
Change this as needed.

In command line mode, the program can only be stopped by ctl-C or process kill.

The following main program modules allow different tests to be run. Follow the
instructions in the emulator directory README documentation to compile the
different tests.

***mainprog-test***
-------------------

This is taken from the [xbee-node-test](https://github.com/ksarkies/XBee-Acquisition/tree/master/XBee-node-test) code.

***mainprog-firmware***
-----------------------

This is taken from the [xbee-firmware](https://github.com/ksarkies/XBee-Acquisition/tree/master/XBee-firmware) code.

***ADAPTATION TO OTHER TEST CODE***
-----------------------------------

The following files may be used as the environment emulator for other code tests
with appropriate adaption of the makefiles and mainprog-*.cpp files. For QT5:

* xbee-node-test-main.cpp
* xbee-node-test.cpp
* xbee-node-test.h
* xbee-node-test.ui
* serial-libs.cpp
* xbee-libs.cpp
* xbee-node-test.pro - qmake definitions for generating makefile

For C:

* xbee-node-test.c
* xbee-node-test.h
* xbee-node-test.pro
* serial-libs.c
* CMakeLists.txt  - cmake definitions for generating makefile

**serial-libs.cpp** and **serial-libs.c** are substitute sets of communication
functions calling on POSIX/QT serial I/O. These should contain functions that
match the calls in the test code.

**xbee-libs.cpp** is a file associated with the code under test, which has been
copied from the library directory with its extension changed from c to cpp to
satisfy the g++ compiler (otherwise it is not correctly linked).

**xbee-lib.c** and **mainprog-*.c** are include wrappers used to force C
compilation on cpp source files.

**mainprog-*.cpp** are common to both emulators. They must be provided with the
code to be tested in the following way:

Split the code to be tested into an initialization part and an operational
part that normally falls within an infinite loop. Place the initialization part
into the function called mainprogInit(), and the operational part into
mainprog(). Both these are called from the xbee-node-test wrapper, with the
operational part having its loop emulated in the wrapper code.

There should be no compilable processor specific statements. These can be
replaced by a call to a local function that should contain code to emulate the
statement. If this is not possible then the code is not suitable for testing in
this way.

Add all global variables as static. Add also any include files needed. These
should not contain references to any processor specific libraries or functions.

ISRs need to be changed to a function call and means to activate them devised.
A timer is emulated in the emulator code. Timer initialization is done by
calling an initialization function in the emulator code. This function
sets the number of one millisecond tick counts at which the timer fires and
calls the ISR. If a timer ISR is not defined, a null ISR is substituted. The
timer ISR can be defined in the test code by replacing the actual ISR call with
the function: timerISR().

K. Sarkies
3 February 2017

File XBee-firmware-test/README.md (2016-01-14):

XBee Data Acquisition Remote Firmware Test Version
--------------------------------------------------

This is the firmware for the remote unit. Written in C under avr-gcc.

The test version transmits the count of the photointerrupter at regular
intervals (1 sec) via the serial port in csv format for capture and analysis
off-line.

The Atmel version of gcc-avr needs to be placed into the auxiliary directory
and referenced in the Makefile as the open source version doesn't support
the ATTiny841.

The defines used are placed in the libs directory under each processor. The
makefile target is the ATMega168 by default. To use another target eg ATTiny841

$ make MCU=attiny841

The environment variable MCU_TYPE is passed to the source.

K. Sarkies
28 February 2015

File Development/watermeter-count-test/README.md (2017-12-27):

Watermeter Count Test
---------------------

This is a test firmware for the AVR in the watermeter. Written in C under
avr-gcc.

This test transmits the count of the photointerrupter at regular
intervals (1 sec) via the serial port at 9600 baud in csv format for capture
and analysis off-line. This link is normally connected to an XBee in the
watermeter assembly. The test can ONLY be used where the XBee is not present
and the serial link is brought out to a PC serial port.

Open source versions of avr-libc earlier than release 2.0.0 did not support the
ATTiny841 series. To get around this, either compile and install the latest
version of avr-libc, or place the latest Atmel toolchain into a directory
somewhere where it can be referenced in the Makefile. Change the DIRAVR
environment variable in Makefile to suit the location chosen.

The defines used are placed in the libs directory under each processor.
The makefile target is attiny841 by default. To use another target eg ATMega48.

$ make MCU=atmega48

The environment variable MCU_TYPE is passed to the source.

K. Sarkies
7 December 2016

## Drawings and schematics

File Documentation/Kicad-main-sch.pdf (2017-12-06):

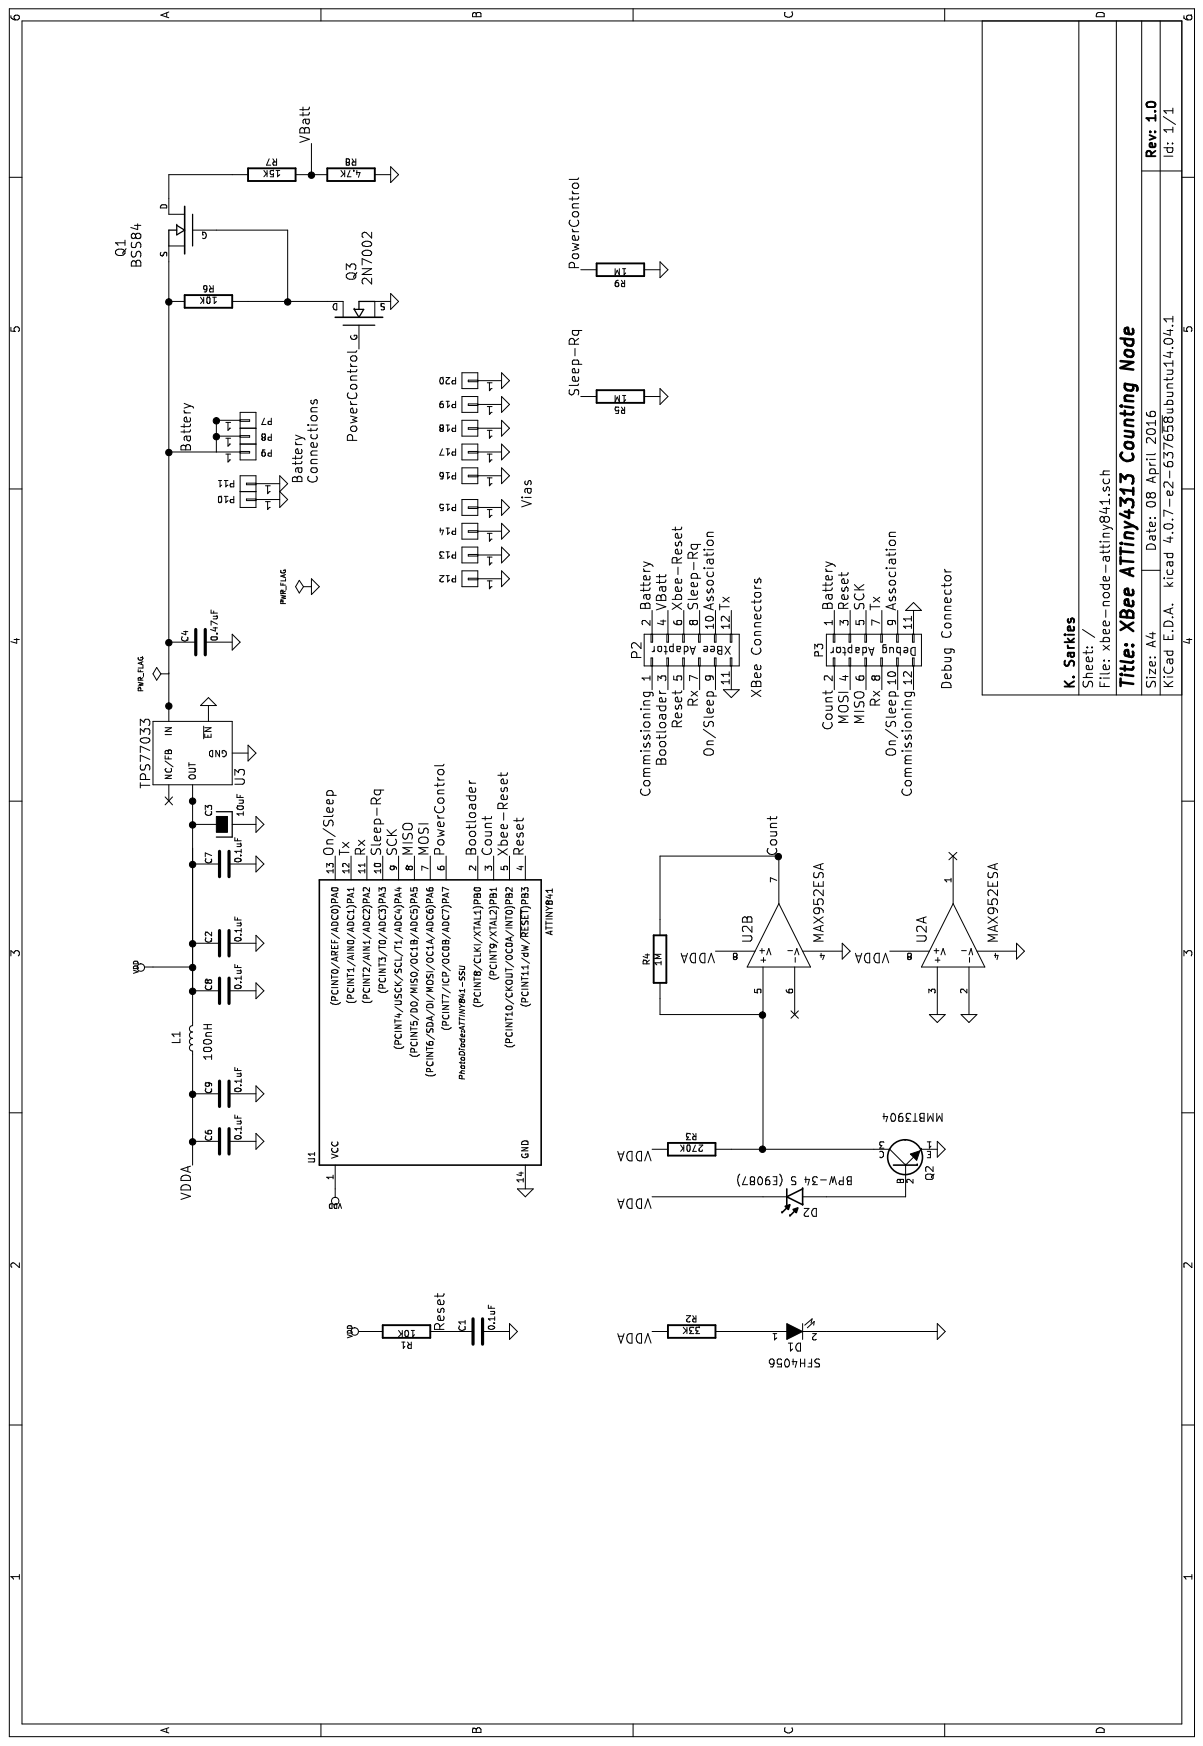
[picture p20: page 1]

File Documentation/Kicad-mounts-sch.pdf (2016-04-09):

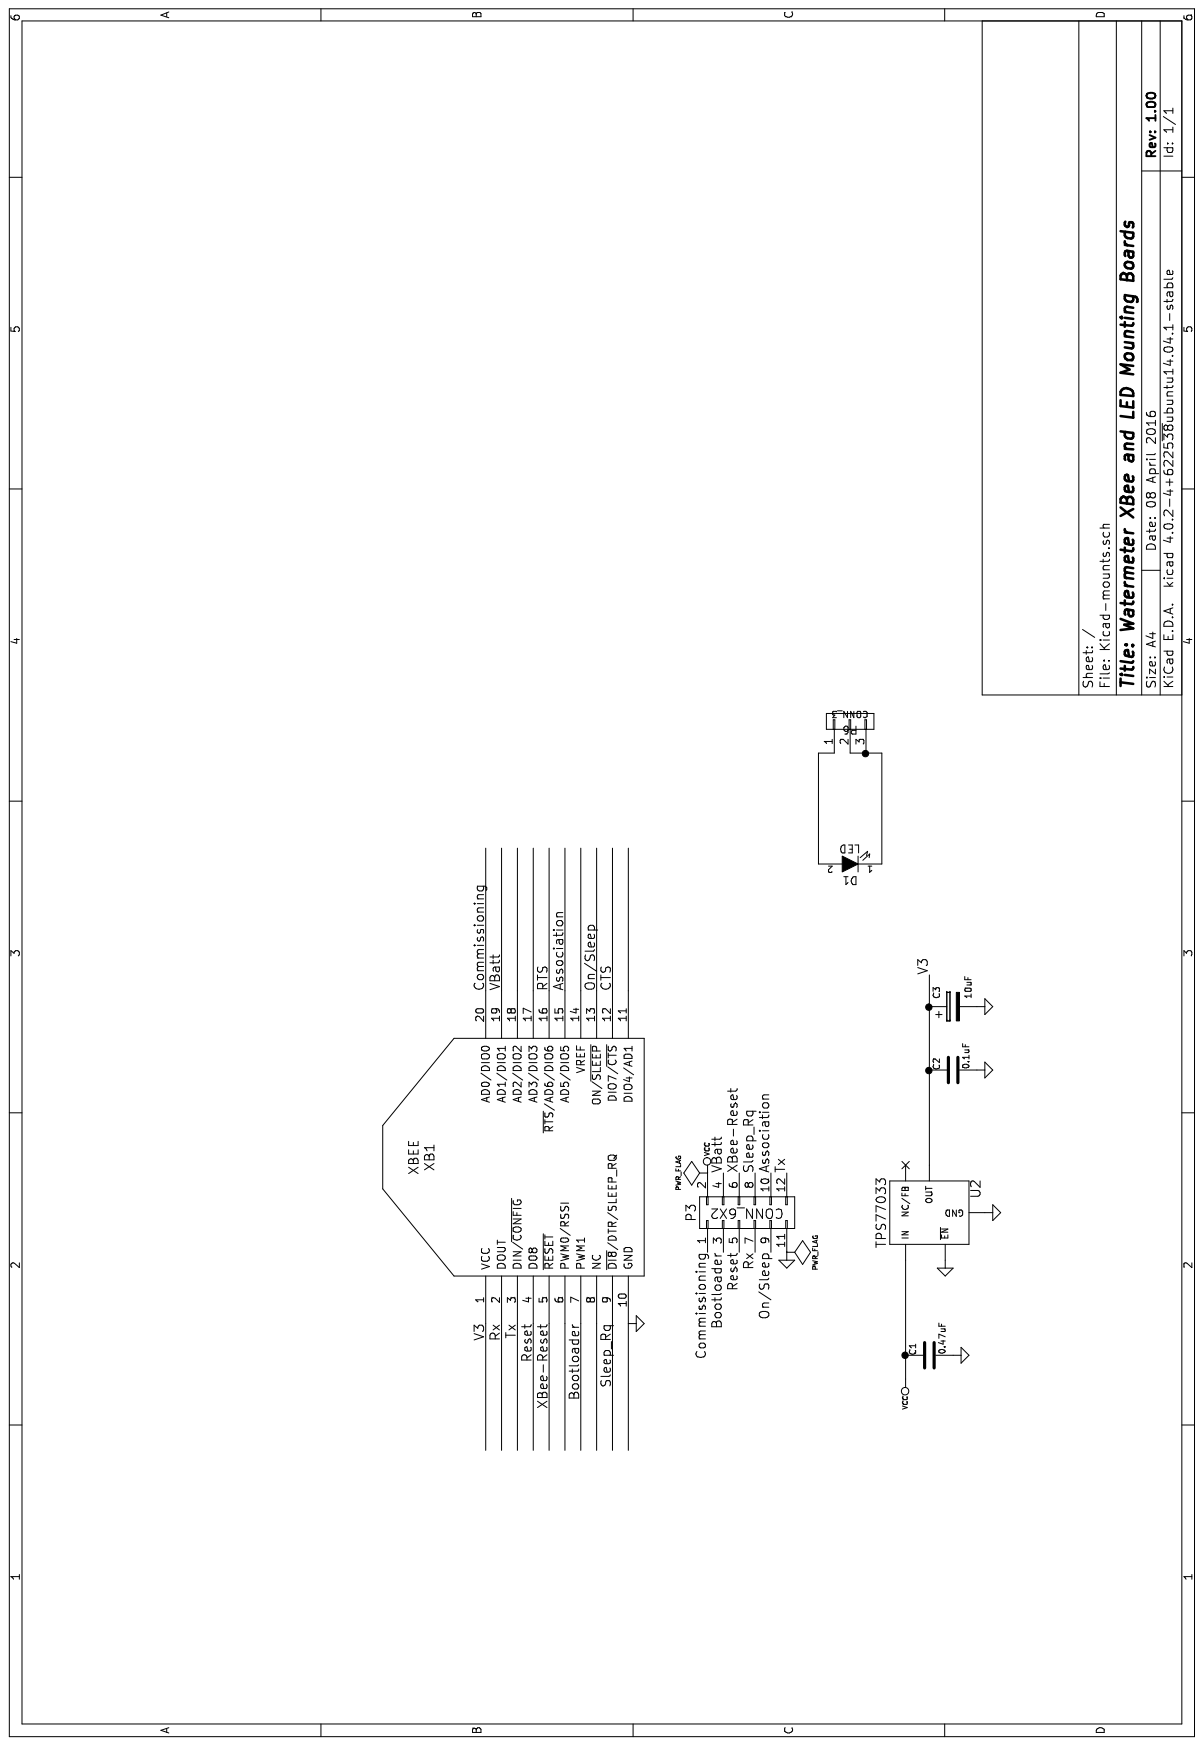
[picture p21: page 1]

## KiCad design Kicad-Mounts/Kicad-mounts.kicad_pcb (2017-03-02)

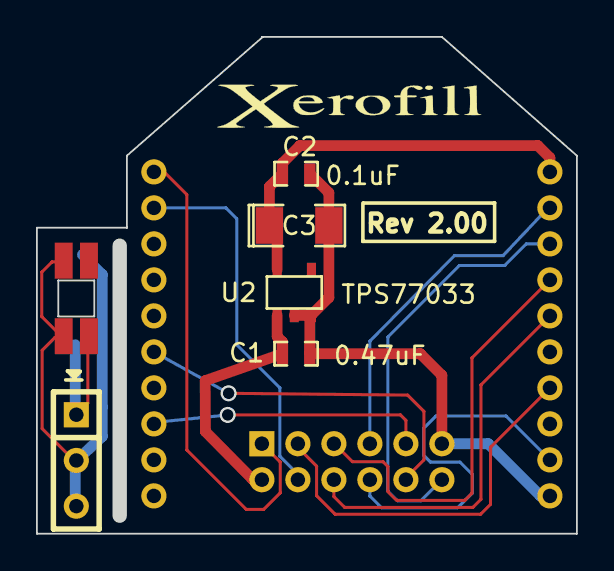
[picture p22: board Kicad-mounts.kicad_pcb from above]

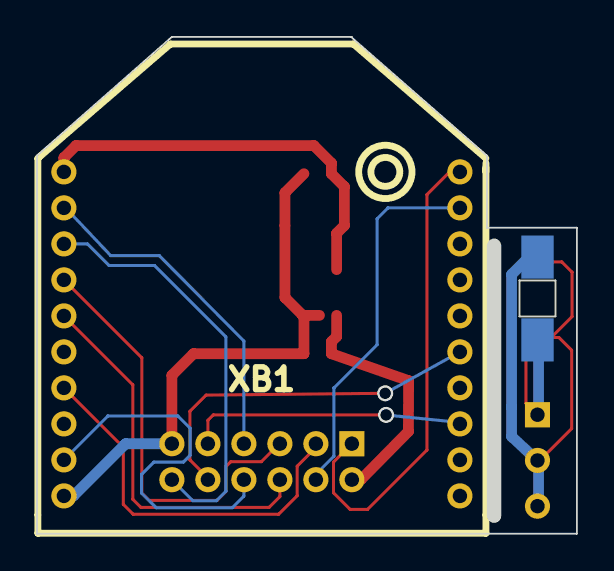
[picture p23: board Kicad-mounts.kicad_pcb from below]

Board: 2 copper layers, 30.0 x 27.6 mm, 8 parts (2 on the bottom side), 15 nets.

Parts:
C1: 0.47uF; SMD-0603_c
C2: 0.1uF; SMD-0603_c
C3: 10uF; SMD-1206_Pol
D1: LED; LED-mount
P3: CONN_6X2; pin_header_2mm_2x6
P6: CONN_3; SIL-3
U2: TPS77033; SOT-23-5
XB1: XBEE; XBee

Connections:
/Association: P3.10, XB1.15
/Bootloader: P3.3, XB1.7
/Commissioning: P3.1, XB1.20
/On/Sleep: P3.9, XB1.13
/Reset: P3.5, XB1.4
/Rx: P3.7, XB1.2
/Sleep_Rq: P3.8, XB1.9
/Tx: P3.12, XB1.3
/V3: C2.1, C3.1, U2.5, XB1.1
/VBatt: P3.4, XB1.19
/XBee-Reset: P3.6, XB1.5
GND: C1.2, C2.2, C3.2, P3.11, U2.2, U2.3, XB1.10
unnamed: D1.1, P6.2, P6.3
unnamed: D1.2, P6.1
VCC: C1.1, P3.2, U2.1

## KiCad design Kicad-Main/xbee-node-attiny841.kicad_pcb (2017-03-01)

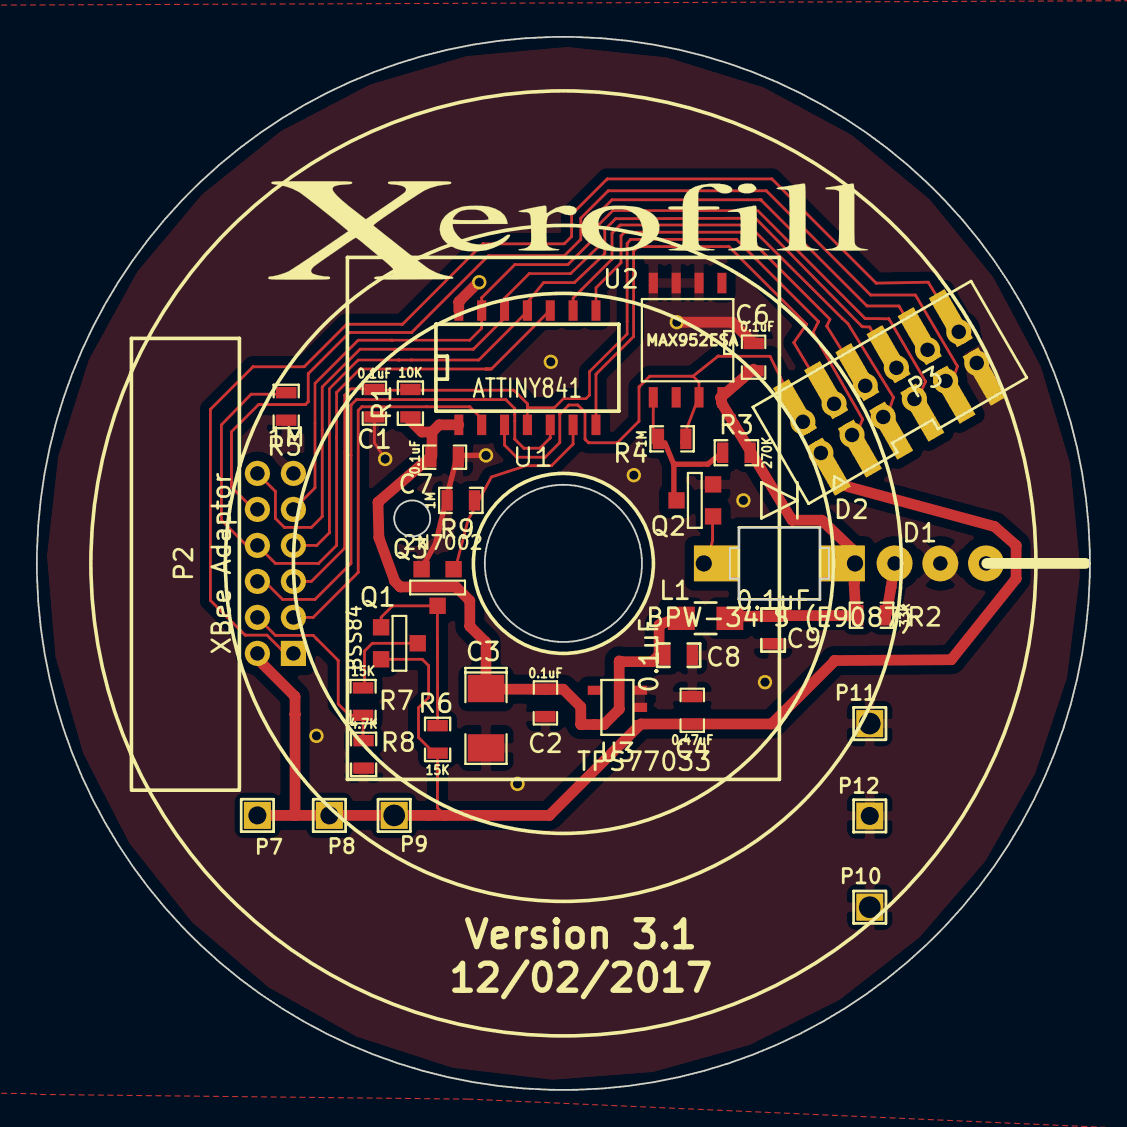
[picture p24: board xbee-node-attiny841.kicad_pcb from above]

Board: 2 copper layers, 58.5 x 58.5 mm, 44 parts (0 on the bottom side), 24 nets.

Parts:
C1, C2, C6, C7: 0.1uF; SM0603_Capa
C3: 10uF; SM1206POL
C4: 0.47uF; SM0603_Capa
C8, C9: 0.1uF; SMD-0603_c
D1: SFH4056; LED-Mount
D2: BPW-34 S (E9087); BPW34
L1: 100nH; R_0805
P2: XBee Adaptor; pin_header_2mm_2x6
P3: Debug Adaptor; pin_smd_header_2mm_2x6
P7, P8, P9, P10, P11, P12: CONN_1; SIL-1
P12#2, P13, P14, P15, P16, P17, P18, P19, P20: CONN_1; THROUGHVIA
Q1: BSS84; SOT23GDS
Q2: MMBT3904; SOT23EBC
Q3: 2N7002; SOT23GDS
R1: 10K; SM0603_Resistor
R2: 33K; SM0603_Resistor
R3: 270K; SM0603_Resistor
R4, R5, R9: 1M; SM0603_Resistor
R6, R7: 15K; SM0603_Resistor
R8: 4.7K; SM0603_Resistor
Ref**: Val**; THROUGHVIA
U1: ATTINY841; ATTINY841-SSU
U2: MAX952ESA; SO8N
U3: TPS77033; SOT23-5

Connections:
/Association: P2.10, P3.9
/Battery: C4.1, P2.2, P3.1, P7.1, P8.1, P9.1, Q1.S, R6.1, U3.1
/Bootloader: P2.3, U1.2
/Commissioning: P2.1, P3.12
/Count: P3.2, R4.2, U1.3, U2.7
/MISO: P3.6, U1.8
/MOSI: P3.4, U1.7
/On/Sleep: P2.9, P3.10, U1.13
/PowerControl: Q3.G, R9.2, U1.6
/Reset: C1.1, P2.5, P3.3, R1.1, U1.4
/Rx: P2.7, P3.8, U1.11
/SCK: P3.5, U1.9
/Sleep-Rq: P2.8, R5.2, U1.10
/Tx: P2.12, P3.7, U1.12
/VBatt: P2.4, R7.2, R8.1
/VDDA: C6.1, C9.1, D2.2, L1.1, R2.1, R3.1, U2.8
/Xbee-Reset: P2.6, U1.5
GND: C1.2, C2.2, C3.2, C4.2, C6.2, C7.2, C8.2, C9.2, D1.2, P2.11, P3.11, P10.1, P11.1, P12.1, P12#2.1, P13.1, P14.1, P15.1, P16.1, P17.1, P18.1, P19.1, P20.1, Q2.1, Q3.S, R5.1, R8.2, R9.1, Ref**.1, U1.14, U2.2, U2.3, U2.4, U3.2, U3.3
unnamed: D1.1, R2.2
unnamed: D2.1, Q2.2
unnamed: Q1.D, R7.1
unnamed: Q1.G, Q3.D, R6.2
unnamed: Q2.3, R3.2, R4.1, U2.5
VDD: C2.1, C3.1, C7.1, C8.1, L1.2, R1.2, U1.1, U3.5

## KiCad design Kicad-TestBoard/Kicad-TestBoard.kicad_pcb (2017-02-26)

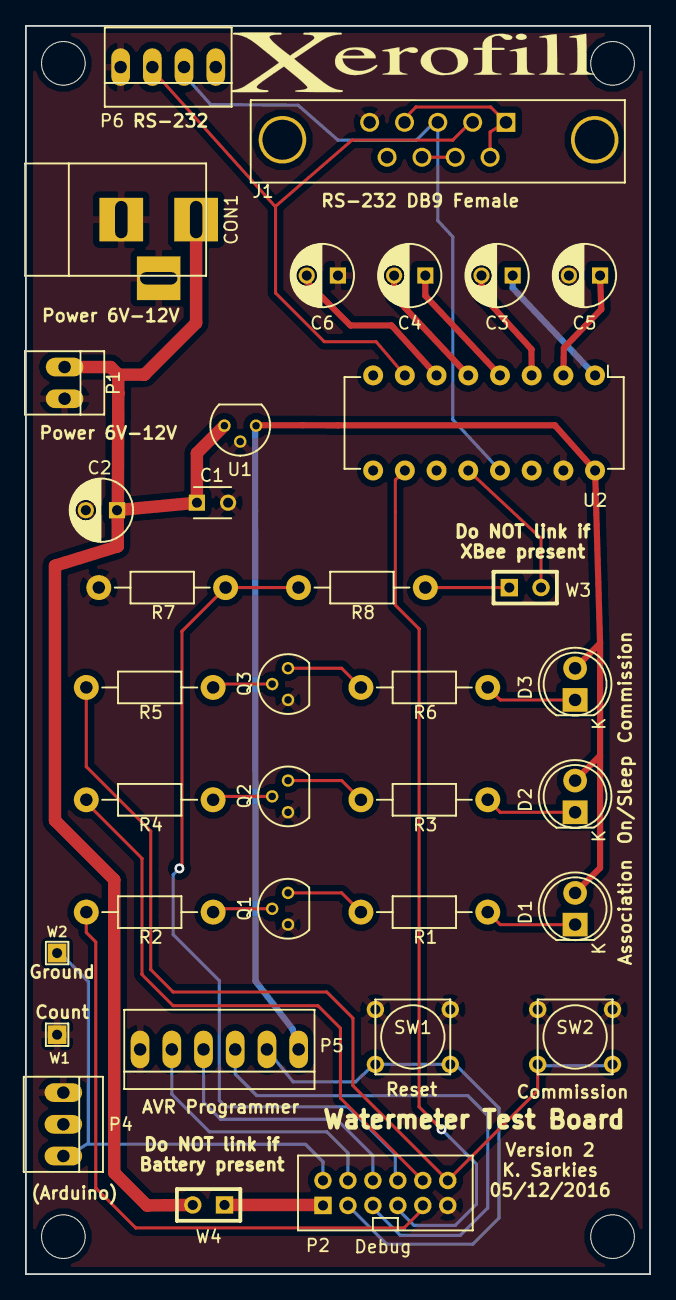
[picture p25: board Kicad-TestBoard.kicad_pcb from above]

Board: 2 copper layers, 50.0 x 100.0 mm, 35 parts (0 on the bottom side), 35 nets.

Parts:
C1: 0.1uF; C_Disc_D3_P2.5
C2: 10uF; C_Radial_D5_L11_P2.5
C3, C4, C5, C6: 1uF; C_Radial_D5_L11_P2.5
CON1: Power 6V-12V; BARREL_JACK
D1: Yellow LED; LED-5MM
D2: Green LED; LED-5MM
D3: Red LED; LED-5MM
J1: DB9 RS-232 Female; DB9FD
P1: Power 6V-12V; PINHEAD1-2
P2: Debug; pin_header_2mm_2x6_shrouded
P4: Arduino; PINHEAD1-3
P5: AVR Programmer; PINHEAD1-6
P6: RS-232; PINHEAD1-4
Q1: Association; TO-92_Molded_Narrow
Q2: On_Sleep; TO-92_Molded_Narrow
Q3: Commissioning; TO-92_Molded_Narrow
R1, R3, R6, R8: 470; Resistor_Horizontal_RM10mm
R2, R4, R5: 10K; Resistor_Horizontal_RM10mm
R7: 1K; Resistor_Horizontal_RM10mm
SW1: Reset; SW_PUSH_TINY
SW2: Commissioning; SW_PUSH_TINY
U1: 78L05; TO-92_78L05
U2: MAX232; DIP-16_W7.62mm
W1, W2: TEST_1P; SIL-1
W3, W4: Jumper; SIL-2

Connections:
/Battery: P2.1, W4.1
/Commissioning: P2.12, R5.2, SW2.2
/Count: P2.2, P4.3, W2.1
/MISO: P2.6, P5.3
/MOSI: P2.4, P5.2
/On_Sleep: P2.10, R4.2
/Reset: P2.3, P5.5, SW1.2
/Rx: P2.8, R7.1, R8.2
/SCK: P2.5, P5.4
/Tx: P2.7, U2.10
Earth: C1.2, C2.2, C5.2, C6.1, CON1.2, CON1.3, J1.5, P1.2, P2.11, P4.1, P5.1, P6.4, Q1.1, Q2.1, Q3.1, R7.2, SW1.1, SW2.1, U1.GND, U2.15, W1.1
unnamed: C1.1, C2.1, CON1.1, P1.1, U1.VI, W4.2
unnamed: C3.1, U2.1
unnamed: C3.2, U2.3
unnamed: C4.1, U2.4
unnamed: C4.2, U2.5
unnamed: C5.1, U2.2
unnamed: C6.2, U2.6
unnamed: D1.1, R1.1
unnamed: D2.1, R3.1
unnamed: D3.1, R6.1
unnamed: J1.1, J1.4, J1.6
unnamed: J1.2, P6.3, U2.7
unnamed: J1.3, P6.2, U2.13
unnamed: J1.7, J1.8
unnamed: P2.9, R2.2
unnamed: Q1.2, R2.1
unnamed: Q1.3, R1.2
unnamed: Q2.2, R4.1
unnamed: Q2.3, R3.2
unnamed: Q3.2, R5.1
unnamed: Q3.3, R6.2
unnamed: R8.1, W3.1
unnamed: U2.12, W3.2
VCC: D1.2, D2.2, D3.2, P5.6, U1.VO, U2.16

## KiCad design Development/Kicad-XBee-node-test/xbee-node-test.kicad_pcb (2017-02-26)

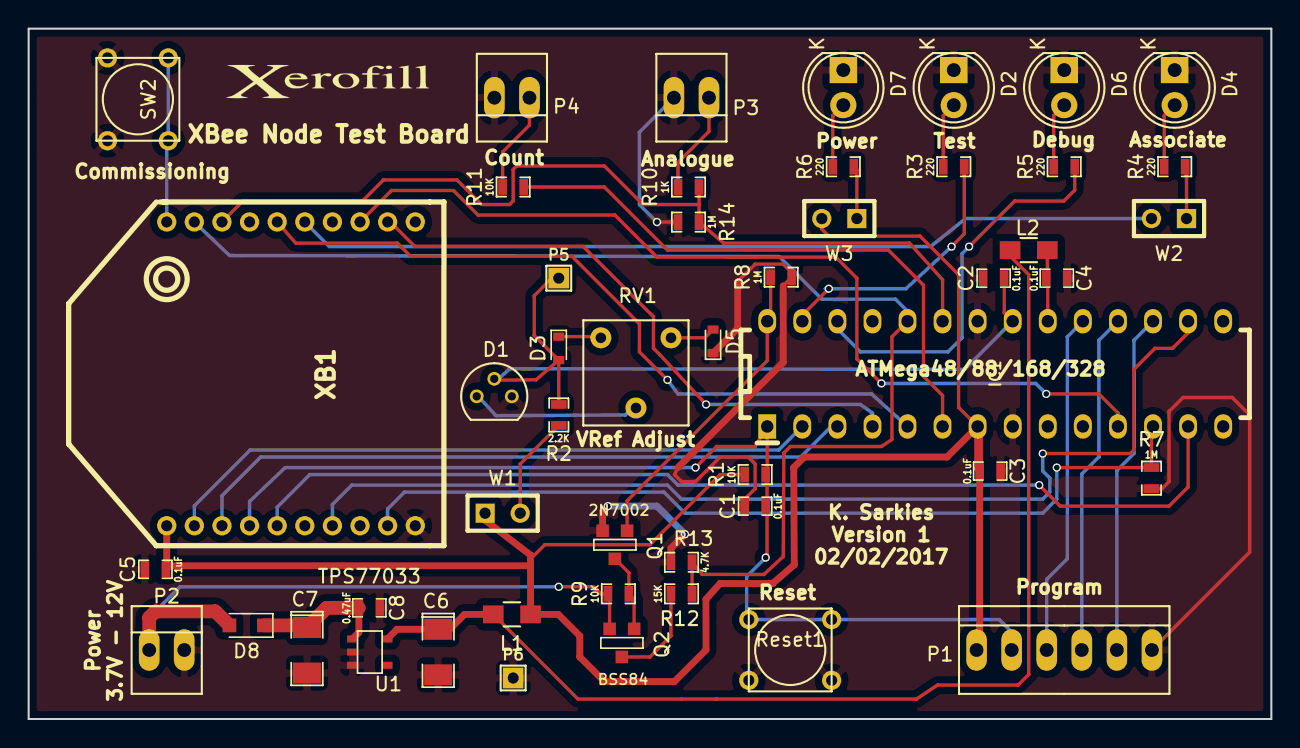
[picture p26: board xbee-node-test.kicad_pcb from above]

Board: 2 copper layers, 90.0 x 50.0 mm, 49 parts (0 on the bottom side), 41 nets.

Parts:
C1, C2, C3, C4, C5: 0.1uF; SM0603_Capa
C6, C7: 10uF; SM1206POL
C8: 0.47uF; SM0603_Capa
D1: LM336-2.5V; TO-92_LM336
D2: Test; LED-5MM
D3, D5: 1N4148; D_0603
D4: Associate; LED-5MM
D6: Debug; LED-5MM
D7: Power; LED-5MM
D8: CUS520; D_SOD-323_HandSoldering
IC1: ATMEGA48-P; DIP-28
L1, L2: 100nH; R_0805
P1: Program; PINHEAD1-6
P2: Power 3.7V-12V; PINHEAD1-2
P3: Analogue; PINHEAD1-2
P4: Count; PINHEAD1-2
P5: VRef; SIL-1
P6: GND; SIL-1
Q1: 2N7002; SOT23GDS
Q2: BSS84; SOT23GDS
R1, R9, R11: 10K; SM0603_Resistor
R2: 2.2K; SM0603_Resistor
R3, R4, R5, R6: 220; SM0603_Resistor
R7, R8, R14: 1M; SM0603_Resistor
R10: 1K; SM0603_Resistor
R12: 15K; SM0603_Resistor
R13: 4.7K; SM0603_Resistor
RV1: 100K; Potentiometer_Bourns_3362F
Reset1: Reset; SW_PUSH_TINY
SW2: Commissioning; SW_PUSH_TINY
U1: TPS77033; SOT23-5
W1, W2, W3: Jumper; SIL-2
XB1: XBEE; XBee

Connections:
/ARef: C2.1, D1.2, D3.2, IC1.21, P5.1, R2.2
/AVcc: C4.1, IC1.20, L2.1
/Analogue: IC1.23, R10.2, R14.1, XB1.18
/Associate: W2.2, XB1.15
/Battery: D8.2, P2.1, Q2.S, R9.1
/Bootloader: IC1.16, XB1.7
/CTS: IC1.4, XB1.12
/Commissioning: SW2.1, XB1.20
/Counter: IC1.6, R11.2
/DEBUG: IC1.26, R5.2
/MC_Reset: C1.1, IC1.1, P1.5, R1.2, Reset1.1, XB1.4
/MISO: IC1.18, P1.3
/MOSI: IC1.17, P1.2
/On_Sleep: IC1.11, XB1.13
/RTS: IC1.5, XB1.16
/RxD: IC1.2, XB1.2
/SCK: IC1.19, P1.4
/Sleep_RQ: IC1.12, R7.1, XB1.9
/TEST: IC1.27, R3.2
/TxD: IC1.3, XB1.3
/VBAT: IC1.24, R12.2, R13.1, XB1.19
/VBAT_CTL: IC1.28, Q1.G, R8.1
/Vcc: C3.1, C5.1, IC1.7, L1.1, P1.6, R1.1, W1.1, W3.2, XB1.1
/XBee_Reset: IC1.13, XB1.5
GND: C1.2, C2.2, C3.2, C4.2, C5.2, C6.2, C7.2, C8.2, D1.3, D2.1, D4.1, D5.1, D6.1, D7.1, IC1.8, IC1.22, P1.1, P2.2, P3.2, P4.2, P6.1, Q1.S, R7.2, R8.2, R13.2, R14.2, Reset1.2, SW2.2, U1.2, U1.3, XB1.10
unnamed: C6.1, L1.2, L2.2, U1.5
unnamed: C7.1, C8.1, D8.1, U1.1
unnamed: D1.1, RV1.2
unnamed: D2.2, R3.1
unnamed: D3.1, RV1.3
unnamed: D4.2, R4.1
unnamed: D5.2, RV1.1
unnamed: D6.2, R5.1
unnamed: D7.2, R6.1
unnamed: P3.1, R10.1
unnamed: P4.1, R11.1
unnamed: Q1.D, Q2.G, R9.2
unnamed: Q2.D, R12.1
unnamed: R2.1, W1.2
unnamed: R4.2, W2.1
unnamed: R6.2, W3.1

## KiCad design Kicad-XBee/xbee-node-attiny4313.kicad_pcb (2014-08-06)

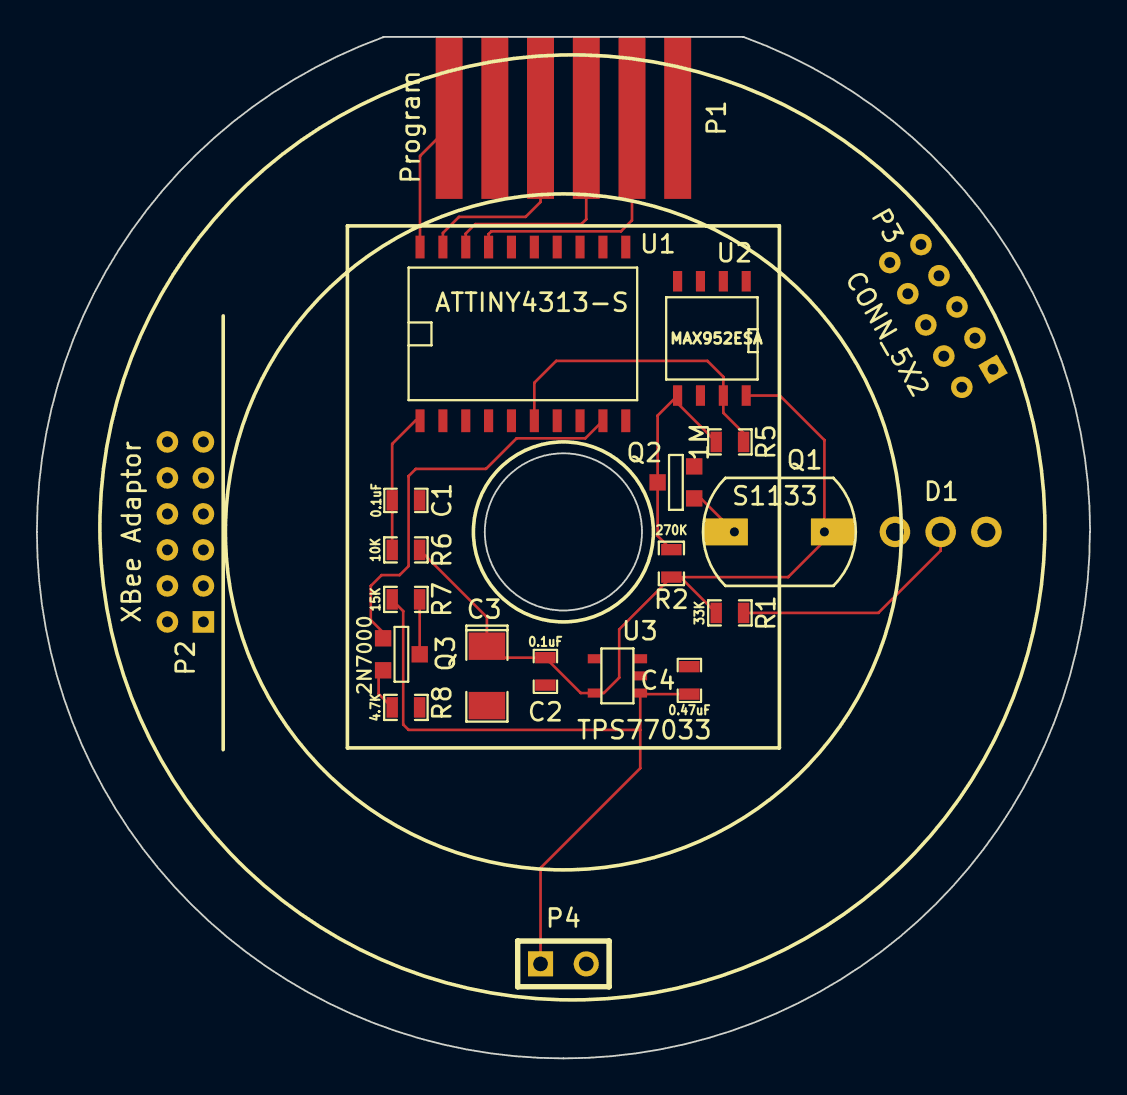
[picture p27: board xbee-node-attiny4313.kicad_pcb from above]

Board: 2 copper layers, 58.5 x 56.8 mm, 21 parts (0 on the bottom side), 22 nets.

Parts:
C1, C2: 0.1uF; SM0603_Capa
C3: 10uF; SM1206POL
C4: 0.47uF; SM0603_Capa
D1: APD3224ZGC-F01; LED-Mount
P1: Program; edge_conn_6_pin
P2: XBee Adaptor; pin_header_2mm_2x6
P3: CONN_5X2; pin_header_2mm_2x5
P4: Battery; SIL-2
Q1: S1133; S1133TH
Q2: S9014; SOT23EBC
Q3: 2N7000; SOT23GDS
R1: 33K; SM0603_Resistor
R2: 270K; SM0603_Resistor
R5: 1M; SM0603_Resistor
R6: 10K; SM0603_Resistor
R7: 15K; SM0603_Resistor
R8: 4.7K; SM0603_Resistor
U1: ATTINY4313-S; SO20L
U2: MAX952ESA; SO8N
U3: TPS77033; SOT23-5

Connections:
/Bootloader: P2.7, U1.16
/CTS: P2.4, U1.4
/On/Sleep: P2.8, P3.6, U1.13
/RTS: P2.6, U1.5
/Reset: C1.1, P1.5, P2.9, P3.7, R6.1, U1.1
/Rx: P2.3, P3.1, U1.2
/Sleep-Rq: P2.2, P3.2, U1.15
/Tx: P2.5, P3.3, U1.3
/VBatt: C4.1, P2.12, P3.10, P4.1, R7.1, U3.1
/Xbee-Reset: P2.10, P3.8, U1.14
GND: C1.2, C2.2, C3.2, C4.2, D1.1, P1.1, P2.11, P3.9, P4.2, Q2.1, R8.2, U1.10, U2.2, U2.3, U2.4, U3.2, U3.3
unnamed: D1.2, R1.2
unnamed: P1.2, U1.17
unnamed: P1.3, U1.18
unnamed: P1.4, U1.19
unnamed: P3.5, R5.2, U1.6, U2.7
unnamed: Q1.1, Q2.2
unnamed: Q2.3, R2.2, R5.1, U2.5
unnamed: Q3.D, R7.2
unnamed: Q3.G, U1.9
unnamed: Q3.S, R8.1
VDD: C2.1, C3.1, P1.6, P2.1, Q1.3, R1.1, R2.1, R6.2, U1.20, U2.8, U3.5

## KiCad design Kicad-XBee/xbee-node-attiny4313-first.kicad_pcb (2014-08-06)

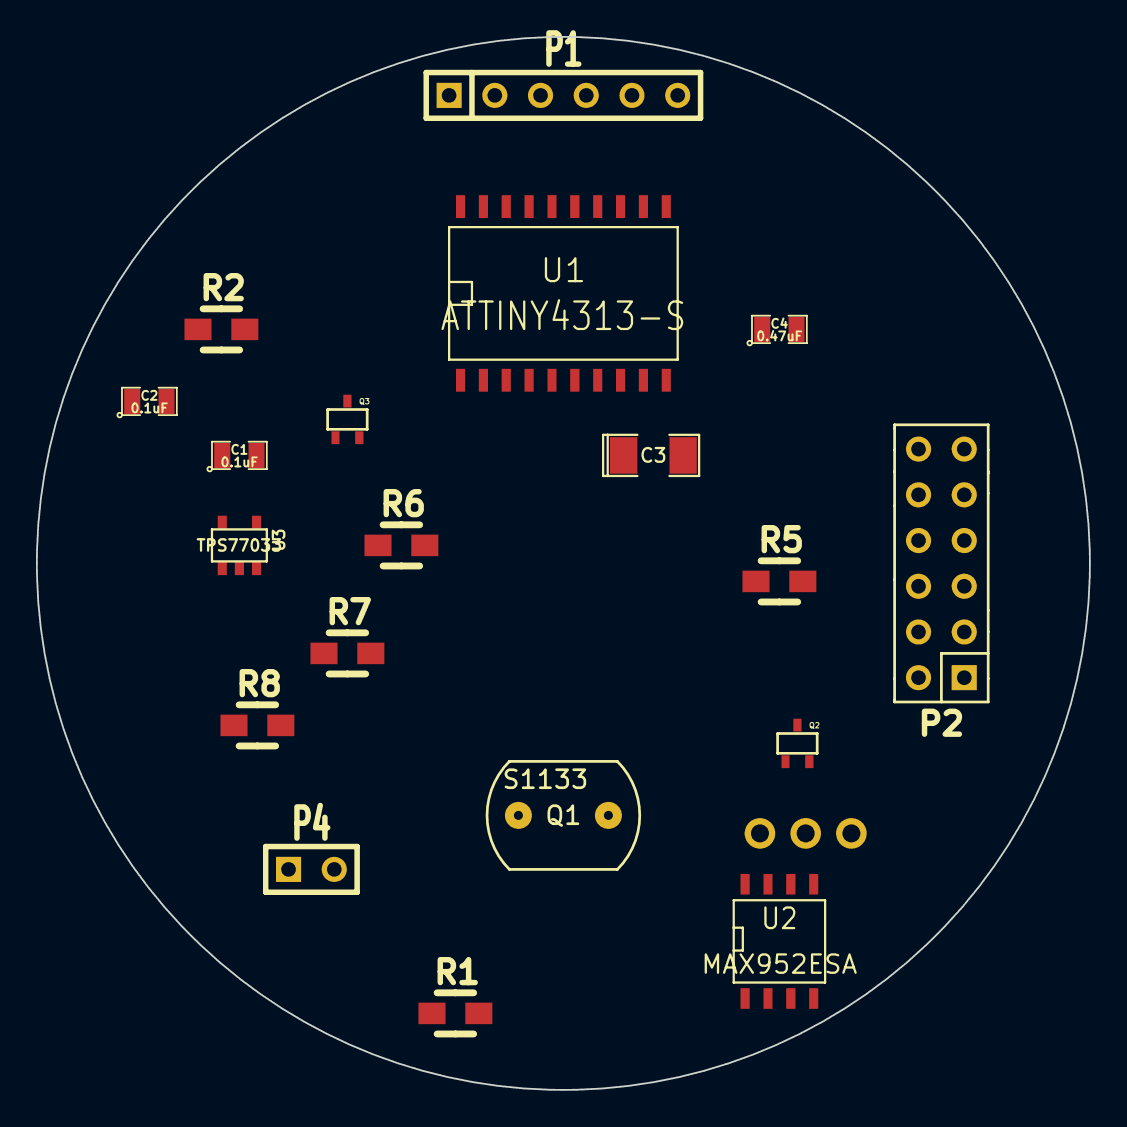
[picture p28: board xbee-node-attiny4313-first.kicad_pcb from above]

Board: 2 copper layers, 58.5 x 58.5 mm, 19 parts (0 on the bottom side), 18 nets, no tracks yet.

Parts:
C1, C2: 0.1uF; SM0805
C3: 10uF; SM1206POL
C4: 0.47uF; SM0805
P1: Program; SIL-6
P2: XBee Adaptor; CONN_2x6
P4: Battery; SIL-2
Q1: S1133; S1133TH
Q2: S9014; sc70
Q3: 2N7000; sc70
R1: 33K; Resistor_SMD0805_HandSoldering
R2: 270K; Resistor_SMD0805_HandSoldering
R5: 1M; Resistor_SMD0805_HandSoldering
R6: 10K; Resistor_SMD0805_HandSoldering
R7: 15K; Resistor_SMD0805_HandSoldering
R8: 4.7K; Resistor_SMD0805_HandSoldering
U1: ATTINY4313-S; SO20L
U2: MAX952ESA; SO8N
U3: TPS77033; SOT23-5

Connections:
/Bootloader: P2.7, U1.16
/CTS: P2.4, U1.4
/On/Sleep: P2.8, U1.13
/RTS: P2.6, U1.5
/Reset: C1.1, P1.5, P2.9, R6.1, U1.1
/Rx: P2.3, U1.2
/Sleep-Rq: P2.2, U1.15
/Tx: P2.5, U1.3
/VBatt: P2.12, P4.1, R7.1, U3.1
/Xbee-Reset: P2.10, U1.14
GND: C1.2, C2.2, C3.2, C4.2, P1.1, P2.11, P4.2, Q2.1, R8.2, U1.10, U2.4, U3.2, U3.3
unnamed: P1.2, U1.17
unnamed: P1.3, U1.18
unnamed: P1.4, U1.19
unnamed: Q1.1, Q2.2
unnamed: Q1.3, Q2.3, R2.2, R5.1, U2.5
unnamed: R5.2, U1.6, U2.7
VDD: P1.6, P2.1, R1.1, R2.1, R6.2, U1.20, U2.8, U3.5

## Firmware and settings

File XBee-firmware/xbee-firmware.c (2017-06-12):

/**
@mainpage AVR XBee Node Firmware
@version 2.1
@author Ken Sarkies (www.jiggerjuice.info)
@date 18 March 2016
@date 29 March 2016

@brief Code for an AVR with an XBee in a Remote Low Power Node

This is version two of the firmware. The rewrite is intended to expose the
logic flow more clearly and attempt to avoid subtle errors.

This code forms the interface between an XBee networking device using ZigBee
stack, and a counter signal providing count and battery voltage
measurements for communication to a base controller.

The code is written to make use of sleep modes and other techniques to
minimize power consumption. The AVR is woken by a count signal, updates the
running total, and sleeps.

The watchdog timer is used to wake the AVR at intervals to transmit the count
and battery voltage to the XBee. The XBee is then woken again after a short
interval to pass on any base station messages to the AVR.

An error correction protocol is used to ensure that count data is delivered
correctly to the base station before new counts are started. Refer to the
detailed documentation for more information.

@note
CTS must be set in the XBee and USE_HARDWARE_FLOW also enabled.
@note
Fuses: Disable the "WDT Always On" fuse and disable the BOD fuse.
@note
Software: AVR-GCC 4.8.2
@note
Target:   AVR with sufficient output ports and a USART (USI not supported)
@note
Tested:   ATTiny4313 with 1MHz internal clock. ATTiny841 with 8MHz clock.
          ATMega48 series with 8MHz clock,

*/
/****************************************************************************
 *   Copyright (C) 2014 by Ken Sarkies (www.jiggerjuice.info)               *
 *                                                                          *
 *   This file is part of XBee-Acquisition                                  *
 *                                                                          *
 * Licensed under the Apache License, Version 2.0 (the "License");          *
 * you may not use this file except in compliance with the License.         *
 * You may obtain a copy of the License at                                  *
 *                                                                          *
 *     http://www.apache.org/licenses/LICENSE-2.0                           *
 *                                                                          *
 * Unless required by applicable law or agreed to in writing, software      *
 * distributed under the License is distributed on an "AS IS" BASIS,        *
 * WITHOUT WARRANTIES OR CONDITIONS OF ANY KIND, either express or implied. *
 * See the License for the specific language governing permissions and      *
 * limitations under the License.                                           *
 ***************************************************************************/

#include <string.h>
#include <avr/sfr_defs.h>
#include <avr/wdt.h>
#include <avr/sleep.h>

#include "../libs/defines.h"
#include "../libs/serial.h"
#include "../libs/xbee.h"
#include <util/delay.h>
#include "xbee-firmware.h"

/****************************************************************************/
/* Global variables */
uint8_t coordinatorAddress64[8];
uint8_t coordinatorAddress16[2];
uint8_t rxOptions;

static uint32_t counter;            /* Event Counter */
static uint16_t wdtCounter;         /* Data Transmission Timer */
static bool transmitMessage;        /* Permission to send a message */
static bool stayAwake;              /* Keep XBee awake until further notice */
static uint16_t wakeInterval;       /* number of ticks between wakeups */
static uint8_t wdtTick;             /* timer tick setting (see manual) */

/****************************************************************************/
/* Local Prototypes */

static packet_error interpretMessage(uint16_t timeoutDelay, bool wait, rxFrameType* inMessage);
static void interpretCommand(rxFrameType* inMessage);
static packet_error getIncomingMessage(uint16_t timeoutDelay, bool wait, rxFrameType* inMessage);
static void hardwareInit(void);
static void wdtInit(const uint8_t waketime, bool wdeSet);
static void sendDataCommand(const uint8_t command, const uint8_t parameter, const uint32_t datum);
static void sendMessage(const char* data);
static void resetXBee(void);
static void sleepXBee(void);
static void wakeXBee(void);
static void powerDown(void);
static void powerUp(void);
static uint16_t stringToHex(const uint8_t length, const uint8_t* string);
static void hexToString(const uint32_t value, char* string, const uint8_t length);

/****************************************************************************/
/** @brief      Main Program

An interrupt service routine records a transition on the counter input. This
wakes the AVR which is sent back to sleep when the counts have settled.

The watchdog timer interrupt service routine provides a time tick of 8 seconds
(maximum). This wakes the AVR which counts off a number of ticks to extend the
sleep interval. Then the data transmission process begins within a loop.
The XBee should return a delivery status frame and the base system should
return a data frame indicating successful delivery or error.

An inner loop checks the XBee for serial data and selects out the base station
transmission and the delivery (Tx Status) frame.
- If a valid frame is received and it is a base station response, packetReady
  is set to signal the next stage of the protocol.
- If an invalid frame is received but is verified as a data frame, packetError
  is set.
- If a valid frame is received and it is a Tx Status is received the txDelivered
  is set from the delivery status field and txReceived is set.
- If the frame is invalid but is verified as a Tx Status, the process continues
  as if it were valid and delivered. the protocol is left to sort out the mess.
- If a timeout occurs and a Tx Status frame was not delivered, again continues
  as if it were valid and delivered.
- If a second timeout occurs after this, timeout is set.

Each of these sets of booleans are evaluated. In the event of errors, the
original message is repeated up to 3 times. Then the communication is abandoned.
- If txDelivered and packetReady, then we have a valid response. If it has the
  N command then the base station got an error. Repeat with N response.
- If it has the A command then all is well. Clear the count and sleep.
- If not packetReady and packetError was set, repeat with E response.
- If not txDelivered but txReceived then it is known certainly that a non
  delivery occurred, and the message is repeated. To avoid duplicates this is
  the only time that the original message is repeated.
- If timeout was set then nothing came back from the XBee or base station and
  the original message is repeated with T response.
- Finally packetReady is checked again regardless of any Tx Status frames, as
  an autonomous message may have come from the base station. This is interpreted
  according to a list of predetemined base station commands.

At the end, if the base station had responded positively and the protocol ended
successfully, a Y response is sent back without any further checks. If all
retries have passed without a positive response, an X response is returned.
*/

int main(void)
{

/* Initialise process counter */
    counter = 0;
    wakeInterval = ACTION_COUNT;
    wdtTick = WDT_TIME;

/* Initialise hardware. */
/* This has a GOTO label to allow internal soft reset without losing count. */
RES:hardwareInit();
/** Initialize the UART library, pass the baudrate and avr cpu clock 
(uses the macro UART_BAUD_SELECT()). Set the baudrate to a predefined value. */
    uartInit();
    wdtInit(wdtTick, true);            /* Set up watchdog timer */

/* Set the coordinator addresses. All zero 64 bit address with "unknown" 16 bit
address avoids knowing the actual address, but may cause an address discovery
event. */
    for  (uint8_t i=0; i < 8; i++) coordinatorAddress64[i] = 0x00;
    coordinatorAddress16[0] = 0xFE;
    coordinatorAddress16[1] = 0xFF;

    resetXBee();
    wakeXBee();
/* Idle and blink the test pin for 12 seconds to give XBee time to associate. */
    uint8_t i = 0;
    for (i=0; i<60; i++)
    {
#ifdef TEST_PORT_DIR
        sbi(TEST_PORT,TEST_PIN);
#endif
        _delay_ms(100);
#ifdef TEST_PORT_DIR
        cbi(TEST_PORT,TEST_PIN);
#endif
        _delay_ms(100);
    }
/* Blink debug port to indicated ready */
#ifdef DEBUG_PORT_DIR
    sbi(DEBUG_PORT,DEBUG_PIN);          /* Blink debug LED */
    _delay_ms(100);
    cbi(DEBUG_PORT,DEBUG_PIN);
    _delay_ms(100);
    sbi(DEBUG_PORT,DEBUG_PIN); 
    _delay_ms(100);
    cbi(DEBUG_PORT,DEBUG_PIN);
#endif

/*---------------------------------------------------------------------------*/
/* Main loop forever. */


/* Initialise watchdog timer count */
    wdtCounter = 0;
    stayAwake = XBEE_STAY_AWAKE;
    transmitMessage = false;

/* Turn off until some counts start to arrive */
    if (!stayAwake) sleepXBee();

    for(;;)
    {
/* The WDIE bit must be set each time an interrupt occurs in case the WDT
reset-after-interrupt was enabled. This will prevent a reset from occurring
unless the MCU has lost its way. */
        sbi(WDTCSR,WDIE);
        sei();
/* On waking, note the count, wait a bit, and check if it has advanced. If
not, return to sleep. Otherwise keep awake until the counts have settled.
This will avoid rapid wake/sleep cycles when counts are changing. */
        uint32_t lastCount;
        uint8_t sleepDelay = 0;
        do
        {
            lastCount = counter;    /* Counter is global, changed in the ISR. */
            if (sleepDelay > 10) sleepDelay = 0;

/* Check for and deal with any extra messages that have arrived while the node
was awake or between transmissions. */
            if (! transmitMessage)
            {
                rxFrameType inMessage;              /* Received data frame */
                interpretMessage(2000, false, &inMessage);
            }
/* Any interrupt will wake the AVR. If it is a WDT timer overflow event,
8 seconds will be too short to do anything useful, so go back to sleep again
until enough such events have occurred. The WDT ISR will set transmitMessage
when the conditions are satisfied. */
            else
            {
                transmitMessage = false;
#ifdef TEST_PORT_DIR
                sbi(TEST_PORT,TEST_PIN);            /* Set test pin on */
#endif
                wdtCounter = 0;     /* Reset the WDT counter for next time */
/* Now ready to initiate a data transmission. */
/* Power up only essential peripherals for transmission of results. */
                powerUp();
                wakeXBee();

/* A cycle passes through a number of stages depending on error conditions
until the transmission has been completed or abandoned. */
                uint8_t retryCount = 0;
                bool retryEnable = true;            /* Allows a retry to occur */
                bool associated = false;
                bool batteryCheckOK = false;        /* Got back valid response to IS command */
                bool ack = false;                   /* received ACK from coordinator */
                bool nak = false;                   /* received NAK from coordinator */
                bool delivery = false;              /* Signalled as not delivered */
                uint16_t timeoutDelay = 0;
                uint32_t batteryVoltage = 0;
                bool cycleComplete = false;
                rxFrameType inMessage;              /* Received data frame */
                txStage stage = associationCheck;
                packet_error packetError = unknown_error;
                while (! cycleComplete)
                {
/* Wait if not associated. After forty tries (12 seconds), sleep for a while. */
                    if (stage == associationCheck)
                    {
                        if (associated || (retryCount > 40))
                        {
                            retryCount = 0;
                            stage = batteryCheck;
                        }
                        else
                        {
                            timeoutDelay = 300;
                            if (retryEnable)
                            {
                                sendATFrame(2,"AI");
                                retryCount++;
                            }
                        }
                        retryEnable = true;
                    }
/* Read the battery voltage from the XBee. If not successful, just give up and go on. */
                    if (stage == batteryCheck)
                    {
                        if (batteryCheckOK || (retryCount > 3))
                        {
                            #ifdef VBATCON_PIN
/* Turn off battery measurement */
                            cbi(VBATCON_PORT,VBATCON_PIN);
                            #endif
                            retryCount = 0;
                            packetError = no_error;
                            nak = false;
                            ack = false;
                            stage = transmit;
                        }
                        else
                        {
                            timeoutDelay = 200;
                            if (retryEnable)
                            {
                                #ifdef VBATCON_PIN
/* Turn on battery measurement */
                                sbi(VBATCON_PORT_DIR,VBATCON_PIN);
                                #endif
                                sendATFrame(2,"IS");    /* Force Sample Read */
                                retryCount++;
                            }
                        }
                        retryEnable = true;
                    }
/* Transmit the message. An ACK from the coordinator is required. */
                    if (stage == transmit)
                    {
/* An ACK means that we can now complete the cycle gracefully. */
                        if (ack)
                        {
                            sendMessage("A");
/* Subtract the transmitted count from the current counter value. */
                            counter -= lastCount;
                            lastCount = 0;
                            retryCount = 0;
                            cycleComplete = true;
                        }
/* Too many retries means that we should now complete the cycle ungracefully. */
                        else if (retryCount > 3)
                        {
                            sendMessage("X");
                            _delay_ms(100);     /* Give time for message to go */
                            goto RES;           /* Soft reset the Node */
                        }
/* Otherwise decide how to respond with a retransmission. */
                        else
                        {
                            timeoutDelay = 2000;
                            if (retryEnable)
                            {
                                uint32_t parameter = retryCount;
                                uint8_t txCommand = 'C';
                                if (packetError == timeout) txCommand = 'T';
/* Last read of XBee gave an error */
                                else if (packetError != no_error)
                                {
                                    parameter = packetError;
                                    txCommand = 'E';
                                }
                                if (nak) txCommand = 'N';
/* Last attempt was a failed delivery */
                                if (delivery > 0)
                                {
                                    parameter = delivery;
                                    txCommand = 'S';
                                }
/* Data word has count 16 bits, voltage 10 bits, status 6 bits */
                                sendDataCommand(txCommand, 0,
                                    lastCount+((batteryVoltage & 0x3FF)<<16)+
                                    ((parameter & 0x3F)<<26));
                                retryCount++;
                            }
                            retryEnable = true;
                            nak = false;
                        }
                    }

/* Wait for incoming messages. */
                    packetError = interpretMessage(timeoutDelay, true, &inMessage);
                    if (packetError == no_error)
                    {
/* Interpret messages and gather information returned */
                        switch (inMessage.frameType)
                        {
/* These are messages coming back from an XBee AT command. */
                        case AT_COMMAND_RESPONSE:
                            if (inMessage.message.atResponse.status != 0)
                                packetError = frame_error;
                            else
                            {
/* Association Indication */
                                if ((inMessage.message.atResponse.atCommand1 == 'A') && \
                                    (inMessage.message.atResponse.atCommand2 == 'I'))
                                {
                                    if (stage != associationCheck) retryEnable = false;
                                    associated = (inMessage.message.atResponse.data[0] == 0);
                                }
/* Battery Voltage Measurement */
                                if ((inMessage.message.atResponse.atCommand1 == 'I') && \
                                    (inMessage.message.atResponse.atCommand2 == 'S'))
                                {
                                    if (stage != batteryCheck) retryEnable = false;
                                    batteryCheckOK = true;
                                    if (inMessage.length > 5)
                                        batteryVoltage = 
                                            getXBeeADC(inMessage.message.atResponse.data,1);
                                }
                            }
                            break;
/* Status of previous transmission attempt. */
                        case TX_STATUS:
                            delivery = inMessage.message.txStatus.deliveryStatus;
                            retryEnable = false;
                            break;
/* Receive Packet. This can be of a variety of types. */
                        case RX_PACKET:
                            {
                                uint8_t rxCommand = inMessage.message.rxPacket.data[0];
                                if (stage == transmit)
                                {
/* Check if the first character in the data field is an ACK or NAK.
These messages are ONLY valid in the transmit stage and could confuse the
protocol in other stages. */
/* Base station picked up an error in the previous response and sent a NAK. */
                                    if (rxCommand == 'N') nak = true;
/* Got an ACK: aaaah that feels good. */
                                    else if (rxCommand == 'A') ack = true;
/* Otherwise report an error in the command field. */
                                    else packetError = command_error;
                                }
                                else  retryEnable = false;
                            }
                            break;
                        }
                    }
                }
/* Cycle Complete */
            }
/* Delay here to prevent sleep mode from occurring until counts have settled.
Count period is typically less than 10ms. */
            _delay_ms(1);
        }
        while ((sleepDelay++ < 10) || (counter != lastCount));

        #ifdef TEST_PORT_DIR
        cbi(TEST_PORT,TEST_PIN);    /* Set test pin off */
        #endif
/* Power down the AVR to deep sleep until an interrupt occurs */
        sei();
        if (! stayAwake)
        {
            sleepXBee();
            powerDown();            /* Turn off all peripherals for sleep */
#ifdef VBATCON_PIN
            cbi(VBATCON_PORT,VBATCON_PIN);   /* Turn off battery measurement */
#endif
            set_sleep_mode(SLEEP_MODE_PWR_DOWN);
            sleep_mode();
        }

    }
}

/****************************************************************************/
/** @brief Interpret a Received Message.

Checks for a message received and interprets it to deal with certain cases
needing action independently of the transmit cycle, or ignoring.

@param[in] rxFrameType* inMessage: The received frame with the message.
@returns packet_error packetError: Error code.
*/

packet_error interpretMessage(uint16_t timeoutDelay, bool wait, rxFrameType* inMessage)
{
    packet_error packetError = getIncomingMessage(timeoutDelay, wait, inMessage);
    if (packetError == no_error)
    {
        switch (inMessage->frameType)
        {
/* Irrelevant message types that can be ignored. */
        case MODEM_STATUS:
            packetError = modem_status;
            break;
        case NODE_IDENT:
            packetError = node_ident;
            break;
        case IO_DATA_SAMPLE:
            packetError = io_data_sample;
            break;
/* Receive Packet. This can be of a variety of types.
We deal only with the commands to the node. */
        case RX_PACKET:
            {
/* Got a special command plus possible parameters from the coordinator for
action. */
                uint8_t rxCommand = inMessage->message.rxPacket.data[0];
                if (rxCommand == 'D')
                {
                    interpretCommand(inMessage);
                    packetError = no_error;
                }
            }
        }
    }
    return packetError;
}

/****************************************************************************/
/** @brief Interpret a Command Message from the Base Station.

Deal with commands, parameters and data intended for the attached processor
system. Anything not recognised is ignored.
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

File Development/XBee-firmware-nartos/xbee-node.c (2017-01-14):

/**
@mainpage AVR XBee Node Firmware using NARTOS
@version 0.0
@author Ken Sarkies (www.jiggerjuice.info)
@date 11 December 2014

@brief Code for an AVR with an XBee in a Remote Low Power Node

This code forms the interface between an XBee networking device using ZigBee
stack, and a counter signal providing count and battery voltage
measurements for communication to a base controller.

The code is written to make use of sleep modes and other techniques to
minimize power consumption. The AVR is woken by a count signal, updates the
running total, and sleeps.

The watchdog timer is used to wake the AVR at intervals to transmit the count
and battery voltage to the XBee. The XBee is then woken again after a short
interval to pass on any base station messages to the AVR.

@note
Fuses: Disable the "WDT Always On" fuse and disable the BOD fuse.
@note
Software: AVR-GCC 4.8.2
@note
Target:   AVR with sufficient output ports and a USART (USI not supported)
@note
Tested:   ATTiny4313 at 1MHz internal clock.

*/
/****************************************************************************
 *   Copyright (C) 2014 by Ken Sarkies (www.jiggerjuice.info)               *
 *                                                                          *
 *   This file is part of XBee-Acquisition                                  *
 *                                                                          *
 * Licensed under the Apache License, Version 2.0 (the "License");          *
 * you may not use this file except in compliance with the License.         *
 * You may obtain a copy of the License at                                  *
 *                                                                          *
 *     http://www.apache.org/licenses/LICENSE-2.0                           *
 *                                                                          *
 * Unless required by applicable law or agreed to in writing, software      *
 * distributed under the License is distributed on an "AS IS" BASIS,        *
 * WITHOUT WARRANTIES OR CONDITIONS OF ANY KIND, either express or implied. *
 * See the License for the specific language governing permissions and      *
 * limitations under the License.                                           *
 ***************************************************************************/

#include <inttypes.h>
#include <string.h>
#include <stdbool.h>
#include <avr/sfr_defs.h>
#include <avr/io.h>
#include <avr/wdt.h>
#include <avr/interrupt.h>
#include <avr/sleep.h>

#include "../../libs/defines.h"
#include "../../libs/serial.h"
#include "../../../NARTOS/nartos.h"
#include <util/delay.h>
#include "xbee-node.h"

#define TRUE 1
#define FALSE 0
/* Convenience macros (we don't use them all) */
#define  _BV(bit) (1 << (bit))
#define  inb(sfr) _SFR_BYTE(sfr)
#define  inw(sfr) _SFR_WORD(sfr)
#define  outb(sfr, val) (_SFR_BYTE(sfr) = (val))
#define  outw(sfr, val) (_SFR_WORD(sfr) = (val))
#define  cbi(sfr, bit) (_SFR_BYTE(sfr) &= ~_BV(bit))
#define  sbi(sfr, bit) (_SFR_BYTE(sfr) |= _BV(bit))
#define  high(x) ((uint8_t) (x >> 8) & 0xFF)
#define  low(x) ((uint8_t) (x & 0xFF))

/* Global variables */
volatile uint8_t coordinatorAddress64[8];
volatile uint8_t coordinatorAddress16[2];
volatile uint8_t rxOptions;

volatile uint32_t counter;           /* External event counter */
volatile uint32_t lastCount;
volatile uint8_t wdtCounter;         /* Timer counter to extend sleep times */

volatile bool txStatusReceived;      /* The Tx Status message has been received */
volatile bool txOK;                  /* Tx Status message received correctly. */

volatile uint8_t retry;              /* Counter for retrying messages */
volatile bool stayAwake;             /* Keep awake in response to command */
volatile baseResponse_t baseResponse;/* Response from the base station received */
volatile bool txFinished;            /* Finish data part of transmission */
volatile uint8_t txCommand;          /* Command to send with data */
volatile uint8_t rxCommand;          /* Command received */
volatile bool rxTerminate;           /* Signal to the receive task to terminate */
volatile rxFrameType inMessage;      /* Data message received */

volatile uint8_t sendBuffer[12];     /* Transmission buffer */
volatile bool timeStatusResponse;    /* Timing of Tx Status response */
volatile uint8_t txStatusRetry;      /* Count of bad Tx status retries. */

volatile bool timeBaseResponse;      /* Timing of base station response */
volatile uint8_t messageState;       /* Progress of frame being received */
volatile rxFrameType rxMessage;      /* Buffered received message */
volatile messageError_t messageError;/* Error code for message received */

/* Task IDs */
uint8_t mainTaskID;
uint8_t receiveTaskID;

/*---------------------------------------------------------------------------*/
/** @brief Main program.

Initialise hardware and global variables, and start scheduler with tasks. */

int main(void)
{

/*  Initialise hardware */
    hardwareInit();
    wdtInit(WDT_TIME);
/** Initialize the UART library, pass the baudrate and avr cpu clock 
(uses the macro UART_BAUD_SELECT()). Set the baudrate to a predefined value. */
    uartInit();

/* Set the coordinator addresses. All zero 64 bit address with "unknown" 16 bit
address avoids knowing the actual address, but may cause an address discovery
event. */
    for  (uint8_t i=0; i < 8; i++) coordinatorAddress64[i] = 0x00;
    coordinatorAddress16[0] = 0xFE;
    coordinatorAddress16[1] = 0xFF;

/* Initialise process counter */
    counter = 0;

/* Initialise watchdog timer count */
    wdtCounter = 0;

/* Allow XBee to sleep */
    stayAwake = false;

/* Enable Interrupts */
    sei();

/** Initialise the OS stuff, setup the receive task as a first task, and jump
to the OS. */
  initNartos();
  mainTaskID = taskStart((uint16_t)*mainTask,FALSE);
  nartos();
}

/*---------------------------------------------------------------------------*/
/** @brief Main task

Set AVR and XBee to sleep. Wakes when a timer interrupt or a count interrupt
occurs.

Coordinate the data collection, transmission, reception and command
interpretation. */

void mainTask(void)
{
/* Main loop forever. */
    for(;;)
    {
        if (! stayAwake) sleepXBee();
/* Power down the AVR to deep sleep until an interrupt occurs */
        set_sleep_mode(SLEEP_MODE_PWR_DOWN);
        sleep_enable();
        sleep_cpu();

/* On waking, note the count. After processing other work, wait a bit and check
if it has advanced. If not, return to sleep. Otherwise keep awake until the
counts have settled. This will avoid rapid wake/sleep cycles when counts are
changing. The counter is a global variable and is changed in the ISR. */
        do
        {
            lastCount = counter;
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

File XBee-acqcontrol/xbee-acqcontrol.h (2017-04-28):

/*
Title:    XBee Acquisition Control process
*/

/****************************************************************************
 *   Copyright (C) 2013 by Ken Sarkies ksarkies@internode.on.net            *
 *                                                                          *
 *   This file is part of XBee-Acquisition                                  *
 *                                                                          *
 * Licensed under the Apache License, Version 2.0 (the "License");          *
 * you may not use this file except in compliance with the License.         *
 * You may obtain a copy of the License at                                  *
 *                                                                          *
 *     http://www.apache.org/licenses/LICENSE-2.0                           *
 *                                                                          *
 * Unless required by applicable law or agreed to in writing, software      *
 * distributed under the License is distributed on an "AS IS" BASIS,        *
 * WITHOUT WARRANTIES OR CONDITIONS OF ANY KIND, either express or implied. *
 * See the License for the specific language governing permissions and      *
 * limitations under the License.                                           *
 ***************************************************************************/

#ifndef XBEE_ACQCONTROL_H
#define XBEE_ACQCONTROL_H

#define VERSION "1.2"

#define DEBUG   1

// Limit definitions
#define MAXNODES                25
#define SIZE                   256
#define DATA_BUFFER_SIZE        64
#define FLUSH_LIMIT              4
#define FILE_LIMIT            1024

// Length of data field in a data message
#define DATA_LENGTH             10

#define DATA_PATH           "/data/XBee/"
#define LOG_FILE            DATA_PATH"/libxbee.log"

#define SERIAL_PORT         "/dev/ttyUSB0"
#define BAUDRATE            38400

#define PORT "58532"        // port for the external command I/F
#define MAX_CLIENTS 2       // Number of external connections allowed

#include "xbee.h"
#include <stdint.h>

/* Serial Port Parameters */

enum DataBitsType
{
    DATA_5 = 5,
    DATA_6 = 6,
    DATA_7 = 7,
    DATA_8 = 8
};

enum ParityType
{
    PAR_NONE,
    PAR_ODD,
    PAR_EVEN,
    PAR_SPACE
};

enum StopBitsType
{
    STOP_1,
    STOP_2
};

enum FlowType
{
    FLOW_OFF,
    FLOW_HARDWARE,
    FLOW_XONXOFF
};

/* Structure for a node table entry.
The node table holds all useful information about the nodes in the XBee
network. */
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

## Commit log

2014-07-07 Initial commit of project. Work needs to be done to fix build dependency problems
    [xbee-node.sch]
2014-07-07 Correct a few bugs preventing build. Update Readme files. Remove redundant directory.
    [local-dialog.cpp]
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2014-07-20 New schematic for the node, keeping old one under a different name Minor updates to firmware docs and change INT1 to INT0
    [xbee-node-atmega48.sch, xbee-node-attiny4313.sch]
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2014-07-27 More work on Kicad PCB. Remove LED (which will be on a separate board) and replace with connector. Add most footprints. Photodiode will need a custom footprint to be added later.
    [xbee-node-attiny4313.sch]
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2014-08-06 Update to firmware to make XBee wake and successfully communicate to coorsinator. More work on PCB to complette layout and add tracks.
    [xbee-node-attiny4313.kicad_pcb, xbee-node-attiny4313.sch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]
2014-08-06 Change to the ATTiny841 as the ATTiny4313 is 2.5mm high, and will interfere with the slotted disk. Completed layout but ground planes and power track widths still to be fixed.
    [xbee-node-attiny4313-first.kicad_pcb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]
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2014-08-09 Modify PCB to interchange pins on AVR. The ATTiny841 has INT0 on pin 5 rather than pin 3 of the ATTiny84
    [xbee-node-attiny841.kicad_pcb, xbee-node-attiny841.sch]
2014-08-19 Complete PCB adding additional pads for battery holders, removing edge connector and adding extra connectors to make a linear 12 pin XBee adapter.
    [xbee-node-attiny841-B_Cu.gbr, xbee-node-attiny841-B_Mask.gbr, xbee-node-attiny841-B_SilkS.gbr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]
2014-08-24 Add directory for the XBee and LED mounting boards, and change name of the main board directory. Complete the mount boards.
    [Kicad-mounts-B_Cu.gbr, Kicad-mounts-B_Mask.gbr, Kicad-mounts-B_SilkS.gbr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]
2014-08-31 Modification of boards after checking. Addition of other LED types to LED mount board.
    [Kicad-mounts-B_Cu.dxf, Kicad-mounts-B_Mask.dxf, Kicad-mounts-B_SilkS.dxf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]
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2014-09-19 Bug in the example serial init function, worked for double rate settings (ATTiny4313) but not for those without (ATMega168).
    [xbee-node-attiny4313-first.kicad_pcb, xbee-node-attiny4313.kicad_pcb, xbee-node-attiny4313.sch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]
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2014-09-21 GUI firmware upload: change failpoint codes and print out in the event of error. Do not open file if failure of erase occurs.
2014-09-22 Generalize and revert back to single directory in firmware, bootloader and example, with makefile to pass on microcontroller type.
    [bootloader.c, defines-M168.h, defines-T4313.h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]
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2014-09-24 Add a reset after removing bootloader pin signal to force application to start.
2014-09-24 Move define headers and serial libs to a use a common set. Add code for type 2 (AVRs without a bootloader section) to test bootloader pin and jump to the bootloader address. Change optimization level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
    [defines-M168.h, defines-T4313.h, xbee-node-example.c]
2014-09-24 Change goto back to function call to jump to 0x0000. Both probably work but any other address and goto seems to fail.
    [bootloader.c]
2014-09-24 Attempt to get example working for ATTiny4313. OK when first programmed. Corrected some old settings in the defines header. goto statement used wrong address. Go back to the function call. Still has 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
    [xbee-node-example.c]
2014-09-25 Remove useless function call in bootloader and fix some bugs. Bootloader call from app still needs to be fixed.
    [bootloader.c, xbee-node-example.c]
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2014-11-09 Correct some wiring and ground connection errors in the main board PCB. Reduce size of the LED mount to fit inside meter.
    [Kicad-mounts-B_Cu.gbr, Kicad-mounts-B_Mask.gbr, Kicad-mounts-B_SilkS.gbr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]
2014-11-15 Swap over Tx and Rx
    [Kicad-mounts.kicad_pcb, Kicad-mounts.sch]
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2014-11-26 Start of new mounts board with corrected XBee footprint. XBee reversed and lowered to make the mount board shorter.
    [Kicad-mounts.kicad_pcb]
2014-11-26 Firmware now counts in the ISRs. Remains awake to receive a return message. Remains awake as long as counts are changing to avoid rapid sleep/wake cycles.
    [xbee-node.c]
2014-11-27 Rebuilt XBee mount board and generated gerbers for both boards. Remove pngs for now.
    [Kicad-mounts-B_Cu.gbr, Kicad-mounts-B_Mask.gbr, Kicad-mounts-B_SilkS.gbr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]
2014-11-28 For remote firmware, add in data transmission protocol and error checking.
    [xbee-node.c]
2014-11-29 Correction of some bugs in firmware to eliminate all but data packets. Update of some documentation in readme and serial.c
    [xbee-node.c]
2014-11-29 Firmware remove debugs, fix bug with checksum error to allow repeats.
    [xbee-node.c]
2014-11-29 Control process: add a check for the watermeter data and error packets, and respond with an acknowledgement plus checksum. Print all packets to the log file, not just debug packets. Update some docum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
2014-12-12 Firmware: attempt to deal with more error conditions. However the complexity is too great and focus will move to a NARTOS implementation
    [xbee-node.c]
2014-12-12 Firmware-nartos: further corrections. Code not working.
    [xbee-node.c]
2014-12-13 Firmware. Corrections to logic. Now works basically with protocol. Also corrected access to XBee frame structures.
    [xbee-node.c]
2014-12-14 Update main board to filter analogue power runs and shield input signals.
    [xbee-node-attiny841-B_Cu.gbr, xbee-node-attiny841-B_Mask.gbr, xbee-node-attiny841-B_SilkS.gbr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]
2014-12-14 Minor change to board schematic to put capacitor on correct power line.
    [xbee-node-attiny841.kicad_pcb, xbee-node-attiny841.sch]
2014-12-14 Firmware increase debounce to 100us to wipe out transmitter interference (measured at 50us). This relies on the interference to remain short.
    [xbee-node.c]
2014-12-18 GUI: change the local-dialog to a non-modal widget xbee-control to ensure it will not interfere with the other windows. Change the main window to a widget also. Disable the row select checkbox and se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
    [xbee-control.h, xbee-dialog.cpp]
2014-12-18 GUI mods to fix operation of multiple xbee-control windows and fix segfault for local coordinator window.
    [xbee-dialog.cpp]
2014-12-20 Main board: add a regulator for the XBee power only, plus capacitor.
    [xbee-node-attiny841-B_Cu.gbr, xbee-node-attiny841-B_Mask.gbr, xbee-node-attiny841-B_SilkS.gbr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]
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2014-12-24 Change PCBs to move XBee regulator and caps to the mount board. Change Vcc on mount board to take full battery voltage.
    [Kicad-mounts-B_Cu.gbr, Kicad-mounts-B_Mask.gbr, Kicad-mounts-B_SilkS.gbr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]
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2016-02-18 Setup of KiCad projects to point to local libraries in repository. Corrections to mounts schematic.
    [Kicad-mounts.sch]
2016-02-19 Fix minor problems with files to reference provided local libraries. Updates to some documents
    [xbee-node-attiny841.sch]
2016-02-20 Modified both Main and Mounts PCBs to have all footprints in the local library Photodiode.pretty. Saved footprints already in the PCB hopefully avoiding invalidating the PCB in future. Minor changes 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
    [Kicad-mounts.sch, xbee-node-attiny841.sch]
2016-02-22 Move some components away from centre to leave room for a shaft housing.
    [xbee-node-attiny841.kicad_pcb]
2016-02-23 Change orientation of debug connector on main board to fit in housing. Update mounts to narrow down the LED mount
    [Kicad-mounts.kicad_pcb, xbee-node-attiny841.kicad_pcb]
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2016-02-25 Change mount board to rotate XBee sideways and keep dual row connector only
    [Kicad-mounts.kicad_pcb, Kicad-mounts.sch, xbee-node-attiny841.kicad_pcb]
2016-02-25 Shift XBee connector on main board by 1mm to avoid housing structures. Update documentation.
    [xbee-node-attiny841.kicad_pcb]
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2016-03-01 Create version 4 of the XBee mount board and modify the main board to allow the XBee base to sit on the main board.
    [Kicad-mounts.kicad_pcb, xbee-node-attiny841.kicad_pcb]
2016-03-02 GUI Update to QT5. Revert xbee-dialogue to fix problems introduced with an earlier commit 24 Dec 2014 that wasn't completed.
    [xbee-control.h, xbee-dialog.cpp]
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2016-03-09 Update to test card schematic to add LEDs and change power regulator.
    [xbee-node-atmega48.sch]
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2016-03-24 Change attiny4313 node to shift analogue input to AD0 on XBee away from commissioning button. Complete serial test board. Update documentation
    [xbee-node-attiny4313.sch, xbee-node-serial.sch]
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2016-03-27 Change atmega48 node to shift analogue input to AD2 on XBee away from commissioning button.
    [xbee-node-atmega48.sch]
2016-03-29 XBee-acqcontrol: Correct a debug print statement to be within the debug conditional.
2016-03-29 XBee-node-test: correct PC interrupt initialization settings
2016-03-29 XBee-acqcontrol: Correct a print statement for serial port not available.
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2016-04-05 xbee-node-test: Add resistor divider to MAX232 out to drop receiving signal to 3.3V
    [xbee-node-serial.sch]
2016-04-06 Test board: Move some defines in libs to distinguish different processor configurations. Add LEDs to ATTiny4313 and ATMega48 test board schematics. Update readme.
    [xbee-node-atmega48.sch, xbee-node-attiny4313.sch]
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2016-04-09 Major new version of the PCBs for next stage of production run.
    [Kicad-mounts.kicad_pcb, Kicad-mounts.sch, xbee-node-attiny841.kicad_pcb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]
2016-04-11 Main PCB. Changes to debug connector to bring out XBee association and commissioning signals. Change photodiode to BPW34. Minor change to battery mount to increase drill hole and move holes to spec. 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
    [xbee-node-attiny841.kicad_pcb, xbee-node-attiny841.sch]
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2016-04-14 Minor corrections to PCBs and generation of gerbers
    [Kicad-mounts-B.Cu.gbr, Kicad-mounts-B.Mask.gbr, Kicad-mounts-B.SilkS.gbr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]
2016-04-14 xbee-node: fix problems with WDT interrupt and initialisation. Set working for ATMega48
    [xbee-node.c]
2016-04-16 XBee-node: Fix problem of WDT interrupt for ATMega48
    [xbee-node.c]
2016-04-18 XBee-node-firmware-test: Update to correct failure to send and receive packets. The presence of a while loop caused the transmission to not occur, although with the while loop commented out, it worke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
    [mainprog-firmware.cpp]
2016-04-18 Move receiveMessage function from main code to xbee.c and xbee.cpp. Fix up a problem with serial getch that returned crap. firmware sends and acknowledges OK but seems to get stuck still.
    [mainprog-firmware.cpp, xbee-node.c]
2016-04-19 XBee-node-test: More corrections to serial getch to handle QTs API Pull debug statements from mainprog Add more debug statements to acqcontrol. Minor documentation changes
    [mainprog-firmware.cpp]
2016-04-19 Major shuffle of development and test modules to a dedicated directory, to separate it from the operational modules.
    [xbee-node-atmega48.sch, xbee-node-attiny4313.sch, xbee-node-serial.sch]
2016-04-23 Major modifications to protocol to fix missing logic. Document flow of firmware protocol
    [mainprog-firmware.cpp, xbee-node.c]
2016-04-23 XBee-firmware: Corrections to logic. Tested with good reception and lost ACK only so far. XBee-node-test-pc: extensive debug statements provided.
    [mainprog-firmware.cpp, xbee-node.c]
2016-04-25 Firmware test: return of comprehensive debug to pc version of XBee-node-test Delay the return of an ACK in XBee-acqcontrol by 200ms to simulate network problem.
    [mainprog-firmware.cpp]
2016-04-25 Further correction to XBee-acqcontrol. The data length of the count data message is 10, but it cannot be derived from the message length reported by xbeelib3 since the acknowledge message arrives aft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
    [xbee-acqcontrol.h]
2016-04-26 Update to PCB to change debug header to shrouded, and widen cutout for BPW34 photodiode to allow it to be mounted within the PCB thickness.
    [xbee-node-attiny841.kicad_pcb]
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2016-05-06 Update to network flow diagram to add protocol response to errored status from the base station. Some additional clarification in the firmware.
    [mainprog-firmware.cpp, xbee-node.c]
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2016-05-19 Update to Kicad PCB files to slightly adjust components and footprints to accomodate purchased materials.
    [Kicad-mounts.kicad_pcb, xbee-node-attiny841.kicad_pcb]
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2016-06-16 Addition of PCB layout to testboard with footprints taken mainly from Kicad GitHub repository. Not yet routed
    [Kicad-TestBoard.kicad_pcb, Kicad-TestBoard.sch]
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2016-06-17 Completion of test board. The 0.1" 12-pin debug connector removed as unnecessary and too complicating for the layout. PB switches adapted to smaller more common version available locally.
    [Kicad-TestBoard-B.Cu.dxf, Kicad-TestBoard-B.SilkS.dxf, Kicad-TestBoard-Edge.Cuts.dxf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]
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2016-09-03 Testboard. Correct some footprint errors and change drill sizes to regular metric.
    [Kicad-TestBoard.kicad_pcb, Kicad-TestBoard.sch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]
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2016-12-05 Minor corrections to testboard schematic
    [Kicad-TestBoard.sch]
2016-12-05 Corrections to Testboard PCB. - Incorrect Tx wiring to MAX232 - Make correct allocations of footprints in schematic - Add some extra text including title, version, author, date.
    [Kicad-TestBoard-B.Cu.gbr, Kicad-TestBoard-B.Mask.gbr, Kicad-TestBoard-B.SilkS.gbr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]
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2016-12-08 Change makefiles to point to installed avr-gcc. Corrections to READMEs Small change to (abandoned) Xbee-firmware-nartos to account for a move to another directory (but it still doesn't compile).
    [xbee-node.c]
2016-12-21 Update to a number of documents. Fix to Kicad-Mounts due to an obsoleted diode. Also a change to some command-line parameters for acqcontrol to line up with documented values.
    [Kicad-mounts.sch]
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2017-01-07 Update to xbee-node-test to remove some global variable use in the receiver routines. This has a bug to be fixed. Add code to check for the XBee in association before moving on to the main loop. This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
2017-01-11 Modify xbee-node-test on ATMega48 to check for XBee associated before proceeding to any further processing. Added receiver buffering but this doesn't work at this time. Added a few library features i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
2017-01-13 XBee-node-test-pc: some mods to prevent program catching in an endless loop if a bad message was received.
    [mainprog-firmware.cpp]
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2017-01-15 Some corrections to the way sleep mode is entered in firmware, according to recommendations in avr-libs <sleep.h>
    [xbee-firmware.c, xbee-node-test-sleep.c]
2017-01-16 Fix error in acqcontrol to interpret I/O sample correctly
    [xbee-acqcontrol.h]
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2017-01-20 Change firmware to test for XBee association each time a transmission is to be made, to avoid losing contact with the Coordinator after a long outage.
    [xbee-firmware.c, xbee-node-test-sleep.c]
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2017-01-24 Xbee-node-test-sleep: Add reset-after-interrupt mode to WDT in case MCU gets lost.
    [xbee-node-test-sleep.c]
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2017-01-30 Kicad-Main, Kicad-Mounts and Kicad-Testboard. Add a range of symbol and footprint libraries and repair some problems apparently due to randomized changes in Kicad repository libraries.
    [Kicad-TestBoard-B.Cu.gbr, Kicad-TestBoard-B.Mask.gbr, Kicad-TestBoard-B.SilkS.gbr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]
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2017-02-01 Xbee-node-test-sleep. Fix bug with VBAT_CON. Add compile options to choose whether to sleep MCU, XBee and make battery measurement.
    [xbee-node-test-sleep.c]
2017-02-01 Xbee-firmware: changed VBAT_CON to fix bug and a few minor tweaks.
    [xbee-firmware.c]
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2017-02-04 Rework Xbee-node-test-pc to put in an option for C language emulator. Test programs changed to use printf rather than QT functions. QT emulator extended to activate combo boxes correctly.
    [mainprog-firmware.cpp]
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2017-02-04 XBee-acqcontrol: correct debug command line option and remove locally defined false/true.
    [xbee-acqcontrol.h]
2017-02-06 The Xbee-node-test-pc emulator is expanded to provide a c code emulator, avoiding the qt5 environment needed. This is useful for running on small devices such as the Raspberry Pi or BeagleBone that m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
    [mainprog-firmware.cpp]
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2017-02-06 Minor corrections to pc emulators to correct bugs.
    [mainprog-firmware.cpp]
2017-02-07 Correct error in XBee-node-test-pc emulator-c that didn't register a different serial port command line setting. More messages in mainprog-firmware. Update to README
    [mainprog-firmware.cpp]
2017-02-11 Resolve issue between old version of CAM350 (9.5) and latest gerber format 4.6 where circles were not rendered correctly.
    [xbee-node-attiny841-B.Cu.gbl, xbee-node-attiny841-B.Cu.gbr, xbee-node-attiny841-B.Mask.gbr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]
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2017-02-19 acqcontrol: Further debug prints and attempt to access modem and transmit status messages. XBee firmware: mods to correct bugs, particularly the search for association at the start which did the oppo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
    [xbee-acqcontrol.h, xbee-firmware.c]
2017-02-24 Modifications to XBee-node-test-pc firmware to reset XBee on failure and to add further debug printing.
    [mainprog-firmware.cpp]
2017-02-24 XBee-acqcontrol correct some bugs and add further debug print including interpretation of XBee messages.
2017-02-26 Correct some stupid errors in Testboard and XBee-node-test PCBs.
    [Kicad-TestBoard-B.Cu.gbr, Kicad-TestBoard-B.Mask.gbr, Kicad-TestBoard-B.SilkS.gbr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]
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2017-02-27 Firmware: code to set input pullups corrected.
    [xbee-firmware.c]
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2017-03-06 Kicad-mounts: correction to some gerbers.
    [Kicad-mounts-B.Adhes.gbr, Kicad-mounts-B.Cu.gbr, Kicad-mounts-B.Mask.gbr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]
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2017-03-09 XBee-node-test-pc wasn't receiving the replies from the coordinator because the RESPONSE_DELAY limit was set too small. Increase this in all files to ensure that reasonable time for the response is p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
    [mainprog-firmware.cpp]
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2017-03-17 Correct firmware bug and coordinate with emulated firmware. Expand error reporting in firmware. Make emulator code to restart fully when the communication fails. In C emulator, correct error in seria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
    [mainprog-firmware.cpp, xbee-firmware.c]
2017-03-17 Firmware update to 1.2. Shift packet error enum to xbee.h for global access.
    [xbee-firmware.c]
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2017-03-30 acqcontrol: close any open connections for a node when ID arrives. This is intended to tackle problem of network failure when nodes experience trouble and restart their XBee. Move Transmit Status con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
    [xbee-acqcontrol.h]
2017-04-05 Modify firmware to add a delay to prevent the AVR from sleeping while counts are changing. Fix arithmetic problem in acqcontrol to display counts correctly.
    [xbee-firmware.c]
2017-04-28 Acqcontrol: Improvement in printout for data packets, including reporting of packet error codes.
    [xbee-acqcontrol.h]
2017-05-05 Minor fix to allow display of processed count/voltage values.
2017-05-26 GUI: correction of problems with query node. Rearrangement of code to make reading easier.
    [xbee-control.h]
2017-05-30 GUI fixed error in querying for XBee response. acqcontrol: improved debug reporting
    [xbee-control.h, xbee-dialog.cpp]
2017-05-31 Firmware: add a GOTO to the second instruction allow the node to soft reset in the event if communication failure, but keeping count value intact.
    [xbee-firmware.c]
2017-06-02 Start development of a command interface for the sleeping XBees. Responds to stayawake command changes but still rather hit and miss. Doesn't always receive the message.
    [mainprog-firmware.cpp, xbee-firmware.c]
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2017-06-08 Serial interrupt test to verify that interrupts work. Transmit ok but while receive works it is sporadic. Doesn't seem to be buffering, something in the reception of serial characters. Was tested on 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
2017-06-22 Acqcontrol: Add a feature to print RSS when data packet received. Firmware: Minor changes to fix makefile error identifying ATMega328
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2017-12-27 Updates to watermeter-count-test and watermeter-echo-test to reflect changes in firmware. Serial routines have been changed to allow direct access to serial I/O for the echo test to avoid interrupts 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
    [watermeter-count-test.c]
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
